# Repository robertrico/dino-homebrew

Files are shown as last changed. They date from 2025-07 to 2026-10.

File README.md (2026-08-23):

# DINO

**D**iscrete **I**ntegrated **N**ISC **O**perator — an 8-bit CPU built from
74-series logic on breadboards. That's the machine itself: no
microcontroller, no FPGA. Every register, every bus, every gate is a chip
you can put a probe on. (The repo does carry a generated FPGA twin for
design-ahead — see `fpga/`.)

Schematics in KiCad, microcode in EEPROM, and a bare-metal ATmega2560 test
rig that brings the machine up one board at a time.

**Status: IT RUNS.** All ten modules and all five integration blocks are
bench-proven, and the machine executes programs at full speed off its own
1.024MHz crystal. The milestone:

```asm
LDAI 0xFF   ; poison OB — destroy the previous answer first
OUT
LDAI 0x2F   ; A = 0x2F
LDBI 0x1E   ; B = 0x1E
ADD         ; A = A + B
OUT         ; LEDs show 0x4D
HALT
```

And it is no longer limited to what is burned into the ROM. `IN` reads the
DIP switches onto the bus, so an operand comes off the bench:

```asm
LDAI 0x2F   ; one addend from ROM
IN          ; the other from SW1
ADD
OUT         ; 0x2F + 0x01 = 0x30, 0x2F + 0x1E = 0x4D
HALT
```

Timing is retired: it free-runs, and "works single-stepped, fails
free-run" never appeared.

**The whole ISA executed on hardware on 2026-08-04** — every coverage image
produced its expected byte on the LEDs. `LDA`, `STA`, `JMP`, `JNZ` and seven
of the eight ALU codes had been burned and policed since the ROMs were first
written and had never once run.

**A stack pointer and a third microcode EEPROM exist in schematic and
simulation as of 2026-08-11** — twelve chips and seven instructions
(`LXISP`, `CALL`, `RET`, `PUSHA/POPA/PUSHB/POPB`), verified in the FPGA twin
and in the Python oracle, **not yet on silicon**. That is the next bench
session. After it: a 16550 UART, then a proto-Monitor.

---

## The part worth reading about

Building a CPU from discrete logic is a known exercise. The interesting
problem is different: **on a breadboard, with 60+ chips and a thousand
jumpers, how do you know the machine you built is the machine you drew?**

The answer here is four layers, each catching what the one before it
cannot:

```
schematic  ──▶  netlist audit  ──▶  generated contracts  ──▶  bench test
 (KiCad)        (gate equations       (pinmaps, ROM images,     (ATmega2560
                 extracted, not        expect models — all       drives real
                 eyeballed)            emitted from the          silicon and
                                       netlist)                  compares)
```

The rule underneath it: **nothing is retyped.** Every table in this repo —
pin assignments, the microcode ROM, the program ROM, the breadboard slot
maps, the wiring guides — is generated from the KiCad netlist by a script
with its own host tests. A schematic change propagates automatically. A
hand-maintained table would drift the moment someone moved a wire, and
drift is invisible until it costs you an evening.

Every test assertion is **netlist-verified before it is written**. Reading
a schematic and typing what you think a gate does is how you write a test
that agrees with your misunderstanding.

### Rules that were paid for on the bench

Each of these exists because something went wrong first:

- **Mirror-witness.** A write-then-read through the same bus bank is
  permutation-blind — a flipped jumper bank cancels itself out. Every
  module needs at least one asymmetric path. This is what finally caught a
  reversed PORTF→MDR bank that every round-trip test had passed.
- **Phantom power.** The rig's driven lines feed the DUT's VCC through
  input clamp diodes, so an unpowered CMOS board reads perfectly fine.
  A deliberate power-off run once scored 7/10. Every module now has a
  `power` test that runs first and holds the rig's outputs at the level
  that sources no current.
- **As-built freeze.** Once a breadboard strip is populated, its slot map
  is copper. Read it off the board and record it verbatim; never renumber
  a strip someone is wiring to.
- **No blind counters.** A failing assertion must print enough detail to
  name the lying signal, or the test is just a rumour.

### Faults this method actually caught

Not hypotheticals — these came off the bench, most diagnosed from serial
logs alone without a scope:

| Fault | How it was found |
|---|---|
| `U18.1` (OE) on `MDR_OUT` instead of `~MDR_OUT` | enable polarity inverted; cascaded into four failing tests until bus-fight analysis fingered it |
| PORTF→MDR jumper bank reversed | invisible to every A/B/C round trip, caught only by the asymmetric OUT-register path |
| `MDR5`↔`MDR6` crossed | decoded from byte 0 arithmetic alone: `0xA5 → 0xC5` is exactly a bit-5/6 exchange |
| Bridge DIR/EN keyed on destination instead of source | schematic bug — ADD could never have committed. Found by netlist audit before the board existed |
| Missing common ground | the all-float scan; first bench rule in action |
| `A8`-`A11` address rotation on the microcode ROM | the address-order test named every rotated line |

The last one matters most: **it was found on paper.** A netlist audit
caught a bridge defect that would have made the milestone program
impossible, before a single wire was cut.

---

## The machine

**8-bit data, 16-bit address.** Microcoded control: a **24-bit control word**
per T-state, stored in **three** EEPROMs addressed by `opcode << 4 | T`.

```
CW23:16  third ROM — bank selects, and room to grow
         CW17 SRC bank   CW18 DST bank   CW19 MISC bank

CW15  HALT           CW11:9   ALU op select (SA2:SA0)
CW14  PC_MAR_MUX     CW8:6    MISC   -> '138  bank 0: PC_CLEAR, PC_LOAD,
CW13  PC_UP                           COND, MDR_OUT, REG_OUT_LOAD,
CW12  END                             SP_UP, SP_DOWN
                     CW5:3    SRC    -> '138  bank 0: ROM, RAM, REG_A/B/C,
                                       ALU, SW
                                       bank 1: SP_LO/HI, PC_LO/HI
                     CW2:0    DST    -> '138  bank 0: REG_A/B/C, MAR_LO/HI,
                                       IR, RAM    bank 1: SP_LO/HI
```

The word was 16 bits and full — `SA(3) + MISC(3) + SRC(3) + DST(3) + END +
PC_UP + MUX + HALT` with two spare MISC codes and nothing else. The third
EEPROM buys bank-select bits rather than a wider field, so **every previously
burned row keeps its meaning**: bank 0 decodes exactly as before.

Instruction set: immediate loads, memory load/store, unconditional and
zero-conditional jumps, eight ALU operations on a '382 pair, an output port,
a switch input, a 16-bit stack pointer with `CALL`/`RET` and push/pop, and
`HALT` at `0xFF` so an erased EEPROM halts instead of raving.

**Adding an instruction costs a three-ROM burn** — a new opcode writes rows
in every byte of the word. Image CRCs are pinned as literals in
`test_microcode_gen.py`, so a reburn is always deliberate.

**Memory:** 32K program ROM and 32K RAM, split at `0x8000`.

**Commit discipline:** everything that changes state is clock-qualified and
commits while the clock is low — register loads through `NOR(~LOAD, CLK)`,
the RAM write pulse through `NAND(WRITE_DIR, ~CLK)`, PC load, clear and
count each gated independently. The consequence is useful: the microcode
ROM's access-time glitch cannot reach anything that holds state, so a
decode glitch here is a power-supply question, never a correctness one.

---

## Layout

```
dino_v0_0_2/          KiCad schematics, one sheet per module
docs/notes/           generators + design notes (see below)
roms/                 the burned EEPROM images — what is in the sockets
fpga/                 the generated VHDL twin, TTL models, cocotb, synthesis
tests/dino_bringup/   the ATmega2560 bring-up rig (bare-metal C)
datasheets/           74-series and memory parts
```

Everything in `docs/notes` that ends in `.py` emits something, and has a
`test_*.py` beside it:

| Script | Emits |
|---|---|
| `kicad_netlist.py` | `build_report()` — the netlist oracle everything else asks |
| `kicad_contracts.py` | per-sheet contracts, pin map, `--continuity` landing lists, `--since` change lists |
| `microcode_gen.py` | the three microcode ROM images, CRCs, expect header |
| `progrom_gen.py` | program ROMs, coverage images, and the Python oracle |
| `roms_readme_gen.py` | `roms/README.md` — the inventory read at the burner |
| `layout_gen.py` | breadboard placement, slot maps, colour-coded wiring guides |
| `fpga_gen.py` | schematic → VHDL, plus simulation hex images |
| `fuzz_gen.py` | differential fuzz seeds, VHDL twin vs the Python oracle |
| `coverage_lint.py` | asserts every contract signal is covered by a testbench |

---

## The FPGA twin

`fpga_gen.py` emits VHDL from the same netlist — `fpga/gen/*.vhd`, never
hand-edited — reproducing the schematic gate for gate, on top of behavioural
models of the actual parts (`fpga/ttl/ttl_74ls373.vhd`, `ttl_74f382.vhd`,
`ttl_at28c256.vhd`, …).

```bash
make -C fpga verify      # ~148s: host suite, differential fuzz, cocotb ladder
```

Every image tag synthesises, places, routes and closes timing on a Lattice
ECP5-5G Versa. `docs/notes/dino_fpga_vplan.md` is the coverage map: 92 rows,
each mapping a claimed invariant to the artifact that would **fail** if it
were wrong, with five gaps named as gaps.

**It cannot see** analog levels, real propagation on breadboard wire,
fan-out, or whether a wire was landed. Those are bench questions and always
will be. The breadboard machine is the machine; the twin is design-ahead.

---

## The bring-up rig

**The rig is currently detached and unwired** — it brought the machine up
board by board and shed its wires as each block was proven, which was always
the plan. Bench verification is now continuity against the generated crossing
list, TL866 read-back, and the coverage images' answers on the LEDs. What
follows is how it works when it is connected.

One firmware image, every test compiled in, selected at runtime over a
serial shell. The rig is stimulus, clock, and analyser.

```
list                  every test, grouped by module
run all               everything wired
run alu               one module
run alu.flags         one test
pins alu              the complete jumper table for that module
```

`pins <module>` **is** the hookup list — it prints from the same generated
tables the firmware resolves at runtime, so the paper and the code cannot
disagree.

### Build

```bash
cd tests/dino_bringup
source env.sh
build && flash && monitor      # avr-gcc, avrdude, screen @115200
```

### Test

```bash
make -C fpga verify                    # everything: host suite, fuzz, cocotb
make -C tests/dino_bringup/hosttest    # C model tests, no hardware needed
```

Individual generators self-test standalone, **run from the repo root** — they
resolve `roms/` relative to themselves, so `cd docs/notes` first and they
will not find it:

```bash
for t in docs/notes/test_*.py; do python3 "$t"; done
python3 docs/notes/coverage_lint.py
```

A few (`test_fpga_gen`, `test_vplan`, `test_netlist_integrity`) need `pytest`
and `cocotb`; `make -C fpga verify` runs them in the project venv.

The C expect models (`*_expect.h`) contain no AVR headers on purpose — the
same logic the rig asserts against is exhaustively tested on the host
first, red before green, long before a board is wired.

---

## How it was brought up

The integration ladder, control unit first, with the rig shedding wires at
every step until it was only watching. **All five blocks were bench-proven by
2026-08-02**; the counts below are current and include the stack sheet:

```
BLOCK             ADDS                          DRIVEN  SAMPLED
BLOCK 1   root + microcode + control_word          8       39
BLOCK 2   + pc + mar + memory                      8       31
BLOCK 3   + mdr        (real IR — it fetches)      0       15
BLOCK 4   + registers + alu + stack                0       15
BLOCK 5   + io                                     0       15
```

The ordering is not arbitrary. Every rig wire is a wire that can be one hole
off, so fewer rig wires means fewer rig-introduced faults — and the control
unit has the highest fan-out in the machine, which makes a rig standing in
for it the most dangerous harness the project could build. Make it real first
and that harness never exists. Driven hits zero at Block 3, when the real
instruction register takes over the fetch.

Blocks are **black-box** tests: a signal is sampled only if its value depends
on more than one board in the block. Anything one module already determines
is retired to that module's test, and anything produced inside the block and
consumed inside it is copper the rig never touches.

Nothing is ever pulled — no chip leaves its socket and the crystal stays
seated throughout — so the rig never owns the clock and every block runs free
at 1.024MHz, captured in bursts rather than single-stepped.

### The blind spot that cost a day

That last sentence contains the flaw. **Copper is driven by no test and
sampled by no test.** A module test drives those nets from the rig's own
pins, so the board-to-board run is never needed and cannot fail; the block
ladder classifies them as copper and never looks. **The wire between two
proven modules was checked by nothing.**

Two runs — nine wires — turned out never to have been landed at all, and
every element around them measured perfectly correct the entire time. The
fix is generated, not remembered:

```bash
python3 docs/notes/kicad_contracts.py --continuity U63 U64 U65 U66 ...
python3 docs/notes/kicad_contracts.py --since HEAD~1
```

The first prints every pin a named chip needs landed. The second prints what
changed, classified — and it is not optional, because the continuity walk
filters to nets touching the *new* chips, so a lifted strap on an existing
pin is invisible to it. Two blind spots in that tool itself were found and
regression-tested in `test_continuity_completeness.py`; one of them had been
dropping the ROM chip-enable from every checklist ever produced.

## What is left

```
land the stack   73 nets, 154 pins, plus 6 copper changes and 2 new wires
burn three ROMs  U9, U15, U23
PROG_sp          SP alone — LXISP and the counter, no CALL/RET
PROG_stack       push/pop, LIFO order observable
then             CALL/RET on hardware, a 16550 UART, a proto-Monitor
```

Bench procedure, per-stage wiring, failure meanings, and the full
integration plan live out of tree with the rest of the process documents
(maintainer's `.git/sdd/`).

---

*Schematic PDF: [`dino_v0_0_2/dino_v0_0_2.pdf`](dino_v0_0_2/dino_v0_0_2.pdf)*

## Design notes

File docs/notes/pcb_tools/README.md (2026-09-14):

# pcb_tools — the placer scripts from the 2026-09-12 layout session

Promoted verbatim from a session scratchpad on 2026-09-14 so the DMA/INT
re-shuffle has them. **Throwaway quality: no tests, absolute paths,
constants hard-coded for the 77-DIP / 14-column / 6-row board.** Read
`.git/sdd/PCB_LAYOUT.md` RESULTS R2 and `.git/sdd/TO_PCB.md` (volume
checkout) before running any of them. They only READ `.kicad_pcb`;
placements are applied through Konnect `set_component_placements`.

    anneal.py  <out.json> [seed]   simulated annealing over DIP cell
                                   assignment; cost = HPWL with CLK x6,
                                   ~CLK x4, CLK_B x6, Y1->U20 x6, RC x5.
                                   `ROWH`, `cells`, `chips==77` assert and
                                   the fixed-part table need editing for
                                   a board with U80-U99 added.
    hpwl.py    <pcb> [n]           per-net HPWL of the SAVED board, worst n
    report.py  <placements.json>   CLK/RST/PC6 spans + courtyard overlaps
                                   for a placements file before applying
    place_sheetrows.py             the FIRST placer (sheet rows). Superseded
                                   by anneal.py; kept for the cap-pairing
                                   and front-panel geometry it encodes.

Pipeline: anneal -> report -> Konnect set_component_placements ->
score_placement -> docs/notes/test_pcb_envelope.py -> pcbnew DSN export
-> Freerouting -> KiCad SES import -> hairpin sweep -> pours -> DRC.

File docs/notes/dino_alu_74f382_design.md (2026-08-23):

# DINO ALU hardware: 2x 74F382 design notes

Machine: DINO v0.0.3, `dino_v0_0_2/alu.kicad_sch`
Status: **BUILT AND BENCH-PROVEN.** Architecture converged 2026-07-13
(shadow-register operands, Rico's design); drawn, wired, and all eight SA
codes executed on hardware 2026-08-04 via `PROG_alu` (OB 0x39). This document
is the DESIGN RECORD for how it got that way, kept so the rejected
alternatives never get re-litigated from scratch.

Companion still in tree: `dino_design_notes.md` (the operand-architecture
decision record). `dino_121_elimination_plan.md` and
`dino_register_conversion.md` are process documents and live out of tree in
`.git/sdd/`.

---

## 0. Architecture summary

Two 74F382 4-bit ALU slices cascade to 8 bits. Operands come from two SHADOW
REGISTERS on this sheet — TMP_A and TMP_B, '373s whose D pins listen on the
W bus and whose latch enables fire on the same decodes as REG_A and REG_B.
Every dst=A state loads A and TMP_A identically; TMP_x ≡ REG_x by
construction. The F382s read the shadows point-to-point (Q → ports, one
driver, one listener, no buffers). The register boards are untouched and the
ALU adds no cross-board operand wiring: everything rides the W bus backbone.

An ALU instruction is one execute state: select the function, output latch
freezes the result at the mid-state falling edge, destination (and its
shadow) capture on the closing edge. No staging states, no control codes
spent on the shadows.

History (see design_notes for full rationale): dedicated always-driven taps
rejected (required tearing up verified register topology + 16 cross-board
wires); 8008-style microcode-addressable temps rejected (2 staging states +
both free [8:6] codes). Shadows take the best of both.

## 1. The function table ([11:9], constitution-final)

DATASHEET READING TRAP: the '382 select table prints columns S0, S1, S2
left-to-right - LSB FIRST. Read carefully. Also old notation: A(+)B circled
is XOR; "A + B" in the logic rows is OR; "A Plus B" spelled out is ADD; AB is AND.

Corrected mapping, written S2:S1:S0 as the control word holds it:

    [11:9]  S2 S1 S0   op              instruction
     000     L  L  L   Clear           CLR   A = 0x00   (free)
     001     L  L  H   B minus A       BSUB  A = B - A  (free)
     010     L  H  L   A minus B       SUB   A = A - B
     011     L  H  H   A plus B        ADD   A = A + B
     100     H  L  L   A XOR B         XOR
     101     H  L  H   A OR B          OR
     110     H  H  L   A AND B         AND
     111     H  H  H   Preset          SET   A = 0xFF   (free)

("A" and "B" here mean TMP_A and TMP_B — identical to REG_A/REG_B by the
shadow invariant.)

Casualties from the old paper table: DISABLED (the '382 has no disabled
state; S=000 computes zero - "ALU quiet" is the output latch's job), PASS
(no such '382 function; src=REG_A covers it), COND (relocated to [8:6]=011).

WIRING: control word bit 11 -> S2, bit 10 -> S1, bit 9 -> S0, both slices in
parallel. A swapped select line maps every op to a DIFFERENT VALID OP - the
nastiest miswire class. See section 7 test 1 for the disambiguator.

## 2. Shadow registers TMP_A, TMP_B (the operand source)

    TMP_A 74LS373
      D0-D7   = W bus, direct (inputs are listeners — no buffer needed;
                IR does exactly this on the verified MDR/IR sheet)
      Q0-Q7   = F382 A ports (low slice bits 0-3, high slice 4-7),
                point-to-point wires, OE = GND
      LE      = NOR(/REG_A_LOAD, CLK) — own stamp gate on this sheet,
                same input NETS as the register board's LE_A stamp
    TMP_B: identical, /REG_B_LOAD, F382 B ports.

SHADOW INVARIANT: TMP_x captures on EVERY dst=x state including ALU
writebacks (A and TMP_A latch the same frozen W on the same edge). Chained
arithmetic depends on this — a shadow that skipped writebacks would feed
the next SUB stale operands. Both registers are garbage before the first
load, same as v0.0.2 semantics; microcode loads before it computes.

Trade accepted: the ALU computes on A,B only. Any-pair ops (ADD B,C) are a
MOV-through idiom in microcode. Accumulator-machine standard.

## 3. Cascading two slices

- Low slice: bits 0-3 of TMP_A, TMP_B, F. High slice: bits 4-7.
- Low slice Cn+4 (ripple carry out) -> high slice Cn.
- High slice Cn+4 -> C input of the flags '173 (section 5).
- High slice OVR = signed overflow (V flag) - free; route it somewhere
  probeable now, unreachable after layout.
- Low slice Cn = carry-in for the whole 8-bit ALU (section 4).
- F-family speed: ~15ns full 8-bit result. The EEPROMs own the ceiling.
- F inputs are TTL-compatible with LS drivers; keep F-to-latch traces short.

## 4. Carry-in (Cn) - op-dependent, not optional

The '382 computes subtraction as A + /B + Cn. Therefore:
    SUB (010) and BSUB (001) REQUIRE Cn = 1; ADD (011) wants Cn = 0;
    logic ops ignore Cn.

    Cn = XOR(S1, S0) = XOR(bit10, bit9)

Check: 001 -> 1 ok. 010 -> 1 ok. 011 -> 0 ok. Logic rows: don't-care.
Hardware: one XOR — 4x NAND spares or a new '86 (spares useful for flags).
Wire to LOW slice Cn only; high slice Cn comes from the cascade.
FUTURE parking: ADC/SBC = mux stored C into Cn. Only if multi-byte speed
ever matters.

## 5. Flags register ('173, falling-edge capture)

    C <- high slice Cn+4;  Z <- NOR8 of F382 F pins;  V <- OVR (free bit)

    74LS173: CP = /CLK (rising of /CLK = mid-state falling edge of CLK),
    /IE = /ALU_OUT, output OEs grounded (flags feed dedicated COND logic).

WHY THE FALLING EDGE: in the second half of an ALU state TMP_A goes
transparent (it shadows dst=A) and the F382 recomputes ~40ns later — C/V go
stale. At the falling edge the F pins still reflect old operands (the value
being committed). Setup: F settled ~200ns into the first half. Hold: ~40ns
before F can move vs ~10ns required.

CAPTURE RULE: flags capture ONLY when src=ALU, ON the falling edge. With no
DISABLED code the S pins always compute something; ungated capture would
clobber Z between SUB and JNZ. Constitution header: "ALU ops (src=ALU
states) update Z and C (and V if wired) at the falling edge; nothing else
touches flags."

Z-detect gate choice still open: 'LS260+gate, 2x 'LS25+AND, or 'LS30 games.
Pick by spares; record here: ____________

## 6. Output latch (the ALU sheet's only bus driver)

'382 F outputs have no tri-state; a buffer was always required. It is a
74LS373 — buffer + the master latch that breaks the writeback loop:

    D = F[7:0];  LE = CLK, DIRECT (zero gates);  Q = W bus
    /OE = /ALU_OUT ([5:3]=110, U28 — verify designator/pin on control
          sheet and record: ____________)

Transparent the whole first half (tracks F while shadows are stable),
freezes at the falling edge, holds through the second half while the
destination AND its shadow track the frozen value.

MASTER/SLAVE INVARIANT: output latch transparent iff CLK HIGH; every
destination latch (registers and shadows) transparent iff CLK LOW; never
both. During ADD's second half, TMP_A tracks the frozen W, the F382
recomputes from new TMP_A, and hits this closed latch. The loop always
contains one closed door. In non-ALU states the latch captures whatever
[11:9] computes behind a disabled /OE - ripple nobody samples.

MICROCODE IMPACT: none. ADD = T0 (0x600E) + T1 (0x1631). Timing rule: ALU
result must settle by the FALLING edge — '163 (~14) + EEPROM (~150) + F382
(~15) + latch (~18) ≈ 200ns vs 500ns half-period at 1MHz.

## 7. Bring-up test plan (jumper-driven, no microcode EEPROM required)

Fixture: force TMP_A/TMP_B via the W-bus switch rig + manual stamp inputs
(or DIP switches on the shadow D nets), LEDs on W bus, S pins jumpered.
For tests 1-5, hold CLK HIGH so the output latch is transparent.

1. DIRECTION ANCHORS FIRST: S=000 -> W reads 0x00; S=111 -> 0xFF. Catches
   swapped or stuck select lines before any arithmetic is trusted.
2. ADD: 0x05+0x03 -> 0x08. Then 0xFF+0x01 -> 0x00 with C set (cascade and
   carry capture in one shot).
3. SUB: 0x05-0x03 -> 0x02; RECORD observed carry polarity on subtract
   (/borrow expected) and define JC semantics in the constitution: ________
4. BSUB: same operands -> 0xFE.
5. XOR/OR/AND: one vector each, e.g. A=0xAA B=0x0F -> 0xA5 / 0xAF / 0x0A.
6. Z FLAG: a zero result sets Z; nonzero clears; Z must NOT change when
   src != ALU (capture gate working).
7. LATCH HALVES: /ALU_OUT=0. CLK high: wiggle operands -> W follows.
   CLK low: wiggle -> W FROZEN. Master/slave on two probes.
8. SHADOW INVARIANT: wire to the real register boards; run LDAI, ADD, LDA
   sequences single-stepped; probe TMP_A vs REG_A after every edge — always
   equal after any dst=A state, INCLUDING the ADD writeback.
9. FEEDBACK SAFETY: single-step ADD with B=1 — A increments by EXACTLY 1
   per state. A jump >1 means a transparent path survived.
10. FLAGS EDGE: flags move only on falling edges of src=ALU states.

## 8. Open questions (decide before drawing the sheet)

1. RESOLVED (drawn, netlist-audited 2026-07-13): Z-detect is NOT '260/'25/'30
   — no '260 in stock. Built from De Morgan identity using ONLY 2-input
   gates already on the sheet: NOT(x1|x2|x3|x4) = NOR(x1,x2) AND NOR(x3,x4).
   U52 (quad '02): F01=NOR(F0,F1), F23=NOR(F2,F3), F45=NOR(F4,F5),
   F67=NOR(F6,F7) — all 4 gates used. U53 (quad '08): F0123=AND(F01,F23),
   F4567=AND(F45,F67), Z=AND(F0123,F4567) — 3 of 4 gates used, 1 spare.
2. RESOLVED: flags storage is '273, NOT '173 — no '173 in stock. '273 has
   no load-enable pins (unlike '173's M/N), so a 74LS157 (quad 2:1 mux, U48)
   sits ahead of the D inputs: I0=new flag value, I1=Q fed back to itself,
   S=/ALU_OUT direct (active-low S selects I0 during a real commit — no
   inverter needed, get the I0/I1 assignment backwards and flags freeze on
   every IDLE cycle instead of every ALU cycle). CP=/CLK (unchanged reasoning
   from below), Mr=/RESET (74LS273 has async active-low clear — a genuine
   upgrade over '173, costs nothing). V flag wired (FLAG_V, ALU_V from high
   slice OVR) — yes, wired now, per the original "free if wired now" note.
3. SUB borrow polarity -> JC/JNC semantics (section 7 test 3) — still open,
   needs bench observation, unchanged.
4. Output latch part SETTLED ('373); /ALU_OUT designator = U47's /OE,
   confirmed on the drawn sheet.
5. RESOLVED: Cn is NOT built from XOR/'86 — turns out you don't need XOR at
   all. Required truth table only constrains 3 of 4 (SA1,SA0) pairs (CLR is
   don't-care, Cn doesn't touch a clear op), and NAND(SA1,SA0) satisfies all
   three (BSUB=1, SUB=1, ADD=0) — XOR and NAND only differ at (0,0), which is
   exactly the don't-care slot. Built from a spare AND gate (U53, 4th gate,
   pins 12/13->11, was dead/grounded) feeding a spare NOR-as-inverter (U50,
   4th gate, pins 11/12 tied together ->13) — zero new chips. Net:
   ALU_CIN = NOR(AND(SA1,SA0), AND(SA1,SA0)) = NAND(SA1,SA0).
6. Do BSUB/CLR/SET earn opcodes in v0.0.3, or stay documented-but-unassigned?
   Still open — not touched this session; the control word's [11:9] field
   wires straight to SA[2:0] either way, so this is a microcode-assignment
   decision, not a hardware one.

Full pin-level wiring for all of the above: see dino_session_state.md,
"ALU sheet (COMPLETE)".

---

Sequencing: register boards get stamps + '08 (small diff, conversion doc §2),
then this sheet gets drawn — 2x F382, TMP_A, TMP_B, output latch, flags '173,
Cn XOR, Z-NOR — and the machine can ADD TWO NUMBERS AND SHOW THEM, one bench
session from the countdown demo.

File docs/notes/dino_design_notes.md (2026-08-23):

# DINO design notes: deferred decisions and settled philosophy

Running notes for decisions that are settled in principle but not yet (or not
ever) implemented in hardware — kept so the rejected alternatives never get
re-litigated from scratch. Some entries here HAVE since been built; each says
so. Companion to `dino_alu_74f382_design.md` and, out of tree, `.git/sdd/`.

---

## ALU operand architecture (FINAL 2026-07-13): shadow registers

Three candidates were worked through in conversation; recording all three so
this never gets re-litigated from scratch.

REJECTED — dedicated taps ("spatial"): ground register OEs so A Bus/B Bus are
always driven, ALU taps them point-to-point. Sound, but tears up the verified
v0.0.2 register topology (D pins move to the W bus, '245s become one-way) and
strings ~16 operand wires across boards. Died on: rewiring cost + mental-model
mismatch.

REJECTED — microcode-addressable temps ("temporal", pure 8008): TMP_A/TMP_B
loaded by explicit microcode via the two free [8:6] codes. Registers keep
v0.0.2 wiring; feedback hazard vanishes; any-pair ALU ops. Died on: 2 staging
states per ALU op AND spending both free misc codes — the last expansion room
in that field.

ADOPTED — SHADOW REGISTERS (Rico's synthesis): TMP_A/TMP_B '373s on the ALU
sheet, D pins listening on the W bus, latch enables fired by the SAME
/REG_A_LOAD//REG_B_LOAD decodes as the real registers. Every dst=A state
loads A and TMP_A with the same value on the same edge: TMP_x ≡ REG_x by
construction. Zero control codes, zero staging states, zero register-board
rewiring, no cross-board operand wires (everything rides the W bus backbone).

INVARIANT (do not "optimize"): shadows capture on EVERY dst=x state INCLUDING
ALU writebacks. A shadow that skipped writebacks goes stale and breaks chained
arithmetic (countdown loop: SUB;JNZ;SUB must see current A). Both real and
shadow are garbage before first load — same as v0.0.2 semantics.

Feedback safety: during an ALU writeback's second half TMP_A is transparent
and feeds the F382 — the loop is broken by the ALU OUTPUT LATCH (LE=CLK,
master/slave), not by the shadows. The output latch was required anyway as
the '382s' bus buffer.

Trade accepted: ALU computes on A,B only; ADD B,C = MOV-through idiom.
Revisit trigger: if register pressure makes MOV-through painful (monitor/
toolchain era), the temporal design's staging codes are the upgrade path —
and by then a third parallel EEPROM (control word +8 bits, same addresses)
is a reasonable ask.

## Illegal microword defense (settled 2026-07-12, revisit at monitor/toolchain era)

The two-field encoding leaves one expressible-but-illegal class: src and dst naming
the same device. Register self-copy (src=REG_x, dst=REG_x) is benign - a wasteful
NOP, A=A (the '245 turns around, the latch recaptures its own value; shadows
recapture identically). RAM self-copy (src=RAM_OUT, dst=RAM_LOAD) is a REAL
corruption: /WE dominates /OE on SRAM, the chip stops driving mid-state, and the
write commits whatever the abandoned bus floats to. Garbage written to [MAR].

SECOND expressible-but-illegal class (caught 2026-07-12, Rico's contention
review of the '245 fleet): the six W-bus source enables (/ROM_OUT, /RAM_OUT,
/REG_A/B/C_OUT, /ALU_OUT) all come from U28 - one-hot by silicon, two W-bus
drivers UNREPRESENTABLE within the src field. But /MDR_OUT (replay) lives on
U29, the misc-field '138. A word asserting [8:6]=100 (/MDR_OUT) together with
any [5:3] != NONE puts TWO drivers on the W bus. The silicon cannot exclude
it; the builder must (assert below). Same defense philosophy: the only
source of such a word is EEPROM contents.

Considered and REJECTED: hardware interlock (e.g. OR-ing a detected illegal state
into HALT). Reasons:
- The detector would watch decode lines whose ripple the whole design is built to
  ignore; a level-family signal feeding the clock stop mixes the edge/level
  categories and creates a new false-halt failure mode.
- The only source of an illegal word is EEPROM contents; the builder already
  refuses to emit one. Hardware would defend against corrupted burns only, and
  burn verification (programmer readback) covers that directly.
- A flipped bit in a LEGAL row (ADD becomes OR) is undetectable by any interlock
  anyway - the defense has to live upstream of the silicon regardless.

ADOPTED: four layers, zero gates, each defense where it is cheapest:
1. STRUCTURE  - field encoding: bus fights unrepresentable.
2. POLICY     - C microcode builder asserts (list below).
3. RECOVERY   - safe-fill: every unwritten microcode row = NOP+END (0x1000),
                so any runaway lands on a fetch within one state.
4. VERIFICATION - Arduino contract tests per sheet; EEPROM burn readback/verify
                every burn.

Revisit trigger: when the toolchain era arrives (assembler, monitor, self-hosted
EEPROM writes), the POLICY layer moves partly into those tools - the monitor's
EEPROM-write path should enforce the same asserts as the offline builder, or
self-hosted microcode updates lose layer 2.

## Builder assert list (grows as the constitution grows)

- src device == dst device -> ERROR (RAM case corrupts; register case pointless)
- src == REG_x AND dst == same REG_x -> WARNING (probable MOV typo)
- [8:6] == /MDR_OUT AND [5:3] != NONE -> ERROR (two W-bus drivers: replay
  path enables MDR's OE from U29, outside the U28 one-hot guarantee)
- PC_UP AND PC_LOAD same word -> ERROR (defined-but-fragile on '193 internals)
- opcode block with no END before T15 -> ERROR (instruction runs into safe-fill)
- total PC_UP count per instruction != instruction byte length -> WARNING
  (catches operand-skip / double-fetch bugs at build time)
- any word asserting IR_LOAD outside T0 -> ERROR (IR changes only at fetch)
- T0 row of every opcode != universal fetch word 0x600E -> ERROR

## Deferred hardware, parking spaces reserved

- ADC/SBC: mux stored C flag into ALU Cn (replaces XOR-derived constant).
  Requires nothing else. Only if multi-byte arithmetic speed ever matters.
- MAR upgrade '373s -> '163s: buys MAR++ for indirect addressing era. Sheet
  layout should leave room. Would want a misc-field code or a third-EEPROM
  control bit for the count strobe.
- Indirect addressing: pointer-walk microcode with byte buffer (REG_C clobber,
  documented) or hidden temp '373. Hazard walk already done - see conversation
  notes 2026-07-11: last byte read must be first byte committed.
- IN port: '244/'541 from outside world onto W bus, source code [5:3]=111 (the
  reserved slot). Prerequisite for the monitor. When wired, its enable joins
  the U28 one-hot family - structurally safe, no new assert needed.
- COND qualifier gate: [8:6]=011 decode gates PC_LOAD (and optionally END) on
  selected flag. Flag-select encoding not yet designed - decide when JNZ is
  wired whether Z-only suffices for v0.0.3 (it does for the countdown demo).
- Third parallel EEPROM: +8 control word bits on the same address lines —
  the standing relief valve if [8:6] ever fills (monitor strobes, MAR++,
  flag-select).

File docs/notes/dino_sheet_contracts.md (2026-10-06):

# DINO sheet-to-sheet contracts

Generated by docs/notes/kicad_contracts.py — regenerate after any
schematic change; do not hand-edit. Direction is derived from pin
types: OUT(tri) means drives-when-enabled (a tri-state bus driver).

## root
- IN    END_OR_ACCEPT  <- Interrupt
- IN    CW15=HALT  <- Microcode_Decoder
- OUT   CLK  -> ALU Module, Control Word Module, Interrupt, Memory, Memory Address Regiser, Memory Data Register, Program Counter, Register Modules, Stack Pointer
- OUT   ~{RESET}  -> ALU Module, Interrupt
- OUT   ~{CLK}  -> ALU Module, Interrupt, Memory Data Register, Peripheral Bus, Program Counter
- OUT   ~{TO0}  -> Control Word Module
- OUT   RESET  -> Memory, Program Counter
- OUT   T0-3  -> Microcode_Decoder

## ALU Module
- IN    ~{ALU_OUT}, ~{REG_A_LOAD}, ~{REG_B_LOAD}  <- Control Word Module
- IN    FLAG_D0-3  <- Interrupt
- IN    CLK_ALU  <- Memory Data Register
- IN    CW10=SA1, CW11=SA0, CW16=~{CIN_SEL}, CW21=FLAG_SEL0, CW9=SA2  <- Microcode_Decoder
- IN    CLK, ~{CLK}, ~{RESET}  <- root
- OUT   COND_FLAG  -> Control Word Module
- OUT   FLAG_C, FLAG_N, FLAG_NEXT0-3, FLAG_V, FLAG_Z  -> Interrupt
- BIDIR W0-3  <-> Front Panel, Interrupt, Memory Address Regiser, Memory Data Register, Peripheral Bus
- BIDIR W4-7  <-> Front Panel, Memory Address Regiser, Memory Data Register, Peripheral Bus

## Control Word Module
- IN    COND_FLAG  <- ALU Module
- IN    INJECT  <- Interrupt
- IN    CW0-8, CW17=~{SRC_BANK}, CW18=~{DST_BANK}  <- Microcode_Decoder
- IN    CLK, ~{TO0}  <- root
- OUT   ~{ALU_OUT}  -> ALU Module, Memory Data Register
- OUT   ~{REG_A_LOAD}, ~{REG_B_LOAD}  -> ALU Module, Register Modules
- OUT   ~{FLAGS_LOAD}, ~{FLAGS_OUT}, ~{IE_CLR}, ~{IE_SET}, ~{KONST}  -> Interrupt
- OUT   WR_GATE  -> Memory
- OUT   ~{MAR_HI_LOAD}, ~{MAR_LO_LOAD}  -> Memory Address Regiser
- OUT   SRC_ACTIVE, ~{IR_LOAD}, ~{MDR_OUT}, ~{PC_HI_OUT}, ~{PC_LO_OUT}, ~{RAM_LOAD}, ~{RAM_OUT}, ~{ROM_OUT}  -> Memory Data Register
- OUT   ~{PC_CLEAR}, ~{PC_LOAD}  -> Program Counter
- OUT   ~{REG_A_OUT}, ~{REG_B_OUT}, ~{REG_C_LOAD}, ~{REG_C_OUT}, ~{REG_OUT_LOAD}  -> Register Modules
- OUT   ~{SP_DOWN}, ~{SP_HI_LOAD}, ~{SP_HI_OUT}, ~{SP_LO_LOAD}, ~{SP_LO_OUT}, ~{SP_UP}  -> Stack Pointer

## Front Panel
- IN    W0-7  <- ALU Module, Memory Data Register
- IN    OB0-7  <- Register Modules

## Interrupt
- IN    ~{IRQ}  <- 
- IN    FLAG_NEXT0-3  <- ALU Module
- IN    W0-3  <- ALU Module, Memory Data Register
- IN    ~{FLAGS_LOAD}, ~{FLAGS_OUT}, ~{IE_CLR}, ~{IE_SET}, ~{KONST}  <- Control Word Module
- IN    CW12=END, CW13=PC_UP, CW15=HALT  <- Microcode_Decoder
- IN    CLK, ~{CLK}, ~{RESET}  <- root
- OUT   FLAG_C, FLAG_D0-3, FLAG_N, FLAG_V, FLAG_Z  -> ALU Module
- OUT   INJECT  -> Control Word Module
- OUT   MDR0-7  -> Memory, Memory Data Register, Register Modules, Stack Pointer
- OUT   PC_UP_GATED  -> Program Counter
- OUT   END_OR_ACCEPT  -> root

## Memory Address Regiser
- IN    W0-7  <- ALU Module, Memory Data Register
- IN    ~{MAR_HI_LOAD}, ~{MAR_LO_LOAD}  <- Control Word Module
- IN    CW14=PC_MAR_MUX  <- Microcode_Decoder
- IN    CLK  <- root
- OUT   ~{RAM_EN}  -> Memory, Memory Data Register
- OUT   M0-14  -> Memory, Peripheral Bus, Program Counter
- OUT   ~{PC_MAR_MUX}  -> Program Counter
- BIDIR M15  <-> Memory, Peripheral Bus, Program Counter

## Memory Data Register
- IN    SRC_ACTIVE, ~{ALU_OUT}, ~{IR_LOAD}, ~{MDR_OUT}, ~{PC_HI_OUT}, ~{PC_LO_OUT}, ~{RAM_LOAD}, ~{RAM_OUT}, ~{ROM_OUT}  <- Control Word Module
- IN    ~{IO_RD}, ~{ROM_SEL}  <- Memory
- IN    ~{RAM_EN}  <- Memory Address Regiser
- IN    CLK, ~{CLK}  <- root
- OUT   CLK_ALU  -> ALU Module
- OUT   RAM_OE_ON, READS_IDLE, WRITE_DIR, ~{ROM_BUF_EN}  -> Memory
- OUT   IRB0-7  -> Microcode_Decoder
- OUT   PC0-15  -> Program Counter
- BIDIR W0-3  <-> ALU Module, Front Panel, Interrupt, Memory Address Regiser, Peripheral Bus
- BIDIR W4-7  <-> ALU Module, Front Panel, Memory Address Regiser, Peripheral Bus
- BIDIR MDR0-7  <-> Interrupt, Memory, Register Modules, Stack Pointer

## Memory
- IN    WR_GATE  <- Control Word Module
- IN    ~{RAM_EN}  <- Memory Address Regiser
- IN    M0-15  <- Memory Address Regiser, Program Counter
- IN    RAM_OE_ON, READS_IDLE, WRITE_DIR, ~{ROM_BUF_EN}  <- Memory Data Register
- IN    CLK, RESET  <- root
- OUT   MDR0-7  -> Interrupt, Memory Data Register, Register Modules, Stack Pointer
- OUT   ~{IO_RD}, ~{ROM_SEL}  -> Memory Data Register
- OUT   RESET_B, ~{IO_RD_Q}, ~{IO_SEL}, ~{IO_WR}  -> Peripheral Bus

## Microcode_Decoder
- IN    IRB0-7  <- Memory Data Register
- IN    T0-3  <- root
- OUT   CW10=SA1, CW11=SA0, CW16=~{CIN_SEL}, CW21=FLAG_SEL0, CW9=SA2  -> ALU Module
- OUT   CW0-8, CW17=~{SRC_BANK}, CW18=~{DST_BANK}  -> Control Word Module
- OUT   CW12=END, CW13=PC_UP  -> Interrupt
- OUT   CW15=HALT  -> Interrupt, root
- OUT   CW14=PC_MAR_MUX  -> Memory Address Regiser

## Peripheral Bus
- IN    ~{IRQ}  <- 
- IN    W0-7  <- ALU Module, Memory Data Register
- IN    RESET_B, ~{IO_RD_Q}, ~{IO_SEL}, ~{IO_WR}  <- Memory
- IN    M0-15  <- Memory Address Regiser, Program Counter
- IN    +12V, +3.3V, -12V  <- Power
- IN    ~{CLK}  <- root

## Power
- OUT   +12V, +3.3V, -12V  -> Peripheral Bus

## Program Counter
- IN    ~{PC_CLEAR}, ~{PC_LOAD}  <- Control Word Module
- IN    PC_UP_GATED  <- Interrupt
- IN    ~{PC_MAR_MUX}  <- Memory Address Regiser
- IN    CLK, RESET, ~{CLK}  <- root
- OUT   PC0-15  -> Memory Data Register
- OUT   M0-15  -> Memory, Memory Address Regiser, Peripheral Bus

## Register Modules
- IN    ~{REG_A_LOAD}, ~{REG_A_OUT}, ~{REG_B_LOAD}, ~{REG_B_OUT}, ~{REG_C_LOAD}, ~{REG_C_OUT}, ~{REG_OUT_LOAD}  <- Control Word Module
- IN    CLK  <- root
- OUT   OB0-7  -> Front Panel
- OUT   MDR0-7  -> Interrupt, Memory, Memory Data Register, Stack Pointer

## Stack Pointer
- IN    ~{SP_DOWN}, ~{SP_HI_LOAD}, ~{SP_HI_OUT}, ~{SP_LO_LOAD}, ~{SP_LO_OUT}, ~{SP_UP}  <- Control Word Module
- IN    CLK  <- root
- BIDIR MDR0-7  <-> Interrupt, Memory, Memory Data Register, Register Modules

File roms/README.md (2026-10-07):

# roms/ — what is physically in the sockets

**GENERATED by `docs/notes/roms_readme_gen.py`. Do not hand-edit.**
Regenerate after any image change; `test_roms_readme.py` fails on drift.

These binaries are TRACKED ON PURPOSE. They were silently untracked in the
old `hardware` repo, swallowed by a bare `*.bin` rule inherited from the MCU
firmware projects. Do not reintroduce that rule — see `.gitignore`.

They are regenerable, but regenerable is not recorded. "What was burned on
2026-07-26" should be a `git show`, not "check out an old commit, re-run the
generator, and hope OPCODES has not moved." Per-image history is deliberately
NOT repeated here — that is what `git log roms/` is for.

## Microcode — THREE chips

The control word is 24 bits wide and every image is the 4096-row table split
by byte. A12 is grounded, so each 8KB file is the 4096-byte image mirrored
twice; the CRCs below are over the 4096 ADDRESSABLE bytes.

**Adding or changing an INSTRUCTION means burning all three.** A new opcode
writes rows in every byte of the word. `U9`/`U15` stay untouched only for
changes confined to `CW16-23`.

    IMAGE            BITS      SET    CRC16
    U9.bin           CW0-7     REAL   0x4102
    U15.bin          CW8-15    REAL   0x9BC4
    U23.bin          CW16-23   REAL   0x8A40
    U9_diag.bin      CW0-7     DIAG   0x0F69
    U15_diag.bin     CW8-15    DIAG   0xF1B9
    U23_diag.bin     CW16-23   DIAG   0x56CC

## Program ROM (AT28C256, 32KB, ROM 0x0000-0x7FFF)

    IMAGE            CRC16   WHAT IT IS
    PROG.bin         0x8577  the milestone program
    PROG_diag.bin    0xDFE7  address self-proof, content-addressed

    milestone: LDAI 0xFF; OUT; LDAI 0x2F; LDBI 0x1E; ADD; OUT; HALT  -> OB = 0x4D
    The leading LDAI/OUT POISONS OB: U35 has no reset and the
    machine free-runs at power-up, so OB always already holds
    the previous answer. Safe-filled with HALT (0xFF).

## Progressive ISA-coverage images

The block ladder proves the machine EXECUTES. These prove it executes the
WHOLE of the current ISA. Each ends `OUT; HALT` because OB is the only
datapath observable on the ladder, and every answer is a MIRROR-WITNESS — its
bit-reversed read is a different byte, so a flipped OB ribbon names itself.

Expected OB values are NOT hand-computed. `progrom_gen.simulate()` interprets
the burned microcode rows, so image and hardware cannot disagree by
construction — no eleventh table.

    IMAGE            CRC16   OB    ENDS
    PROG_probe.bin   0x254E  0x39  2
        immediate -> A -> OB, ALU out of the path entirely. The smallest
        question worth asking.
    PROG_adda.bin    0xAC3D  0x39  4
        TMP_A alone: value + 0, so the answer IS the operand.
    PROG_addb.bin    0x8DAE  0x39  4
        TMP_B alone: 0 + value, isolating the other shadow latch.
    PROG_dip.bin     0xFEE3  0x4D  6   SW1 = 0x1E
        THE INTERACTIVE ONE, through the BUS. A comes off card zero at
        0x4000 with a plain LDA -- SW1 is an ADDRESS now, not a SRC code,
        and IN retired with U28.7. Only the SOURCE of the operand changed;
        the answer is still the milestone's 0x4D.
    PROG_alu.bin     0x642A  0x39  13
        all eight SA codes CHAINED, so a wrong code corrupts the signature
        rather than being masked by a later op.
    PROG_mem.bin     0x3E4B  0xC5  5
        STA then LDA back through RAM. Uses ONE address twice, so it is
        blind to what that address actually was -- see mardisc.
    PROG_flow.bin    0xCED0  0x39  7
        JMP over a poison HALT, then a JNZ that must NOT be taken.
    PROG_loop.bin    0x8727  0x15  33
        the JNZ TAKEN arm, iterated an exact number of times. A wrong
        count changes the answer, so the answer proves the count.
    PROG_mardisc.bin 0x2066  0x6B  8
        TWO DIFFERENT MAR values. Reads back the FIRST of two cells
        differing only in MAR_LO, so a collapsed low byte returns the
        SECOND value. The question mem cannot ask.
    PROG_pads.bin    0x749A  0x40  5
        the PC's LANDING ADDRESS as the observable. Every 4-byte slot is
        LDAI <own address>; OUT; HALT.
    PROG_sp1.bin     0x5F58  0x2C  5
        ONE push, ONE pop -- the fewest moving parts that reach the stack
        at all. BLIND TO A FROZEN SP by construction: push and pop use the
        same cell, so 0x2C comes back whether or not SP ever moved. It
        reported a green machine for most of 2026-08-24. Read it only
        alongside sp2.
    PROG_sp2.bin     0xFBA3  0x53  9
        the ADDRESS as the observable, not the data. Plants a sentinel in
        the cell push #2 must reach, then reads that cell by ABSOLUTE
        address so the readback cannot inherit the fault under test. 0x53
        = SP moved. 0xA5 = SP never moved and the sentinel survived. The
        first image that is not blind to a frozen SP.
    PROG_sp3.bin     0x76FF  0x2C  9
        WHICH cell did the pop read. A different sentinel in each
        neighbour: 0x2C correct, 0x11 read one BELOW (increment never took
        before the MAR copy), 0x22 read one ABOVE (increment landed
        twice). 0x22 is what a ringing CLK edge at U63.2 produced before
        the 100R series termination went in.
    PROG_sp.bin      0xC047  0x27  9
        SP alone -- LXISP and the counter, without CALL/RET. The phase-B
        bench gate.
    PROG_calladdr.bin 0x7D79  0x5C  15
        CALL WITHOUT RET. Reads the pushed return address back out of RAM
        by absolute address. 0x5C = both bytes right, 0xC1 = the LO byte
        is wrong (U72 / ~PC_LO_OUT), 0xC2 = the HI byte (U73 /
        ~PC_HI_OUT). Exercises the CALL-side pins ONLY, so calladdr
        passing and call failing puts the fault on the RET side. NOTE:
        CALL pushes PC+1, not PC+3 -- RET steps over the two operand bytes
        with PC_UP on T12/T13. PHASE C.
    PROG_callraw.bin 0xD709  0x2A  7
        REPORTS the pushed PC_LO byte raw -- no comparison, no fault
        codes. Found phase C's fault when calladdr had misattributed it:
        0x26 was the previous JMP's target, naming U72/U73 as landed on
        the PC LOAD path (U11/U12) instead of the Q outputs. Expect 0x2A.
        PHASE C.
    PROG_call.bin    0x14C9  0x4B  8
        the RETURN ADDRESS as the observable -- pads, for RET. The landing
        site is the ONLY thing that can produce the answer: 0x4B = RET
        landed on the right byte, 0xFF = it did not (OB is poisoned first
        and everything else in the image is HALT). The 0x120 HALTs of
        padding are LOAD-BEARING: they push the CALL above 0x00FF so the
        pushed PC_HI is 0x01, and a U73 that is dead or stuck low cannot
        pass by delivering 0x00. PHASE C -- needs U72/U73.
    PROG_stack.bin   0x1A77  0x27  13
        LXISP, PUSH, POP, CALL, RET. Pushes two DIFFERENT bytes and pops
        them into SWAPPED registers, so LIFO order is observable rather
        than decorative -- and the SUB runs INSIDE the callee with the
        only OUT after the return, so the answer exists only if registers,
        flags and stack all survived the call. PHASE C.
    PROG_ramexec.bin 0x9BC7  0x6E  21
        THE MACHINE EXECUTES FROM RAM. No new instruction -- the new thing
        is where the instructions come from. ROM plants LDBI/SUB/OUT/HALT
        at 0x9000, verifies byte 0 by ABSOLUTE address (unwritten RAM
        reads 0x00 = NOP, so a failed store would NOP-slide 28KB and look
        like a fetch fault), then JMPs across 0x8000 and the answer is
        computed in RAM. PHASE D.
    PROG_jnc.bin     0x64C0  0x6C  8
        THE ONLY IMAGE WHOSE ANSWER DEPENDS ON U77, the '157 flag mux. CMP
        sets FLAG_C, JNC selects it through CW21, and the taken arm is the
        only path to 0x6C. Run it WITH jncswap: a one-sided branch test is
        passed by a branch wired permanently taken. PHASE F.
    PROG_jncswap.bin 0x3841  0xEE  8
        jnc's other direction, same code, swapped operands. 0xEE is the
        pass here. PHASE F.
    PROG_mov.bin     0x234B  0x9C  6
        LDCI EXECUTES FOR THE FIRST TIME. C was write-only by design --
        RET's return-address scratch, with no way to read it back -- and
        MOV A,C is the one microcode row that closes it. A is cleared
        first so a dead MOV cannot report LDAI's byte. PHASE F.
    PROG_ptr.bin     0x8F67  0x22  21
        B:C AS AN INDEX PAIR, with PROG_sp3's discipline. Three cells, a
        different sentinel in each, planted through the pointer with STAX
        -- then read back down TWO paths, one through the pointer (LDAX)
        and one by ABSOLUTE address (LDB), and the answer is their
        difference. The absolute path cannot inherit a pointer fault.
        PHASE F.
    PROG_shl.bin     0x0E11  0xA4  9
        the TMP_B shadow doing arithmetic: SHL, INR, INR, NOT, DCR. Two
        INRs and one DCR on purpose -- INR then DCR returns the same byte
        whether both worked or neither did. PHASE F.
    PROG_ind.bin     0x9B7E  0x63  10
        MEMORY-INDIRECT, the third addressing mode. The pointer is in RAM
        and the operand names WHERE THE POINTER IS. 0x63 passes; 0xE0
        means it read the pointer byte instead of following it; 0x9C means
        it read an unwritten cell. B must survive. PHASE F+.
    PROG_indst.bin   0xAB5B  0x5B  9
        memory-indirect STORE, read back by absolute address so the
        readback cannot inherit the fault. 0x5B passes, 0x00 means the
        store never reached the target. PHASE F+.
    PROG_indj.bin    0x81A8  0x6C  7
        memory-indirect JUMP, landing site as the observable. 0x6C passes,
        0xE7 is the fall-through. The target address is computed from the
        assembled prologue, never counted. PHASE F+.
    PROG_serid.bin   0xEE88  0x55  6
        PHASE G, step 4b. STA/LDA round trip through the 16550's scratch
        register at 0x4807: the first write in this machine's life that
        anything consumed (~{IO_WR}, U75.6). RAW REPORT -- 0x54 names D0,
        0x51 D2, 0x15 D6; 0xFF means the card never drove W. Permutation-
        blind: a crossed U102 passes it.
    PROG_serid_aa.bin 0x74B4  0xAA  6
        the complement arm. 0x55 and 0xAA between them put a 1 and a 0 on
        every data line.

### Soak images — not coverage images

    PROG_cylon.bin   0x0980  521 bytes, NEVER HALTS
    14 frames, ~100ms each. Deliberately NOT in
    PR_COVERAGE: no (OB, END) fingerprint to match, because it
    never halts. Exercises LDAI/LDA/STA/SUB/JNZ both arms/OUT/JMP
    and two RAM cells continuously — the best transport check the
    machine has, and it needs no rig, no reset and no ROM swap.

    PROG_spcylon.bin 0x3DE3  702 bytes, NEVER HALTS
    The same sweep, but the frame table IS the stack: the
    outbound half PUSHes each frame as it shows it and the
    return half POPs them back, so LIFO order is the visible
    sweep direction. Ahead of it, every sweep, three boundary
    probes cross one ripple-carry link each:

        LXISP 0xFF16  ->  frozen OB 0xE1  = U63.15 -> U64.10 is dead
        LXISP 0xFF06  ->  frozen OB 0xE2  = U64.15 -> U65.10 is dead
        LXISP 0xF006  ->  frozen OB 0xE3  = U65.15 -> U66.10 is dead

    Dot sweeping = healthy. Dot frozen on 0xE1/0xE2/0xE3 = that
    carry link. Dot scrambled or walking backwards = pop order
    or a stuck direction pin. PHASE B hardware only (U63-U69);
    no CALL/RET, so it does not wait on U72/U73.

    PROG_swdemo.bin  0xB8A3  618 bytes, NEVER HALTS
    THE FIRST IMAGE THAT ANSWERS TO YOU WHILE IT RUNS. SW1 bit 0
    is read every pass, INSIDE the loop, so flipping the switch
    changes the display at the end of the current pass -- no
    reset, no reburn. Both arms are stack-driven and both balance
    their pushes and pops, so SP returns to where LXISP put it
    every time round.

        switch 0 OPEN    bit reads 1  ->  cylon sweep
        switch 0 CLOSED  bit reads 0  ->  0x55 / 0xAA interleaved blink

    SW1 IS ACTIVE LOW -- R17-R24 pull IS0-7 up and the switch
    pulls DOWN, so a CLOSED switch reads 0. Bits 1-7 are masked
    off (LDA <card zero>; LDBI 0x01; AND), so
    the other seven
    switches stay free.

    Blink shows 0x55 FIRST even though 0xAA is pushed first --
    that is LIFO, visible with two frames. Reversed order names a
    stack returning pushes in the order they went in.

### PROG_suite — the whole regression in ONE burn

    PROG_suite.bin   0x8A1C  12 tests, DIP-selected
    Twelve ROM pulls become one. Set SW1 to the test number,
    press RESET, read OB. The dispatch reads card zero at
    0x4000 and jumps to that test's 1K slot; each test is
    assembled at its own base, which is why their duplicate
    labels do not collide.

        SW1 =  1   mardisc  OB = 0x6B
        SW1 =  2   pads     OB = 0x40
        SW1 =  3   mem      OB = 0xC5
        SW1 =  4   flow     OB = 0x39
        SW1 =  5   alu      OB = 0x39
        SW1 =  6   loop     OB = 0x15
        SW1 =  7   sp       OB = 0x27
        SW1 =  8   sp2      OB = 0x53
        SW1 =  9   sp3      OB = 0x2C
        SW1 = 10   call     OB = 0x4B
        SW1 = 11   stack    OB = 0x27
        SW1 = 12   ramexec  OB = 0x6E

    A setting outside 1-12 OUTs SW1 RAW rather than a verdict,
    so a stuck switch or an inverted bank names its own value.
    NOT in PR_COVERAGE: twelve correct answers, no single
    (OB, END) fingerprint. The twelve standalone images stay --
    the suite depends on card zero and they are the fallback.

### The phase E witness — not a soak image, and not coverage

    PROG_window.bin  0xECF2  BEFORE 0xA5 / AFTER 0x5A
        THE PHASE E WITNESS. One burn, read TWICE, with
        ~{ROM_SEL} landed on U24.20 between the readings.
        Not in PR_COVERAGE: two correct answers, so there is no
        single (OB, END) fingerprint for the ladder to match.
        The BEFORE reading cannot be retaken once the window
        exists -- take it first. Since phase G the AFTER reading
        needs slot 1 EMPTY too: a PC crossing 0x4000 NOP-slides
        through card zero and, with the serial card fitted, fetches
        UART registers as opcodes at 0x4800 (PHASE_G.md GOTCHA 2).

### Phase G — the serial card's witnesses, UNORACLED

    simulate() REFUSES every one of these: they touch 16550
    registers that are TEMPORAL (THRE and DR move on bit
    boundaries) and the oracle has no clock. The expected byte
    is DATASHEET-SOURCED, its table or section named beside it,
    and a human compares OB against it. That is not the same
    thing as --expected checking it. PHASE_G.md SECTION 5.

    IMAGE              CRC16   BYTES  OB    SOURCE
    PROG_serprobe.bin  0x1FDF     8   0xFF  step 2 only, U103 NOT seated: the park. Meaningless after
    PROG_serlsr.bin    0xD728     8   0x60  datasheet TABLE I, LSR after Master Reset = THRE|TEMT
    PROG_seriir.bin    0x4312    13   0xC1  datasheet 8.6: bits 7:6 = FCR0, bit 0 = nothing pending
    PROG_serbaud.bin   0x2C77    24   -     scope U103.15 ~BAUDOUT: 153.6 kHz = 3686400/24
    PROG_serloop.bin   0xF995    60   0x53  the byte itself, back through MCR bit 4 loopback
    PROG_sertx.bin     0x1DC8   144   0x53  HOST TERMINAL shows DINO at 9600 8N1; OB only says done
    PROG_serrx.bin     0x64CE    72   -     never halts: typed char on OB AND echoed to the host

    Order: serid/serid_aa, serlsr, seriir (step 4), serbaud
    on the scope (step 5), serloop (step 6), sertx on a host
    terminal at 9600 8N1 (step 7), serrx (step 8, never halts).
    The data bus is NARROWED after step 4 and PROVEN only after
    step 7, when a receiver DINO does not control decodes it.

### SW1 is active low, and the DIP label reads backwards from the bus

Netlist: `R17-R24` pull `IS0-7` to +5V and `SW1.9-16` are all GND, so a CLOSED
switch shorts its bit to ground. On a DIP that means **"ON" = 0 and "OFF" =
1** — the silkscreen says ON where the bus reads zero.

To present `0x1E = 0b00011110`: positions 1, 6, 7, 8 ON and 2, 3, 4, 5 OFF.

The position numbering is SILKSCREEN, not copper, so it cannot be
netlist-checked. **Calibrate it:** position 1 ON alone gives `OB 0x2D` if
position 1 is bit 0, or `OB 0xAE` if it is bit 7. Neither reading is
confusable under bit-reversal or nibble-swap.

## Regenerating

    python3 docs/notes/microcode_gen.py     # U9, U15, U23 + diag set
    python3 docs/notes/progrom_gen.py       # PROG, PROG_diag, coverage, cylon
    python3 docs/notes/roms_readme_gen.py   # this file

The tracked generators reproduce these exact files byte-for-byte. If a
regeneration ever changes a byte, the CRCs in
`tests/dino_bringup/src/microcode_expect.h` and `progrom_expect.h` change with
it, and `test_microcode_gen.py`'s pinned CRC literals fail. **A reburn is
always deliberate.** That is the intended failure path.

## Burning

    make -C tests/dino_bringup burn-prog-diag
    make -C tests/dino_bringup burn-prog
    make -C tests/dino_bringup burn-prog-<tag>     # any coverage image

TL866, and Rico does the burning. Tools verify; they never program.

## Deferred hardening

`progrom_gen.py`'s `DIAG_ZERO = 0xA5` is bit-reverse-invariant, which makes
the diag image's byte 0 mirror-blind. Change it to a non-palindrome the next
time the DIAG image is reburned — no reason to reburn just for this.

### PROG_isa — the self-checking ISA test

    PROG_isa.bin     0xB96F  147 subtests, 3250 bytes

    Burn it, press RESET, read OB. 0xB4 means every
    subtest passed. ANY OTHER VALUE IS THE NUMBER OF THE FIRST
    INSTRUCTION THAT MISBEHAVED, and the table below names it.
    0xFF means the program halted without reaching an
    OUT at all -- a jump went somewhere it should not have.

    Every expected value in it was computed by the oracle, and
    every subtest is mutation-tested: breaking an instruction's
    microcode makes the program report that instruction. A
    subtest that survives its own instruction being broken is
    not counted as coverage.

    PROG_isacount.bin  0xA2D0  the SAME 147 subtests, COUNTED

    Identical tests, but a failure bumps a counter and
    execution CONTINUES. OB is then the NUMBER of subtests
    that failed, 0x00 for a clean run. Use it when the
    machine is marginal rather than broken: PROG_isa stops
    at the first failure and cannot tell one bad
    instruction from forty, and a wild jump into its stub
    table reports a subtest number that nothing failed.

    PROG_isaid.bin     0x019B  the SAME 147, reporting WHICH one failed

    Execution continues past a failure, as in isacount, so
    a wild jump cannot fabricate an answer -- but the cell
    holds the ID of the last failing subtest instead of a
    tally. When the count is reliably 0 or 1, last-failing
    IS the-one-failing. 0x00 is still clean, because ids
    start at 1.

    PROG_isasoak.bin   0x9554  the 147, run 255 TIMES, failures totalled

    ~9,400 subtest executions in under a tenth of a second.
    OB is the total failure count, 0x00 for a clean soak.
    Use it when the failure rate is low enough that
    resetting is not a measurement: at 1-in-60 you cannot
    tell whether a repair helped, and this turns that into a
    number that moves. 0x00 clean, 0xFE saturated,
    0xFF means it never finished.

    PROG_isalive.bin   0x504A  HOW FAR does it get before it dies

    Every pass OUTs its own number, so OB holds the last
    pass the machine actually reached. 0xB4 means it
    survived all 64. Anything else is where it died.

    A HANG cannot report anything at the end, because there
    is no end. This reports as it goes, which turns 'it
    usually does not finish' into a mean time to failure in
    passes -- a number that moves when a repair helps.
    Miscompares are deliberately ignored: this measures how
    FAR, not whether it AGREES.

    PROG_isawhere.bin  0xF87F  WHICH subtest was running when it died

    OB is updated with the subtest id before each subtest
    runs, so a machine that hangs leaves the id of the one
    it was in. 0xB4 means it survived all 64 passes. Use
    the id table below to name it.

    isalive says HOW FAR (a rate); this says WHERE (a place).

      1 LDAI       2 LDBI       3 LDCI       4 LXISP      5 LXIL       6 LXIH     
      7 LDA        8 STA        9 LDB       10 LDC       11 STB       12 STC      
     13 LDAS      14 STAS      15 LDBS      16 STBS      17 LDCS      18 STCS     
     19 JMP       20 JNZ       21 CALL      22 JMPX      23 JMPSP     24 JNC      
     25 JZX       26 JCX       27 JMPM      28 JZM       29 JCM       30 LDAM     
     31 LDBM      32 STAM      33 BIT       34 ADD       35 SUB       36 AND      
     37 OR        38 XOR       39 CLR       40 SET       41 BSUB      42 CMP      
     43 CMPB      44 TST       45 SHL       46 INR       47 DCR       48 NOT      
     49 PUSHA     50 POPA      51 PUSHB     52 POPB      53 PUSHC     54 POPC     
     55 INXSP     56 DCXSP     57 SPHL      58 HLSP      59 PUSHSPL   60 POPSPL   
     61 PUSHSPH   62 POPSPH    63 PUSHPCL   64 LDAX      65 STAX      66 LDBX     
     67 STBX      68 LDCX      69 STCX      70 MVIX      71 STADDX    72 STSUBX   
     73 STBSUBX   74 STANDX    75 STORX     76 STXORX    77 MOVAB     78 MOVAC    
     79 MOVBA     80 MOVBC     81 MOVCA     82 MOVCB     83 MOVASPL   84 MOVASPH  
     85 MOVSPLA   86 MOVSPHA   87 MOVAPCL   88 LDSPL     89 LDSPH     90 STSPL    
     91 STSPH     92 MVI       93 MVIS      94 MOVBSPL   95 MOVBSPH   96 MOVCSPL  
     97 MOVCSPH   98 MOVSPLB   99 MOVSPHB  100 MOVSPLC  101 MOVSPHC  102 MOVBPCL  
    103 MOVCPCL  104 ADI      105 ADI_B    106 ADI_C    107 SUI      108 SUI_B    
    109 SUI_C    110 BSUI     111 BSUI_B   112 BSUI_C   113 ANI      114 ANI_B    
    115 ANI_C    116 ORI      117 ORI_B    118 ORI_C    119 XRI      120 XRI_B    
    121 XRI_C    122 CPI      123 ADD_B    124 ADD_C    125 SUB_B    126 SUB_C    
    127 BSUB_B   128 BSUB_C   129 AND_B    130 AND_C    131 OR_B     132 OR_C     
    133 XOR_B    134 XOR_C    135 CPX      136 STADD    137 STSUB    138 STBSUB   
    139 STAND    140 STOR     141 STXOR    142 STADDS   143 STSUBS   144 STBSUBS  
    145 STANDS   146 STORS    147 STXORS   

    NOT covered by PROG_isa (37): NOP, RST, RET, OUT, OUTB, OUTC, OUTSPL, OUTSPH, OUTPCL, OUTPCH, OUTI, OUTM, OUTMX, OUTMS, PUSHPCH, MOVAPCH, INT, IRET, EI, DI, PUSHF, POPF, ADC, SBB, ACI, SBI, STPCL, STPCH, OUTADD, OUTSUB, OUTBSUB, OUTAND, OUTOR, OUTXOR, MOVBPCH, MOVCPCH, HALT
    The OUT family cannot be tested this way at all -- OB is
    write-only, so an OUT's result cannot be read back and
    compared inside the program. It needs its own image.

### Hand-written programs — assembled from .asm

    Written by hand in `asm/`, assembled with
    `python3 docs/notes/asm.py <src> -o roms/<image>`.
    These are NOT part of the regression: the coverage images
    above are generated and CRC-pinned, these are yours. The
    expected OB below is what the oracle computes by
    interpreting the same microcode the machine will run.

    IMAGE            CRC16   OB    SOURCE
    PROG_basic.bin   0xC34C  UNORACLED asm/basic.asm
    PROG_carry.bin   0xCA1F  0xAD  asm/carry.asm
    PROG_hello.bin   0x9C68  0x96  asm/hello.asm
    PROG_imon.bin    0xC12B  UNORACLED asm/imon.asm
    PROG_intaddr.bin 0x7F01  UNORACLED asm/intaddr.asm
    PROG_intaddrsw.bin 0x4C07  UNORACLED asm/intaddrsw.asm
    PROG_intcount.bin 0xDACD  UNORACLED asm/intcount.asm
    PROG_intflags.bin 0xB071  UNORACLED asm/intflags.asm
    PROG_inthalt.bin 0xE500  UNORACLED asm/inthalt.asm
    PROG_intmask.bin 0x5C73  UNORACLED asm/intmask.asm
    PROG_intresume.bin 0xAEF4  UNORACLED asm/intresume.asm
    PROG_intser.bin  0xA3CF  UNORACLED asm/intser.asm
    PROG_monitor.bin 0xD0E1  UNORACLED asm/monitor.asm
    PROG_romsoak.bin 0xF919  0x00  asm/romsoak.asm
    PROG_rxsoak.bin  0xA149  UNORACLED asm/rxsoak.asm
    PROG_serbaud.bin 0x2C77  UNORACLED asm/serbaud.asm
    PROG_serid.bin   0x8888  0x55  asm/serid.asm
    PROG_serid_aa.bin 0x74B4  0xAA  asm/serid_aa.asm
    PROG_seriir.bin  0x4312  UNORACLED asm/seriir.asm
    PROG_serlcr.bin  0x5F30  UNORACLED asm/serlcr.asm
    PROG_serlive.bin 0x3057  UNORACLED asm/serlive.asm
    PROG_serloop.bin 0xF995  UNORACLED asm/serloop.asm
    PROG_serlsr.bin  0xD728  UNORACLED asm/serlsr.asm
    PROG_serprobe.bin 0x1FDF  UNORACLED asm/serprobe.asm
    PROG_serrx.bin   0x64CE  UNORACLED asm/serrx.asm
    PROG_serrx0.bin  0xA1C4  UNORACLED asm/serrx0.asm
    PROG_serrxlcr.bin 0xF746  UNORACLED asm/serrxlcr.asm
    PROG_serrxlive.bin 0xA673  UNORACLED asm/serrxlive.asm
    PROG_sertx.bin   0x1DC8  UNORACLED asm/sertx.asm
    PROG_sertx00.bin 0x8E73  UNORACLED asm/sertx00.asm
    PROG_test.bin    0xC6CF  0x00* asm/test.asm
    PROG_test2.bin   0x3FAA  0x4D  asm/test2.asm
    PROG_test3.bin   0xB56A  0x4D  asm/test3.asm
    PROG_test4.bin   0x5841  0x5A  asm/test4.asm
    PROG_test5.bin   0xA464  0x00  asm/test5.asm
    PROG_txlive.bin  0xB2A4  UNORACLED asm/txlive.asm
    PROG_txsoak.bin  0x5903  0x00  asm/txsoak.asm
    PROG_wander.bin  0x95FD  0x00  asm/wander.asm

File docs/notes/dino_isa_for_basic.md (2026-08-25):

# DINO ISA — what a SCELBAL-shaped BASIC needs

**2026-07-28, updated 2026-08-02. THEORETICAL EXCEPT WHERE MARKED.**

> ## !!! STALE OPCODE NUMBERS — 2026-08-25 !!!
>
> **This is a DESIGN roadmap, not a record of silicon, and its opcode
> numbers were assigned before phases B and C were built. Two of them now
> collide with instructions that are on hardware.** Verified against
> `microcode_gen.OPCODES` on 2026-08-25:
>
>     §5 assigns  JZ 0x33 / JC 0x34   SILICON HAS  CALL 0x33 / RET 0x34
>     §5 assigns  MOV x6  0x61-0x66   SILICON HAS  PUSHA 0x61  POPA 0x62
>                                                  PUSHB 0x63  POPB 0x64
>
> The `MOV` range collides a second time inside this document: §5 claims
> `0x65`/`0x66` for `MOV` while §2.6 claims the same two for `PUSHC`/`POPC`.
>
> **`.git/sdd/PHASE_F.md` SECTION 6 is the collision-free opcode map.** Take
> numbers from there, not from §5. Everything else in this document — the
> hardware findings, the tier reasoning, the instruction *shapes* — is
> unaffected; only the numbering is wrong. Do not re-derive these
> collisions; they are named here so nobody has to.

Rule 2 (CLAUDE.md) gated ISA extension on the machine adding two numbers.
**That gate is now open** — the ladder passed, blocks 1-5 are bench-proven,
and the machine free-runs. Block 6 was dropped as pure repetition in favour
of driving the machine interactively.

**`IN` (0x52) is BUILT AND RUNNING as of 2026-08-02** — see the tier 0 table
below. It cost one microword and no hardware, exactly as this document
predicted, and it kept the opcode number this document proposed. Everything
else here is still design, not reburn.

**Companion: `dino_hardware_growth_plan.md`** — the board-level paths (I/O
decode, UART, shifter, third microcode ROM, stack, index pair, timer) that
these instructions sit on top of. Read that one for what gets WIRED and in
what order; read this one for what gets ENCODED.

The single most important interaction between the two: **memory-mapped I/O
(growth plan step 1) hands two microcode codes BACK** by retiring `SRC=SW`
and `MISC=REG_OUT_LOAD`, in a word that has exactly two left. Several
instructions below are only affordable because of it.

Everything below was derived from the netlist and `microcode_gen.py`, not from
memory. The three structural findings came out of that sweep and they are what
shape the answer.

---

## 1. Three hardware facts that bound the ISA

### 1.1 The microcode word is FULL — SUPERSEDED 2026-08-10

**The third EEPROM exists.** `U23` is in the schematic (commit `9dc7217`) and
the word is 24 bits. This section described the 16-bit constraint; it is kept
because the reasoning downstream of it still holds, but the constraint itself
is gone.

    SA    bits 9-11   (3)      END     bit 12
    MISC  bits 6-8    (3)      PC_UP   bit 13
    SRC   bits 3-5    (3)      MUX_PC  bit 14
    DST   bits 0-2    (3)      HALT    bit 15
                              ------------------
                              16 of 16 -- U9 + U15

    CW16 ~{CIN_SEL}    CW20 ~{ADDR_SEL1}     <- U23, the third ROM
    CW17 ~{SRC_BANK}   CW21 FLAG_SEL0
    CW18 ~{DST_BANK}   CW22 FLAG_SEL1
    CW19 ~{MISC_BANK}  CW23 FLAG_POL

`~{SRC_BANK}` and `~{DST_BANK}` are **wired**: they lift `U28.E3` and `U30.E3`
off `+5V` and enable a second '138 each, giving 16 sources and 16 destinations.
The old codes 0-7 keep identical behaviour, so no burned row re-encodes. The
other six bits are burned into all 4096 rows and unwired.

Bank-1 codes as built: `SRC` 8-11 = `SP_LO_OUT`, `SP_HI_OUT`, `PC_LO_OUT`,
`PC_HI_OUT`; `DST` 8-9 = `SP_LO_LOAD`, `SP_HI_LOAD`.

**`MISC` is now FULL.** It had two unused codes (5 and 7) brought out on `U29`
`O5`/`O7`; both are spent on `~{SP_UP}` and `~{SP_DOWN}`. `O0` is the `NONE`
slot and can never be reclaimed. The next MISC code needs `~{MISC_BANK}` wired
plus a second MISC '138, or step 1's I/O decode retiring `REG_OUT_LOAD`.

### 1.2 Carry-in is wired to the opcode, not to the microcode

    U53 (74LS08) gate 4:  U53.11 = AND(SA1, SA0)
    U50 (74LS02) gate 4:  ALU_CIN = NOR(U53.11, U53.11) = NOT(SA1 AND SA0)

    SA=011 ADD   -> CIN=0    correct for add
    SA=010 SUB   -> CIN=1    correct for A-B two's complement
    SA=001 BSUB  -> CIN=1    correct for B-A
    logic codes  -> CIN=1    don't care

`ALU_CIN` is a pure function of the SA field. **Microcode cannot set it.**
So there is no `ADC`/`SBB` — no single-instruction multi-byte arithmetic.
`FLAG_C` IS captured in `U49`, so multi-byte add is still possible in
SOFTWARE: add low bytes, branch on carry, increment the high byte. That needs
`JC`, which is §3.

### 1.3 The PC cannot be read

`pc` contract OUT is `M0-15` only — the address bus. There is no `SRC=PC` and
no path from PC to `W`. A return address can never be captured by the machine.

**Consequence: a conventional `CALL` is impossible without new hardware.** But
see §2.3 — the way around it is free, and it is the finding that makes BASIC
reachable.

---

## 2. TIER 0 — free. Microcode rows only, no schematic change.

Every row below is built from `DST`/`SRC`/`MISC`/`SA` codes that already
decode on the real boards.

### 2.1 Indirect addressing via B:C — the one BASIC cannot exist without

    LDAX     T1  src=REG_C dst=MAR_LO
             T2  src=REG_B dst=MAR_HI
             T3  src=RAM   dst=REG_A  END
    STAX     T1/T2 as above
             T3  src=REG_A dst=RAM    END

`B:C` becomes the pointer pair, exactly the role `H:L` plays in SCELBAL on the
8008. Today every memory access is an absolute address baked into the
instruction stream, which makes arrays, string scanning, the variable table and
the line-number list all impossible. This one addressing mode unlocks all of
them, and it costs three microcode rows.

Same shape gives `LDBX LDCX STBX STCX`.

### 2.2 Register moves

`src=REG_x, dst=REG_y`, one row each. Six useful combinations. Note `C` is
currently WRITE-ONLY — `LDCI` can fill it and no instruction can read it back —
so `MOV A,C` alone makes an existing register useful.

### 2.3 Computed jump — this is what replaces CALL

    JMPX     T1  src=REG_C dst=MAR_LO
             T2  src=REG_B dst=MAR_HI
             T3  misc=PC_LOAD  END

`PC_LOAD` already loads the PC from MAR, and MAR can now be loaded from
registers. So the machine can jump to a computed address.

That gives a calling convention with no hardware at all:

    caller:   LDBI ret_hi ; LDCI ret_lo ; JMP subroutine
    callee:   ... ; JMPX                  <- returns

`JMPX` **is** `RET`. Nesting works if the callee spills `B:C` to RAM with
`STA`, which it can. It also gives dispatch tables, which is how a BASIC
tokeniser branches on a keyword. Return addresses are compile-time constants
rather than pushed values — a well-worn technique on minimal machines, and it
is sufficient.

### 2.4 Compare and test — flags without clobbering the accumulator

    CMP      src=ALU dst=NONE sa=SUB   END     A-B, flags only
    CMPB     src=ALU dst=NONE sa=BSUB  END     B-A, flags only
    TST      src=ALU dst=NONE sa=OR    END     A|A, sets Z/N only

`dst=NONE` is already decoded (`U30` code 0 is a legal no-load). BASIC's
relational operators are all `CMP` + a conditional branch.

### 2.5 Shift left, reset, increment

    SHL      T1  src=REG_A dst=REG_B          (clobbers B)
             T2  src=ALU sa=ADD dst=REG_A END  A+A
    RST      misc=PC_CLEAR END                 jump to 0
    INX      T1  src=REG_C dst=REG_A
             T2  ... +1 via ADD ...            (clobbers A)

Right shift has no hardware path — the '382 does not shift and there is no
shifter. Divide-by-two must be a software loop or a table.

### 2.6 PUSHC / POPC — giving C back to the programmer

> **STALE NUMBERS (2026-08-25).** `0x65`/`0x66` are unoccupied on silicon,
> but §5 below also claims them for `MOV`. The two sections contradict each
> other. `.git/sdd/PHASE_F.md` SECTION 6 resolves it; take the numbers from
> there. The *reasoning* in this section still holds.

    PUSHC    _PUSH("REG_C")     0x65
    POPC     _POP("REG_C")      0x66

`RET` parks the return address's LO byte in `REG_C`, so **every return
clobbers C**. Combined with C being write-only (2.2), that makes C unusable
rather than merely reserved: a program cannot save it because no instruction
can read it.

Two rows fix it. `SRC["REG_C"] = 0b101` on `U28` and `DST["REG_C"] = 0b011`
on `U30` have both decoded since the machine was first burned; the stack's
`SP_UP`/`SP_DOWN` MISC codes already exist, which matters because MISC is now
FULL. So this needs no bank-1 code, no MISC code, and no schematic change —
it is phase-B hardware only and works the day the SP counters land, before
`U72`/`U73`.

Then the ordinary caller-save convention works:

    PUSHC ; CALL sub ; POPC

**Cost is a three-ROM burn**, since a new opcode writes rows in every byte of
the 24-bit word. Sequence it AFTER phase C so `CALL`/`RET` are proven and the
reburn happens once rather than twice.

---

## 3. TIER 1 — CANCELLED if the third EEPROM is on the roadmap

**Rico confirmed 2026-07-28 that a hardware stack and a third microcode EEPROM
are both planned. That cancels this tier — do NOT build it.**

Tier 1 spends the last two MISC codes (5, 7) and adds a 74LS27 to widen
`~{PC_LOAD}`. If the microcode word is about to grow, both are waste:
conditionals would end up split across an old 3-bit MISC field and a new one
FOREVER, and the '27 becomes vestigial the day the wide word lands. Design the
condition-code field ONCE, in the wide word, and get `JZ JNZ JC JNC JN JP JV`
coherently instead of two codes crammed into the last free slots.

The only argument for building it anyway: it is the cheapest possible path to
16-bit software math, and it is available now. Take it only if the third
EEPROM is far enough out that the machine needs to be useful in between.

The original design is kept below for that contingency.

### The contingency design

    JZ    misc=5  ->  U29.O5 (pin 10, NC today)
    JC    misc=7  ->  U29.O7 (pin 7, NC today)

Today only `FLAG_Z` reaches `COND`, so `JNZ` is the machine's only conditional.
`FLAG_C`, `FLAG_N` and `FLAG_V` are all registered in `U49` and all go nowhere.

`U62` has one free NOR gate (pins 11/12/13, NC). `~{PC_LOAD}` is currently
`NOR(COND_TAKEN, PC_LOAD_JMP)` — a 2-input NOR — so folding in a third and
fourth arm needs one more package, a 74LS27 (triple 3-input NOR) being the
natural fit.

**Cost: one chip, a handful of wires, and the last two MISC codes.** After this
the microcode word is completely exhausted.

**`JC` is what makes Rico's 16-bit software math work.** Add low bytes, `JC`
over an increment of the high byte. Without it, `FLAG_C` is captured and
unreachable, and multi-byte arithmetic is impossible at any cost.

---

## 4. TIER 2 — structural. Needs a third ROM or a new board.

| Want | Blocked by | Cost |
|---|---|---|
| `ADC` / `SBB` | `ALU_CIN = NOT(SA1 AND SA0)`, §1.2 | re-gate carry-in from a microcode bit — and there is no free bit, so a third EEPROM |
| Hardware `CALL`/`RET` with a stack | no `SRC=PC`, §1.3; `SRC` field full | PC→W buffer + SP register + wider microcode word |
| `JN` / `JV` | `MISC` exhausted after `JZ`/`JC` | wider microcode word |
| Right shift / `RRC` | no shifter in the datapath | new hardware |

None of these blocks a BASIC port. All of them make one faster or smaller.

---

## 4a. What the stack + third EEPROM actually change

Confirmed on the roadmap 2026-07-28. Impact, in order of how much it moves:

**1. `ADC`/`SBB` become one instruction each — the biggest single win.**
Replace `ALU_CIN = NOT(SA1 AND SA0)` (U50 gate 4, fed by U53's AND of SA1/SA0)
with a dedicated microcode CIN bit. 16-bit add stops being an add + `JC` +
increment loop and becomes two instructions. This is the change Rico's "we can
figure out how to add 16-bit numbers later" is actually asking for.

**2. Conditionals get designed once.** A proper condition-code field in the
wide word gives every flag, including the `FLAG_N`/`FLAG_V` that are captured
in U49 today and routed nowhere. Tier 1 becomes unnecessary — see §3.

**3. `CALL`/`RET` need `SRC=PC_LO` / `SRC=PC_HI`, so SRC gains a bank bit.**
That is exactly what the third ROM buys. **BUILT 2026-08-10**, with two
corrections to this paragraph:

- It is a bank **enable** (`~{SRC_BANK}` selecting between two '138s), not a
  fourth address input. A '138 has three.
- The new path lands on **`MDR0-7`, not `W`**, and taps **`PC0-15`, not `M`**.
  `U72`/`U73` are '245s from the '193 `Q` outputs into MDR, on the mdr sheet.
  Tapping `M` would make `CALL` impossible: the push row writes to RAM, so the
  address bus must carry MAR (the stack slot) and `M` is not carrying the PC.

**4. The SP needs a 1-of-3 address decode, and that is a BOARD CHANGE.**
Netlist-verified: `M` is sourced by a complementary-enable pair —
`U54`/`U59` (MAR) on `PC_MAR_MUX`, `U13`/`U14` (PC) on `~{PC_MAR_MUX}`, with
`U60` doing the inversion. Two states, one bit and its inverse, no room for a
third. Adding SP means replacing U60's inverter with a real decoder driving
three mutually exclusive enables. Design this WITH the PC→W path above — both
change how `M` and `W` are sourced, and doing them in one pass is one bring-up
session instead of two.

**5. What does NOT change.** Every Tier 0 instruction survives intact:

- `LDAX`/`STAX` on B:C stays the workhorse addressing mode. A dedicated index
  register can come later; code written against B:C stays valid.
- `JMPX` stays worth building even once a real `CALL` exists — computed jump is
  how a BASIC tokeniser dispatches on a keyword, and a hardware stack does not
  replace that.
- `MOV`, `IN`, `CMP`, `TST`, `SHL`, `RST` are all unaffected.

**So the first move is unchanged: build Tier 0.** It is pure microcode, none of
it is invalidated by the wider word, and it is what makes the machine
programmable at all. The roadmap changes what comes SECOND — not Tier 1's
74LS27, but the wide word and the two board changes together.

---

## 5. The proposed instruction set

> ## !!! THE OPCODE TABLE BELOW COLLIDES WITH SILICON TWICE !!!
>
> **STALE 2026-08-25**, verified against `microcode_gen.OPCODES`:
>
> - **`0x33`/`0x34` are `CALL`/`RET`**, bench-proven 2026-08-24. The table's
>   `JZ`/`JC` cannot have them.
> - **`0x61`-`0x64` are `PUSHA`/`POPA`/`PUSHB`/`POPB`**, bench-proven
>   2026-08-24. The table's `MOV` ×6 at `0x61`-`0x66` cannot have them, and
>   its remaining two (`0x65`/`0x66`) are claimed by §2.6 for
>   `PUSHC`/`POPC` as well.
>
> **`.git/sdd/PHASE_F.md` SECTION 6 is the collision-free map.** The table
> below is kept for its Rows/Tier/Notes columns and its reasoning; its
> opcode column is superseded. "Existing 18" is also stale — the machine
> shipped 26 opcodes as of phase C.

Existing 18 unchanged. `HALT=0xFF` stays the erased-EEPROM safe value. High
nibble remains the family: 0=ctl, 1=imm, 2=mem, 3=flow, 4=ALU, 5=io, and two
new families 6=move, 7=indirect.

| Op | Instr | Rows | Tier | Notes |
|---|---|---|---|---|
| 0x00 | `NOP` | 1 | — | existing |
| 0x01 | `RST` | 1 | 0 | `misc=PC_CLEAR` |
| 0x11-13 | `LDAI LDBI LDCI` | 1 | — | existing |
| 0x21 | `LDA addr` | 3 | — | existing |
| 0x22 | `STA addr` | 3 | — | existing |
| 0x31 | `JMP addr` | 3 | — | existing |
| 0x32 | `JNZ addr` | 3 | — | existing |
| 0x33 | `JZ addr` | 3 | **1** | `misc=5`, `U29.O5` |
| 0x34 | `JC addr` | 3 | **1** | `misc=7`, `U29.O7` |
| 0x35 | `JMPX` | 3 | 0 | computed jump = `RET` + dispatch |
| 0x41-48 | 8 ALU ops | 1 | — | existing, all 8 SA codes |
| 0x49 | `CMP` | 1 | 0 | `dst=NONE sa=SUB` |
| 0x4A | `CMPB` | 1 | 0 | `dst=NONE sa=BSUB` |
| 0x4B | `TST` | 1 | 0 | `dst=NONE sa=OR` |
| 0x4C | `SHL` | 2 | 0 | clobbers B |
| 0x51 | `OUT` | 1 | — | existing |
| 0x52 | `IN` | 1 | 0 | **BUILT 2026-08-02.** `END \| src=SW \| dst=REG_B` = `0x103A`. Netlist-verified first: `SWITCH-GATE1` is a plain buffer `IS0-7 -> W0-7` with no permutation, both halves on the one `~{SW_OUT}` net; and `U50` makes `LE_TMP_B = NOR(~{REG_B_LOAD}, CLK)`, so the shadow follows the LOAD STROBE rather than the `LDBI` opcode and `ADD` sees the switch byte with no extra row. Only U9 reburned (`0xAD70 -> 0x0FBB`) — the high byte already matched the safe-fill. Bench: `0x2F + 0x01 = 0x30`, `0x2F + 0x1E = 0x4D` |
| 0x61-66 | `MOV` ×6 | 1 | 0 | makes `C` readable at last |
| 0x71 | `LDAX` | 3 | 0 | **the one that unlocks BASIC** |
| 0x72 | `STAX` | 3 | 0 | |
| 0x73-76 | `LDBX LDCX STBX STCX` | 3 | 0 | |
| 0x77 | `INX` | 3 | 0 | clobbers A |
| 0xFF | `HALT` | 1 | — | existing |

**38 instructions. 20 new, 18 of them free.**

Longest instruction is 4 T-states against a 4-bit T counter (16 available), so
the sequencer has ample headroom.

---

## 6. Is that enough for BASIC?

Against SCELBAL's 8008 requirements:

| SCELBAL needs | DINO has | |
|---|---|---|
| immediate loads | `LDAI/LDBI/LDCI` | yes |
| register moves | `MOV` ×6 | yes, tier 0 |
| memory via pointer pair | `LDAX/STAX` via B:C | yes, tier 0 |
| arithmetic + logic | 8 SA codes | yes |
| compare | `CMP/CMPB/TST` | yes, tier 0 |
| conditional branch | `JNZ` + `JZ` + `JC` | yes, tier 1 |
| subroutine call/return | `JMPX` + B:C convention | yes, tier 0 — §2.3 |
| terminal I/O | `IN`/`OUT` | yes, tier 0 |
| multi-byte arithmetic | software, `FLAG_C` + `JC` | yes, tier 1 |
| right shift | — | **no.** Software loop or table |
| hardware stack | — | **no.** Constant return addresses |

**Verdict: a SCELBAL-shaped BASIC is reachable with Tier 0 + Tier 1** — 18 free
microcode instructions plus one 74LS27 and two wires for `JZ`/`JC`.

The two genuine absences, right shift and a hardware stack, cost performance
and program size, not feasibility. 16-bit math works the way Rico called it:
in software, on the back of `FLAG_C`, which is why `JC` is the one piece of
hardware on the critical path.

---

## 7. Build order, when the gate lifts

1. ~~Block ladder, milestone green.~~ **DONE 2026-08-02 — Rule 2 lifted.**
   Blocks 1-5 bench-proven; block 6 dropped as repetition.
2. Tier 0 microcode: `LDAX/STAX`, `JMPX`, `MOV`, `IN`, `CMP`. One reburn, no
   schematic change, and `microcode_gen`'s `check_word`/`check_table` police it.
3. Coverage ROMs per new group, same pattern as `PROG_alu`/`PROG_mem`/
   `PROG_flow` — each reduces to a byte in A, then `OUT; HALT`, because `OB` is
   the only datapath observable.
4. **NOT Tier 1.** Skip the 74LS27 — see §3 and §4a. Go straight to the wide
   microcode word.
5. Third EEPROM + the two board changes designed together: the SP's 1-of-3
   address decode (replacing U60's inverter) and the PC→W path. Both change how
   `M` and `W` are sourced, so they are one bring-up session, not two.
6. In the wide word, in priority order: a microcode CIN bit (`ADC`/`SBB`), a
   real condition-code field (every flag, not two crammed codes), then
   `SRC=PC_LO/PC_HI` for `CALL`/`RET`.
7. `PUSHC`/`POPC` (§2.6) once phase C is proven — two rows, no schematic
   change, and it returns C to general use instead of leaving it as `RET`'s
   scratch.

Note for step 5: each new board gets a MODULE test first, then rejoins the
block ladder — the same law applies. A stack pointer is a new member of
blocks 2-6 and its address enable is exactly the kind of mutually-exclusive
strobe the ladder exists to police.

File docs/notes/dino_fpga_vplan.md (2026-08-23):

# DINO FPGA Verification Plan (VPLAN)

**Date:** 2026-08-10.
**Method:** identical discipline to the intel-8008-vhdl precedent
(`~/Development/intel-8008-vhdl/docs/VPLAN.md`). Every row below maps a
specification-derived claim (`CLAUDE.md`'s "machine invariant" table, the
FPGA-port paragraph, and the 2026-08-04 full-ISA state section;
`.git/sdd/BRINGUP.md`'s "Machine invariant: EVERYTHING COMMITS
ON CLK LOW"; `docs/notes/microcode_gen.py`'s `check_word`/`check_table`
rules) onto the real artifact inventory (`fpga/ttl/`, `fpga/sim/`,
`fpga/postsynth/`, `fpga/synth/`, `fpga/Makefile`, `docs/notes/test_*.py`,
`.git/sdd/BRINGUP_FPGA.md`) — a row is COVERED only if some existing artifact
would **FAIL** were the behavior wrong. Where a citation names a specific
function (`path::name`), `test_vplan.py` mechanically verifies that
function exists in that file — a citation is no longer just a
plausible-looking path.

**GAP count: 5** (of 92 rows). Named in full in "Gap list" below; every
one is a genuinely un-policed rule (printed WARNING, never enforced) or a
ledgered deferral. None are silent.

## The 2026-08-10 stack phase — covered, but not yet ROWED

Twelve chips and seven instructions landed after this table was written.
They are **exercised** — the artifacts below all exist and all pass — but
they do not yet have their own rows, because the table is mechanically
coupled to `test_vplan.py`'s `KNOWN_GAPS` literal and rowing them properly
is its own pass. Named here so none of it reads as silently covered:

    U23           third microcode EEPROM, CW16-23
    U70 / U71     SRC / DST bank-1 '138s
    U63-U66       '169 stack pointer
    U67 / U68     SP readback '245s -> MDR
    U69           '08, ~{SP_CE}
    U72 / U73     PC0-15 -> MDR '245s

    LXISP  PUSHA  PUSHB  POPA  POPB  CALL  RET

Artifacts that would fail if the behaviour were wrong:

- `fpga/ttl/test_stateful.py::counter169_updown_hold_and_load_priority` and
  `::counter169_tc_is_active_low_and_direction_dependent` — the four ways a
  '169 differs from the '163 it was copied from.
- `fpga/sim/test_module_stack_pointer.py` — five cases, including a
  mirror-witness load/readback and a byte-boundary carry that would have
  caught the crossed `~TC` cascade the schematic was first drawn with.
- `fpga/sim/test_module_control_word.py::test_src_bank1_darkens_bank0_and_decodes_one_hot`
  and its DST twin and independence case.
- `fpga/sim/test_core_coverage.py::stack_round_trips_through_lifo_and_returns`
  — the whole machine, and the ONLY execution of the stack anywhere: the rig
  is detached and this hardware has never existed outside a netlist.
- `docs/notes/test_microcode_gen.py` — the 24-bit word, the `0xFF`-is-inert
  property row by row, the three new `check_word` rules, and a CRC tripwire
  on all three ROM images.

**Two rules in `check_word` exist because the gate model refused what
reasoning had accepted**, and both are worth rows of their own eventually:

- `src=RAM` cannot write `MAR` in the same word. The RAM address IS MAR and
  the '373s are transparent while CLK is low, so it closes a live loop:
  `MAR -> M -> RAM -> MDR -> U25 -> W -> MAR`.
- `misc=MDR_OUT` must be the state IMMEDIATELY after the read that parked the
  byte. `LE_MDR` falls at the T-state boundary and can latch whatever the
  NEXT source is turning on. RET's second draft parked a byte, moved another
  one, then replayed — and loaded the PC with `0x0C0C` instead of `0x000C`.

Still genuinely uncovered, and stated as such: **`~{CIN_SEL}`,
`~{MISC_BANK}`, `~{ADDR_SEL1}`, `FLAG_SEL0/1` and `FLAG_POL` are burned into
all 4096 rows and wired to nothing.** No artifact can fail on them, because
no consumer exists. They are reserve, not coverage.

**Status legend:**
- `COVERED-EXHAUSTIVE` — full-space differential sweep against an
  independent model (cite sweep).
- `COVERED-DIRECTED` — directed self-checking test (cite).
- `COVERED-INCIDENTAL` — a real, passing artifact exists, but it does not
  specifically target the claimed behavior — it would not necessarily
  fail if only THAT behavior broke. Distinct from GAP (something does
  exercise the code path) and distinct from COVERED-DIRECTED (a
  COVERED-DIRECTED artifact is aimed at the claim; a COVERED-INCIDENTAL
  one just happens to touch it).
- `GAP` — no failing check exists.

One deliberate rider: the port-phase follow-up "`prepare_roms` CRC guard"
did not exist (`fpga/sim/conftest_helpers.py`'s `prepare_roms()` only
compared source/output *mtimes*, never content) — implemented as
`_assert_crc()` in `fpga/sim/conftest_helpers.py`, host-tested
(`docs/notes/test_vplan.py::test_assert_crc_guard_catches_content_mismatch`
and `::test_prepare_roms_integration_does_not_raise_against_real_roms`).
See RES-06.

---

## Row table

### A. Machine invariant — commit on CLK low

| ID | Spec cite | Assertion | Conditions | Check type | Check artifact | Status |
|----|---|---|---|---|---|---|
| INV-01 | CLAUDE.md "machine invariant" table | Register-file/IR shadow-load latches (`le_ir`, `NOR(clk, n_ir_load)`) commit only while CLK is LOW | all reachable `cw`/`clk` combos | directed | fpga/sim/conftest_helpers.py::invariant_monitor (standing, every whole-core test); fpga/sim/test_module_mdr.py::test_mdr_ir_capture_gated_by_clk_low | COVERED-DIRECTED |
| INV-02 | CLAUDE.md "machine invariant" table | MAR LO/HI shadow-load latches (`le_mar_lo`/`le_mar_hi`) commit only while CLK is LOW | all reachable combos | directed | fpga/sim/test_module_mar.py::test_mar_load_gated_by_clk_low | COVERED-DIRECTED |
| INV-03 | CLAUDE.md "machine invariant" table | ALU TMP_A/TMP_B shadow-load latches (`le_tmp_a`/`le_tmp_b`) commit only while CLK is LOW | all reachable combos | directed | fpga/sim/test_module_alu.py::test_alu_shadow_gated_by_clk_low_and_independent | COVERED-DIRECTED |
| INV-04 | CLAUDE.md "machine invariant" table | Register A/B/C/OUT LE stamps (`n_reg_a_le`..`n_reg_out_le`, `NOR(n_reg_x_load, clk)`) commit only while CLK is LOW | all reachable combos | directed | fpga/sim/test_module_registers_a_b.py::test_registers_load_commits_on_clk_low | COVERED-DIRECTED |
| INV-05 | CLAUDE.md "machine invariant" table | RAM write pulse (`n_ram_write_en = NAND(write_dir, ~clk)`) fires only while CLK is LOW | all reachable combos | directed | fpga/sim/test_module_memory.py::test_memory_ram_write_gated_by_clk_low | COVERED-DIRECTED |
| INV-07 | CLAUDE.md "machine invariant" table | PC LOAD (`n_pc_load_stable = NAND(n_pc_load, ~clk)`) lands only while CLK is LOW | all reachable combos | directed | fpga/sim/test_module_program_counter.py::test_pc_load_gated_by_clk_low | COVERED-DIRECTED |
| INV-08 | CLAUDE.md "machine invariant" table | PC CLEAR (`NOR(~pc_clear, clk)`) lands only while CLK is LOW; RESET is the un-gated leg | both | directed | fpga/sim/test_module_program_counter.py::test_pc_clear_gated_by_clk_low_reset_ungated | COVERED-DIRECTED |
| INV-10 | CLAUDE.md "machine invariant" table | RESET is asynchronous/un-gated for the PC counters (and, via the same NOR leg, for T-state clear) | both phases of CLK | directed | fpga/sim/test_module_program_counter.py::test_pc_clear_gated_by_clk_low_reset_ungated | COVERED-DIRECTED |
| INV-11 | CLAUDE.md "machine invariant" table | Bus output enables (`~ROM_OUT`/`~RAM_OUT`/`~REG_x_OUT`/`~ALU_OUT`/`~SW_OUT`/`~MDR_OUT`) are pure functions of `cw`/`flag_z`, never CLK-qualified | exhaustive `cw` sweep | directed (incidental) | fpga/sim/test_module_control_word.py::test_control_word_all_groups_active_no_interaction (never varies clk, so a future clk-dependent regression would not be caught BY THIS TEST specifically); fpga/gen/control_word.vhd (entity has no machine-CLK port at all — the real guarantee is structural, not test-driven) | COVERED-INCIDENTAL |
| INV-12 | CLAUDE.md "consequence" paragraph; BRINGUP.md "why the ungated ones do not matter" | A microcode decode glitch (transient double-enable during the ROM access window) cannot corrupt state, because every state-changing path is CLK-qualified per INV-01..INV-10 | — | derived | (composite of the surviving machine-invariant rows in this section: INV-01..INV-05, INV-07, INV-08, INV-10; no independent artifact beyond their union — the sole row in this table with no path citation of its own, by design) | COVERED-DIRECTED (derived) |

### B. Bus one-hot / shared-bus discipline

| ID | Spec cite | Assertion | Conditions | Check type | Check artifact | Status |
|----|---|---|---|---|---|---|
| BUS-03 | verification-design spec, Track 3.1 (structural precondition) | Each `'138` decoder (SRC/MISC) is one-hot within its own group for every select code, independent of ROM content | exhaustive select x enable | exhaustive | fpga/ttl/test_msi.py::decoder_truth_table | COVERED-EXHAUSTIVE |

### D. Microcode ROM policing rules (`microcode_gen.check_word`/`check_table`)

| ID | Spec cite | Assertion | Conditions | Check type | Check artifact | Status |
|----|---|---|---|---|---|---|
| ROM-01 | docs/notes/microcode_gen.py check_word() | `src=RAM` and `dst=RAM` in the same microword is illegal (RAM corrupts) | crafted bad word | directed | docs/notes/test_microcode_gen.py (must_raise: src=RAM dst=RAM — module-level assert, no enclosing function to cite by name) | COVERED-DIRECTED |
| ROM-02 | docs/notes/microcode_gen.py check_word() | `/MDR_OUT` replay concurrent with any other active `src` is a W-bus fight and illegal | crafted bad word | directed | docs/notes/test_microcode_gen.py (must_raise: MDR_OUT plus src=ROM) | COVERED-DIRECTED |
| ROM-03 | docs/notes/microcode_gen.py check_word() | `PC_UP` concurrent with `/PC_LOAD` in the same microword is illegal (fragile on `'193` internals) | crafted bad word | directed | docs/notes/test_microcode_gen.py (must_raise: PC_UP with PC_LOAD) | COVERED-DIRECTED |
| ROM-04 | docs/notes/microcode_gen.py check_word() | `IR_LOAD` may only occur at T0 (the instruction register changes only at fetch) | crafted bad word | directed | docs/notes/test_microcode_gen.py (must_raise: IR_LOAD outside T0) | COVERED-DIRECTED |
| ROM-05 | docs/notes/microcode_gen.py check_word() | T0 of every one of the 256 opcodes must be the universal FETCH word | all 256 opcodes + crafted bad word | directed | docs/notes/test_microcode_gen.py (256-opcode sweep + must_raise: non-fetch T0 row) | COVERED-DIRECTED |
| ROM-06 | docs/notes/microcode_gen.py check_table() | Every opcode's defined microcode block terminates (END or HALT bit) before running into safe-fill | crafted END-less block | directed | docs/notes/test_microcode_gen.py (check_table END-less-block rejection) | COVERED-DIRECTED |
| ROM-07 | docs/notes/microcode_gen.py check_word() | `src==dst` for the same register (A/B/C, "probable MOV typo") is flagged | any such word | — | check_word() only `print()`s a WARNING; never raises, never asserted by any test | GAP |
| ROM-08 | docs/notes/microcode_gen.py _check_lengths() | Per-instruction `PC_UP` count matches the instruction's byte length | every INSTRUCTIONS entry | — | _check_lengths() only `print()`s a WARNING; never raises, never asserted by any test | GAP |
| ROM-09 | CLAUDE.md "what is proven" section | `progrom_gen.OPCODES` is imported from `microcode_gen`, so the microcode and program ROMs cannot disagree on an opcode's meaning | — | directed (incidental) | docs/notes/test_progrom_coverage.py::test_simulator_against_microcode (targets simulator-vs-microcode agreement, not opcode-table identity specifically — a future accidental OPCODES fork would very likely, but not necessarily, be caught here as a side effect) | COVERED-INCIDENTAL |
| ROM-10 | CLAUDE.md "what is proven" section | The SA (ALU-select) field reaches the `'382` in the wiring's actual (bit-reversed at the microcode-bit level) order — the historical ADD-executes-as-AND bug | full netlist walk | directed | docs/notes/test_microcode_gen.py::test_sa_field_reaches_the_382_uninverted | COVERED-DIRECTED |

### E. Port fidelity (exact virtual copy)

| ID | Spec cite | Assertion | Conditions | Check type | Check artifact | Status |
|----|---|---|---|---|---|---|
| FID-01 | port-design spec, "Emitter" | Every physical chip on every one of the 10 schematic sheets is instantiated exactly once in the generated VHDL | all 10 sheets | directed | docs/notes/test_fpga_gen.py::test_emit_every_chip_once_every_net_somewhere | COVERED-DIRECTED |
| FID-02 | port-design spec, "Emitter" | Every pin of every used part type is mapped to a net or explicitly marked NC; a missing mapping is a hard failure, not a warning | every part type | directed | docs/notes/test_fpga_gen.py::test_missing_pin_map_entry_is_a_hard_failure; docs/notes/test_fpga_gen.py::test_nc_allowed_covers_every_unconnected_model_input | COVERED-DIRECTED |
| FID-03 | port-design spec, "never hand-edited" | The committed `fpga/gen/*.vhd` exactly matches a fresh emitter run (no hand-edit drift) | every generated file | directed | docs/notes/test_fpga_gen.py::test_committed_gen_matches_emit_output_no_drift | COVERED-DIRECTED |
| FID-04 | port-design spec, "Chip model contract" | `clk_sys` is threaded to every stateful chip instance | every stateful instance | directed | docs/notes/test_fpga_gen.py::test_clk_sys_threaded_to_every_stateful_instance | COVERED-DIRECTED |
| FID-05 | port-design spec, Goal ("byte-identical, CRC-matched") | ROM/RAM models are initialized from the SAME bytes, CRC-matched, as the bench-burned chips | every ROM | directed | fpga/sim/conftest_helpers.py::_assert_crc (this task's rider, RES-06) | COVERED-DIRECTED |
| FID-07 | port-design spec, Goal ("byte-identical, CRC-matched") | The GENERATED `microcode` module entity's own ROM content, read back through its gate-level ports, exactly matches `microcode_gen.build_real()` — not just the `.bin`/`.hex` file on disk | all 4096 rows | exhaustive | fpga/sim/test_module_microcode.py::test_microcode_full_image_matches_build_real; fpga/sim/test_module_microcode.py::test_microcode_known_rows_match_build_real | COVERED-EXHAUSTIVE |
| FID-08 | port-design spec, Goal ("byte-identical, CRC-matched") | The GENERATED `memory` module entity's own ROM content, read back through its gate-level ports, exactly matches `progrom_gen.build_real()` | spot rows | directed | fpga/sim/test_module_memory.py::test_memory_rom_content_matches_build_real | COVERED-DIRECTED |

### F. Whole-core simulation / ISA execution

| ID | Spec cite | Assertion | Conditions | Check type | Check artifact | Status |
|----|---|---|---|---|---|---|
| SIM-01 | CLAUDE.md 2026-08-04 state; port-design spec, Testing step 4 | The milestone program (`LDAI 0xFF; OUT; LDAI 0x2F; LDBI 0x1E; ADD; OUT; HALT`) free-runs in the gate-level model to `OB=0x4D` | free-run | directed | fpga/sim/test_core_milestone.py::milestone_free_runs_to_4d | COVERED-DIRECTED |
| SIM-02 | CLAUDE.md 2026-08-04 state ("PROG_in ... SW1=0x01 gives 0x30, SW1=0x1E gives 0x4D") | `IN` reads its operand from the DIP switches | SW1=0x01 and SW1=0x1E | directed | fpga/sim/test_core_milestone.py::in_tracks_switches | COVERED-DIRECTED |
| SIM-03 | port-design spec, "Standing sim assertion" | No gated-clock edge (of `gated_clocks.txt`'s checked set) ever fires while sampled machine CLK is high, across every whole-core run | every whole-core test | directed | fpga/sim/conftest_helpers.py::invariant_monitor; fpga/sim/test_core_milestone.py; fpga/sim/test_core_coverage.py; fpga/sim/test_core_fuzz.py | COVERED-DIRECTED |
| SIM-04 | CLAUDE.md 2026-08-04 state ("alu 0x39 all eight SA codes, chained non-maskingly") | The `alu` coverage image exercises all eight SA codes, chained non-maskingly; gate-level `OB` matches the oracle | full coverage run | directed | fpga/sim/test_core_coverage.py::alu_covers_every_sa_code | COVERED-DIRECTED |
| SIM-05 | CLAUDE.md 2026-08-04 state ("mem 0xC5 MAR as a latch, RAM round trip") | The `mem` coverage image witnesses MAR-as-a-latch and a RAM round trip; gate-level `OB` matches the oracle | full coverage run | directed | fpga/sim/test_core_coverage.py::mem_witnesses_mar_as_a_latch | COVERED-DIRECTED |
| SIM-06 | CLAUDE.md 2026-08-04 state ("flow 0x39 JMP lands; SUB sets FLAG_Z; JNZ correctly declines") | The `flow` coverage image's JMP lands, SUB sets FLAG_Z, and JNZ correctly declines; gate-level `OB` matches the oracle | full coverage run | directed | fpga/sim/test_core_coverage.py::flow_takes_the_jump_and_falls_through | COVERED-DIRECTED |
| SIM-07 | CLAUDE.md 2026-08-04 state ("loop 0x15 JNZ TAKEN arm x3 ... exact iteration count 3x7=21") | The `loop` coverage image's JNZ-taken arm fires 3x, flags survive an intervening STA, exact iteration count holds; gate-level `OB` matches the oracle | full coverage run | directed | fpga/sim/test_core_coverage.py::loop_takes_the_jnz_branch | COVERED-DIRECTED |
| SIM-08 | CLAUDE.md "What it cost" section (mardisc/pads, port-design spec's coverage ladder) | The `mardisc`/`pads` coverage images (MAR discriminates two different addresses; PC_LOAD lands exactly on target) match the oracle at gate level | full coverage run | directed | fpga/sim/test_core_coverage.py::mardisc_discriminates_mar_lo; fpga/sim/test_core_coverage.py::pads_lands_the_jmp_at_the_named_pad | COVERED-DIRECTED |
| SIM-09 | BRINGUP_FPGA.md "gate 5" | The POST-SYNTHESIS netlist (not the source VHDL) still reaches `OB=0x4D` on the milestone program | post-synth run | directed | fpga/postsynth/test_postsynth_milestone.py::postsynth_milestone_free_runs_to_4d | COVERED-DIRECTED |

### G. Synthesis gates

| ID | Spec cite | Assertion | Conditions | Check type | Check artifact | Status |
|----|---|---|---|---|---|---|
| SYN-01 | BRINGUP_FPGA.md "gate 1" (netlist-integrity) | GHDL import severs no declared signal | every generated entity | directed | docs/notes/test_netlist_integrity.py::test_ghdl_import_severs_no_declared_signal | COVERED-DIRECTED |
| SYN-02 | BRINGUP_FPGA.md "gate 1" | The tri-state bus-resolution pre-pass (`bus_resolve.ys`) leaves no multiply-driven net | full synth | directed | docs/notes/test_netlist_integrity.py::test_bus_resolve_leaves_no_multiply_driven_net | COVERED-DIRECTED |
| SYN-03 | BRINGUP_FPGA.md "gate 5" motivation (opt_clean regression) | Coarse synthesis preserves all four memories (ROM x2 half-bytes, program ROM, RAM) — none get eaten by `opt_clean` | full synth | directed | docs/notes/test_netlist_integrity.py::test_synth_coarse_preserves_all_four_memories | COVERED-DIRECTED |
| SYN-04 | port-design spec, "Written to be BRAM-inferable" | Full synthesis maps all four memories to real block RAM (DP16KD), not distributed logic | full synth | directed | docs/notes/test_netlist_integrity.py::test_full_synth_maps_all_five_memories_to_block_ram | COVERED-DIRECTED |
| SYN-05 | BRINGUP_FPGA.md "hex-vs-roms staleness check" | Every committed `.hex` matches its committed `roms/*.bin`, byte-for-byte | every image tag | directed | fpga/synth/check_images.py::check_hex (run on every `make bit`) | COVERED-DIRECTED |
| SYN-06 | BRINGUP_FPGA.md "check-images ... --meminit gate" | The synthesized `$mem_v2` INIT content matches `roms/*.bin` byte-for-byte, for every image tag — the bytes Rico actually burns | every image tag, full synth | directed | fpga/synth/check_images.py::check_meminit (`make -C fpga check-images`) | COVERED-DIRECTED |
| SYN-07 | BRINGUP_FPGA.md "the timing gate" | Post-route timing closes at the `clk_sys` constraint (Fmax PASS) for every image tag | every image tag | directed | fpga/Makefile ($(BUILD_DIR)/dino_%.bit "timing gate" recipe step) | COVERED-DIRECTED |
| SYN-08 | port-design spec, Testing rung 6 ("zero inferred latches") | Synthesis infers zero latches | full synth, every image | — | `proc -latches warn` (fpga/Makefile, fpga/postsynth/Makefile, fpga/synth/check_images.py) only WARNS to a log; nothing parses that log and fails if the warning count is nonzero | GAP |

### I. Differential fuzzing

| ID | Spec cite | Assertion | Conditions | Check type | Check artifact | Status |
|----|---|---|---|---|---|---|
| FUZZ-01 | verification-design spec, Track 1 | Random legal DINO programs produce a gate-level final `OB` matching `progrom_gen.simulate()`'s oracle | seeded soak (500 seeds) | directed | fpga/sim/test_core_fuzz.py::fuzz_one_seed | COVERED-DIRECTED |
| FUZZ-02 | verification-design spec, Track 1 ("compare those too, not just OB") | Gate-level RAM-writes summary and branches-taken count match the oracle, not just `OB` (mirror-witness discipline extended to fuzzing) | seeded soak | directed | fpga/sim/test_core_fuzz.py::fuzz_one_seed | COVERED-DIRECTED |
| FUZZ-03 | verification-design spec, Track 1 ("also fuzz the switches") | Fuzzing exercises `IN` with random, seed-derived (not hardcoded) DIP-switch values | programs containing IN | directed | fpga/sim/test_core_fuzz.py::fuzz_one_seed (drives `meta["switches"]`, a `fuzz_gen.gen()`-derived per-seed value, not a constant); docs/notes/test_fuzz_gen.py::test_uses_in_matches_program; docs/notes/test_fuzz_gen.py::test_switches_are_seed_derived_reproducible_and_vary | COVERED-DIRECTED |
| FUZZ-04 | verification-design spec, "Open items" (metavalue budget) | The metavalue-warning count across a fuzz soak stays within a documented, only-shrinking budget | full soak | directed | fpga/sim/test_core_fuzz.py::run_fuzz_seeds (budget check, raises if exceeded) | COVERED-DIRECTED |
| FUZZ-05 | verification-design spec, Track 1 (generator contract: "legal DINO programs...always terminated by HALT...jump targets constrained to program bounds") | `fuzz_gen.py`'s generator produces only sim-supported opcodes, is deterministic per seed, always HALT-terminates, jumps are forward-only (guaranteeing termination), memory ops stay inside the pinned RAM window with distinct low bytes when there are >=2, and its `uses_in` metadata matches the actual program | seeded (50 seeds per property) | directed | docs/notes/test_fuzz_gen.py::test_deterministic_and_legal; docs/notes/test_fuzz_gen.py::test_every_seed_terminates_in_oracle; docs/notes/test_fuzz_gen.py::test_jumps_are_forward_only; docs/notes/test_fuzz_gen.py::test_jnz_always_preceded_by_alu_op; docs/notes/test_fuzz_gen.py::test_memory_ops_use_distinct_low_bytes; docs/notes/test_fuzz_gen.py::test_memory_addresses_stay_in_ram; docs/notes/test_fuzz_gen.py::test_uses_in_matches_program; docs/notes/test_fuzz_gen.py::test_limit_truncates_reproducibly | COVERED-DIRECTED |

### K. Residue / ledger follow-ups

**RES-03 and RES-05 are intentionally absent** — not a gap in this
document, a gap in the ID sequence itself. `test_vplan.py::test_row_ids_
are_unique` only requires IDs to be unique, never contiguous, so nothing
mechanical depends on filling them. Recorded here, explicitly, rather
than left silently missing: these two numbers were never used.

| ID | Spec cite | Assertion | Conditions | Check type | Check artifact | Status |
|----|---|---|---|---|---|---|
| RES-01 | progress.md, Task 1 note | The verification-design spec's premise ("17 sim-proven opcodes, NOP/LDCI excluded: no sim support") is stale: `sim_supports()` reports every implemented instruction (`microcode_gen.INSTRUCTIONS`, all 19, NOP/LDCI included) as executable by the oracle interpreter | every implemented instruction | directed | docs/notes/test_progrom_coverage.py::test_simulator_against_microcode (iterates `INSTRUCTIONS`, asserts `sim_supports(name)` for each — fails if NOP, LDCI, or any other opcode stopped being oracle-executable) | COVERED-DIRECTED |
| RES-02 | CLAUDE.md 2026-08-04 state ("Only LDCI and NOP remain unrun ... both unreachable by design") | LDCI's (and NOP's) FPGA-model behavior has bench silicon ground truth to validate against | — | — | none — LDCI/NOP have never executed on real DINO hardware; the fuzz harness's oracle-vs-gate-model agreement (FUZZ-01) is INTERNALLY self-consistent but has nothing on real silicon to anchor against for these two opcodes specifically | GAP |
| RES-04 | progress.md, Task 7 note | The 6 gated-clock identifiers `n_bo1`/`n_bo2`/`n_bo3`/`n_co1`/`n_co2`/`n_co3` (the `program_counter.vhd` `'193` ripple-carry chain) never rise while sampled machine CLK already reads high, on any whole-core run | multi-cycle, accumulated counter state | directed | fpga/sim/conftest_helpers.py::invariant_monitor (all six ARE in `gated_clocks.txt` and NONE are in `MONITOR_EXCLUDE` — the monitor resolves and RISE-checks them on every whole-core run; `_report_monitor`'s `assert not gaps` would fail loudly if any of the six ever became unresolvable, and a genuine CLK-high rise on any of them fails the run's own invariant assertion) | COVERED-DIRECTED |
| RES-06 | verification-design spec, Track 4 ("prepare_roms CRC guard") — port-phase follow-up, now CLOSED | `roms/*.bin` on disk is content-verified against a fresh in-memory rebuild every `prepare_roms()` call, not just when the mtime heuristic decides to regenerate | every prepare_roms() call | directed | fpga/sim/conftest_helpers.py::_assert_crc (this task's rider); docs/notes/test_vplan.py::test_assert_crc_guard_catches_content_mismatch; docs/notes/test_vplan.py::test_prepare_roms_integration_does_not_raise_against_real_roms | COVERED-DIRECTED |
| RES-07 | verification-design spec, Track 1 ("17 sim-proven opcodes... instruction stream from the 17 sim-proven opcodes") — split off from RES-01 | `fuzz_gen.py`'s `_MENU` continues to include NOP and LDCI as legal generation choices, and generated programs actually contain them from time to time (not merely menu-eligible in theory) | — | — | none — `fuzz_gen.py`'s own module-level assert (`assert all(sim_supports(n) for n in _MENU)`) only checks menu members ARE supported, never that any SPECIFIC name (NOP, LDCI, or any other) remains a member; none of `test_fuzz_gen.py`'s 8 tests check `_MENU` membership or per-opcode selection frequency either — a silent removal of NOP/LDCI from `_MENU` would narrow fuzz coverage with nothing noticing | GAP |

### L. Per-model TTL testbenches (`fpga/ttl/`)

These 18 model TBs anchor every FID/SIM claim about the generated design:
each ultimately rests on these per-part-type models being individually
correct against their own datasheet truth tables.

| ID | Spec cite | Assertion | Conditions | Check type | Check artifact | Status |
|----|---|---|---|---|---|---|
| MDL-01 | port-design spec, "Chip model contract" (combinational parts) | The combinational gate primitives (`'00` NAND, `'02` NOR, `'08` AND, `'04` inverter) match their datasheet truth tables | exhaustive input sweep | exhaustive | fpga/ttl/test_gates.py::nand_truth_table; fpga/ttl/test_gates.py::nor_truth_table; fpga/ttl/test_gates.py::and_truth_table; fpga/ttl/test_gates.py::inverter_truth_table | COVERED-EXHAUSTIVE |
| MDL-02 | port-design spec, "Chip model contract" | The `'138` decoder and `'157` mux match their datasheet truth tables | exhaustive select x enable | exhaustive | fpga/ttl/test_msi.py::decoder_truth_table; fpga/ttl/test_msi.py::mux_truth_table | COVERED-EXHAUSTIVE |
| MDL-03 | port-design spec, "Tri-state parts" | The `'244` buffer drives its outputs when enabled and floats real `'Z'` when disabled | both states | directed | fpga/ttl/test_msi.py::buffer_tri_state | COVERED-DIRECTED |
| MDL-04 | port-design spec, "Tri-state parts" | The `'245` transceiver drives both directions correctly and releases (floats `'Z'`) the side it is not currently driving | both directions, both sides | directed | fpga/ttl/test_msi.py::xcvr_both_directions; fpga/ttl/test_msi.py::xcvr_releases_the_side_it_is_not_driving | COVERED-DIRECTED |
| MDL-05 | port-design spec, "Open items" ("Confirm the '382 model...during its testbench work") | The `'382` ALU matches its datasheet truth table across every op x operand pair x carry-in | exhaustive | exhaustive | fpga/ttl/test_74f382.py::alu_exhaustive | COVERED-EXHAUSTIVE |
| MDL-06 | port-design spec, "ROMs...and RAM" | The ROM models (AT28C64B/AT28C256) read back exactly what was loaded and deselect (float) correctly | both chips, both states | directed | fpga/ttl/test_memory.py::rom64_exact_readback_and_deselect; fpga/ttl/test_memory.py::rom256_exact_readback_and_deselect | COVERED-DIRECTED |
| MDL-07 | port-design spec, "ROMs...and RAM" | The RAM model (MCM60256) writes then reads back correctly under permuted addressing, and releases DQ when deselected | permuted addresses, both states | directed | fpga/ttl/test_memory.py::ram_write_then_read_permuted; fpga/ttl/test_memory.py::ram_releases_dq_when_deselected | COVERED-DIRECTED |
| MDL-08 | port-design spec, "Stateful parts" | The stateful models (`'74`, `'163`, `'193`, `'273`, `'373`) match their datasheet edge-detect/async-clear/transparent-latch behavior | per part | directed | fpga/ttl/test_stateful.py::ff74_edge_and_async; fpga/ttl/test_stateful.py::counter163_sync; fpga/ttl/test_stateful.py::counter193_async; fpga/ttl/test_stateful.py::register273_async_clear; fpga/ttl/test_stateful.py::register273_captures_pre_edge_d; fpga/ttl/test_stateful.py::latch373_transparent; fpga/ttl/test_stateful.py::latch373_no_stale_glitch_on_le_fall | COVERED-DIRECTED |
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

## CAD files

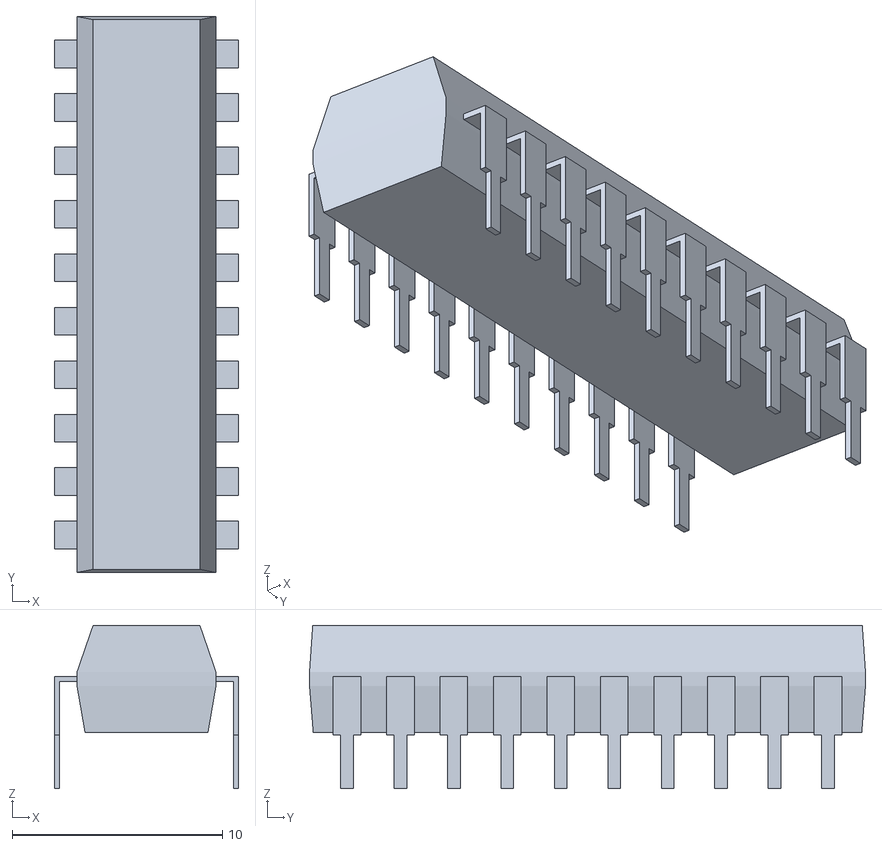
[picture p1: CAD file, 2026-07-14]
dino_v0_0_2/74F382PC/PDIP20_26P42X6P6_ONS.stl
8.76 x 26.4 x 7.75

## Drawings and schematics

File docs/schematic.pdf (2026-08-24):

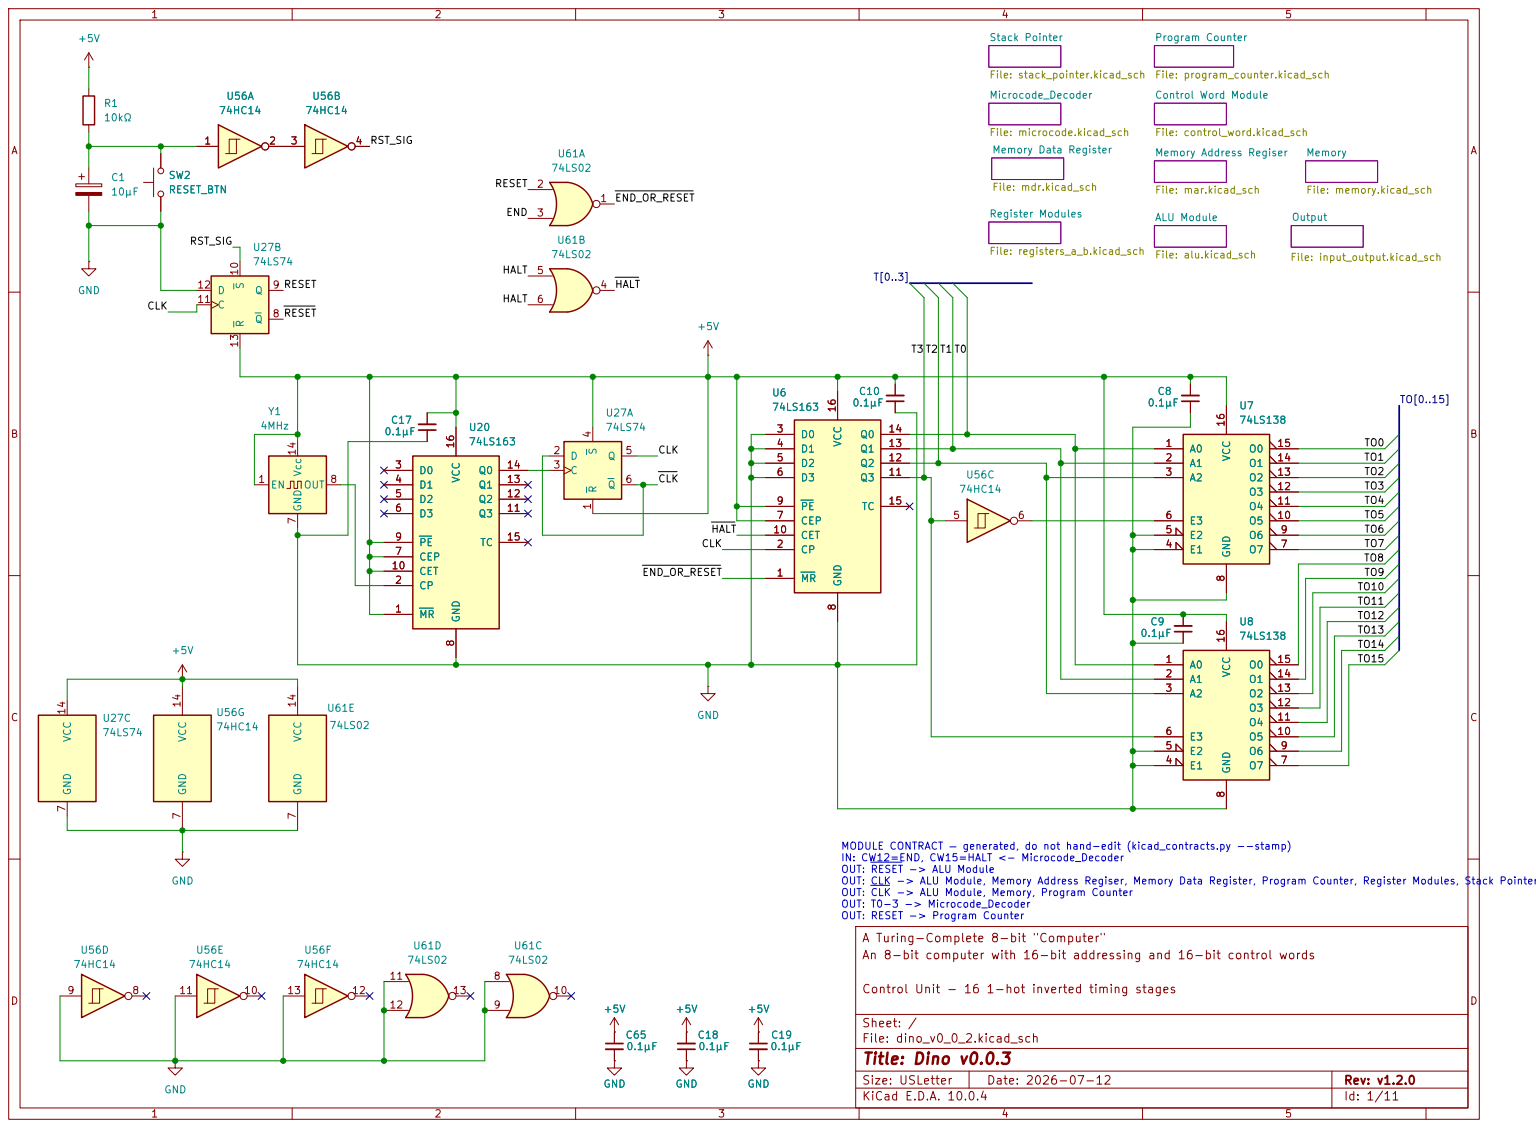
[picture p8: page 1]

File: control_word.kicad_sch Stack Pointer File: stack_pointer.kicad_sch

Memory Address Regiser File: mar.kicad_sch Control Word Module

Memory Data Register File: mdr.kicad_sch Register Modules File: registers_a_b.kicad_sch C8

IN: CW12=END, CW15=HALT <- Microcode_Decoder OUT: RESET -> ALU Module OUT: CLK -> ALU Module, Memory Address Regiser, Memory Data Register, Program Counter, Register Modules, Stack Pointer OUT: CLK -> ALU Module, Memory, Program Counter OUT: T0-3 -> Microcode_Decoder OUT: RESET -> Program Counter

A Turing-Complete 8-bit "Computer"
An 8-bit computer with 16-bit addressing and 16-bit control words

Control Unit - 16 1-hot inverted timing stages

Size: USLetter | Rev: v1.2.0
KiCad E.D.A. 10.0.4 | Id: 1/11

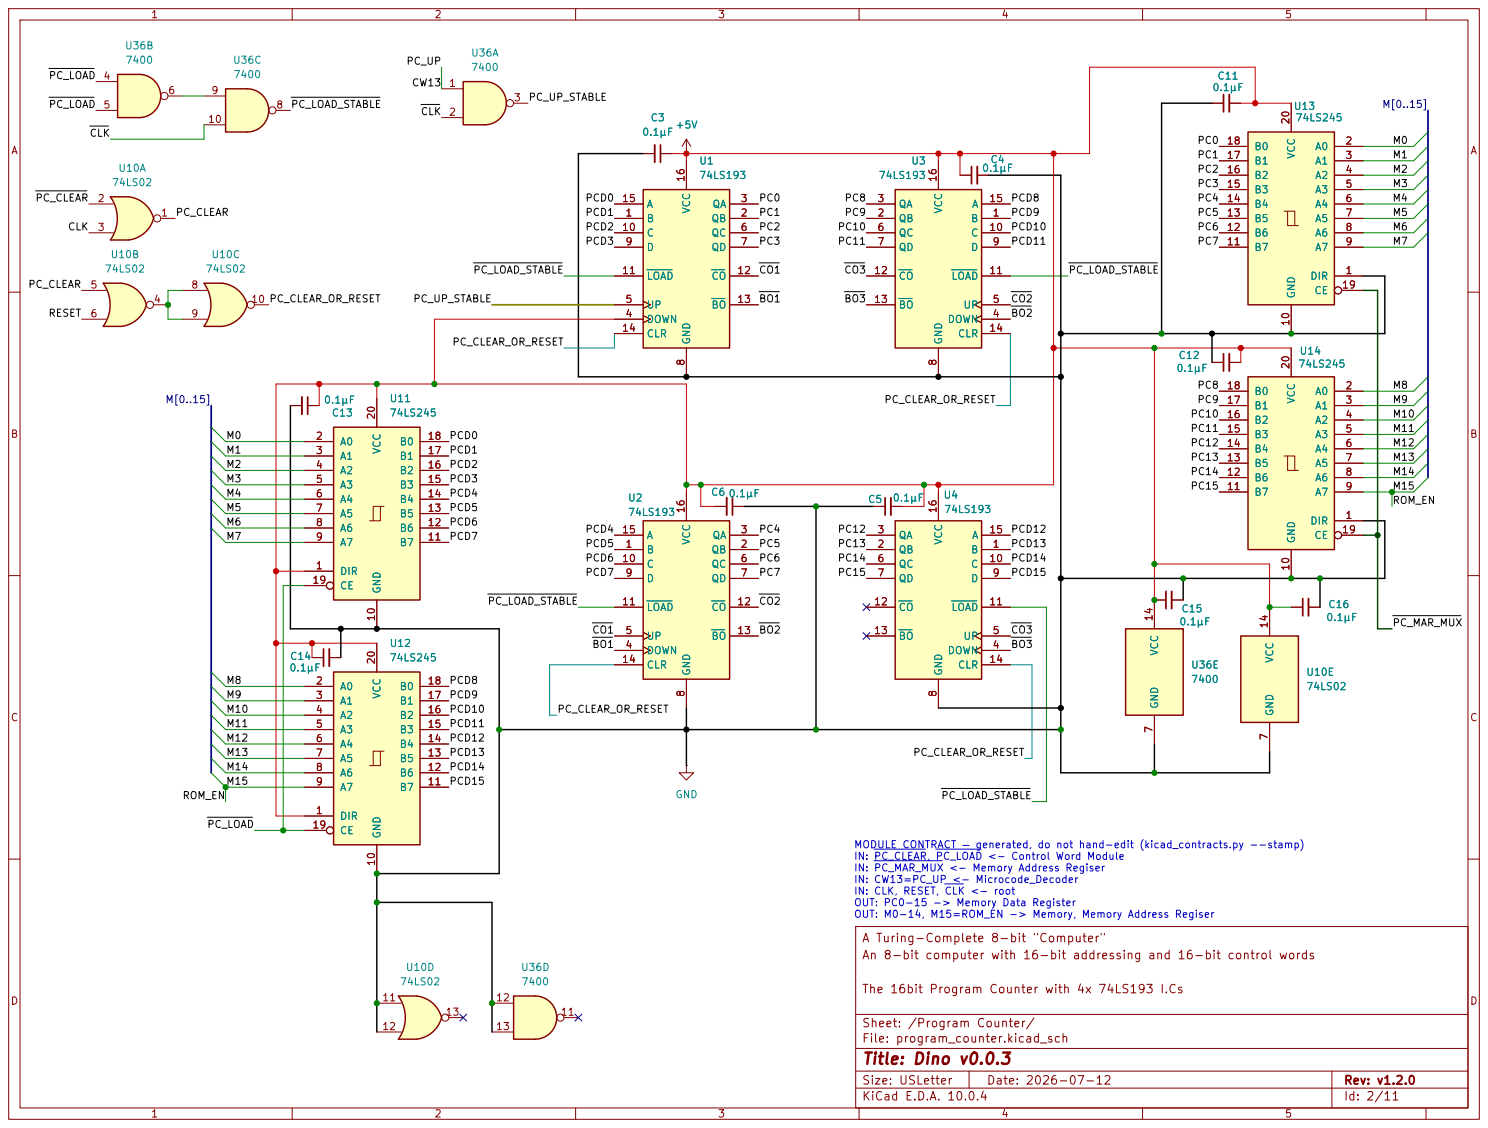
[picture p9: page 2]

A1 3
A2 4
A3 5
A4 6
A5 7
A6 8

IN: CLK, RESET, CLK <- root OUT: PC0-15 -> Memory Data Register OUT: M0-14, M15=ROM_EN -> Memory, Memory Address Regiser C15

IN: PC_CLEAR, PC_LOAD <- Control Word Module
IN: PC_MAR_MUX <- Memory Address Regiser
IN: CW13=PC_UP <- Microcode_Decoder

An 8-bit computer with 16-bit addressing and 16-bit control words

The 16bit Program Counter with 4x 74LS193 I.Cs

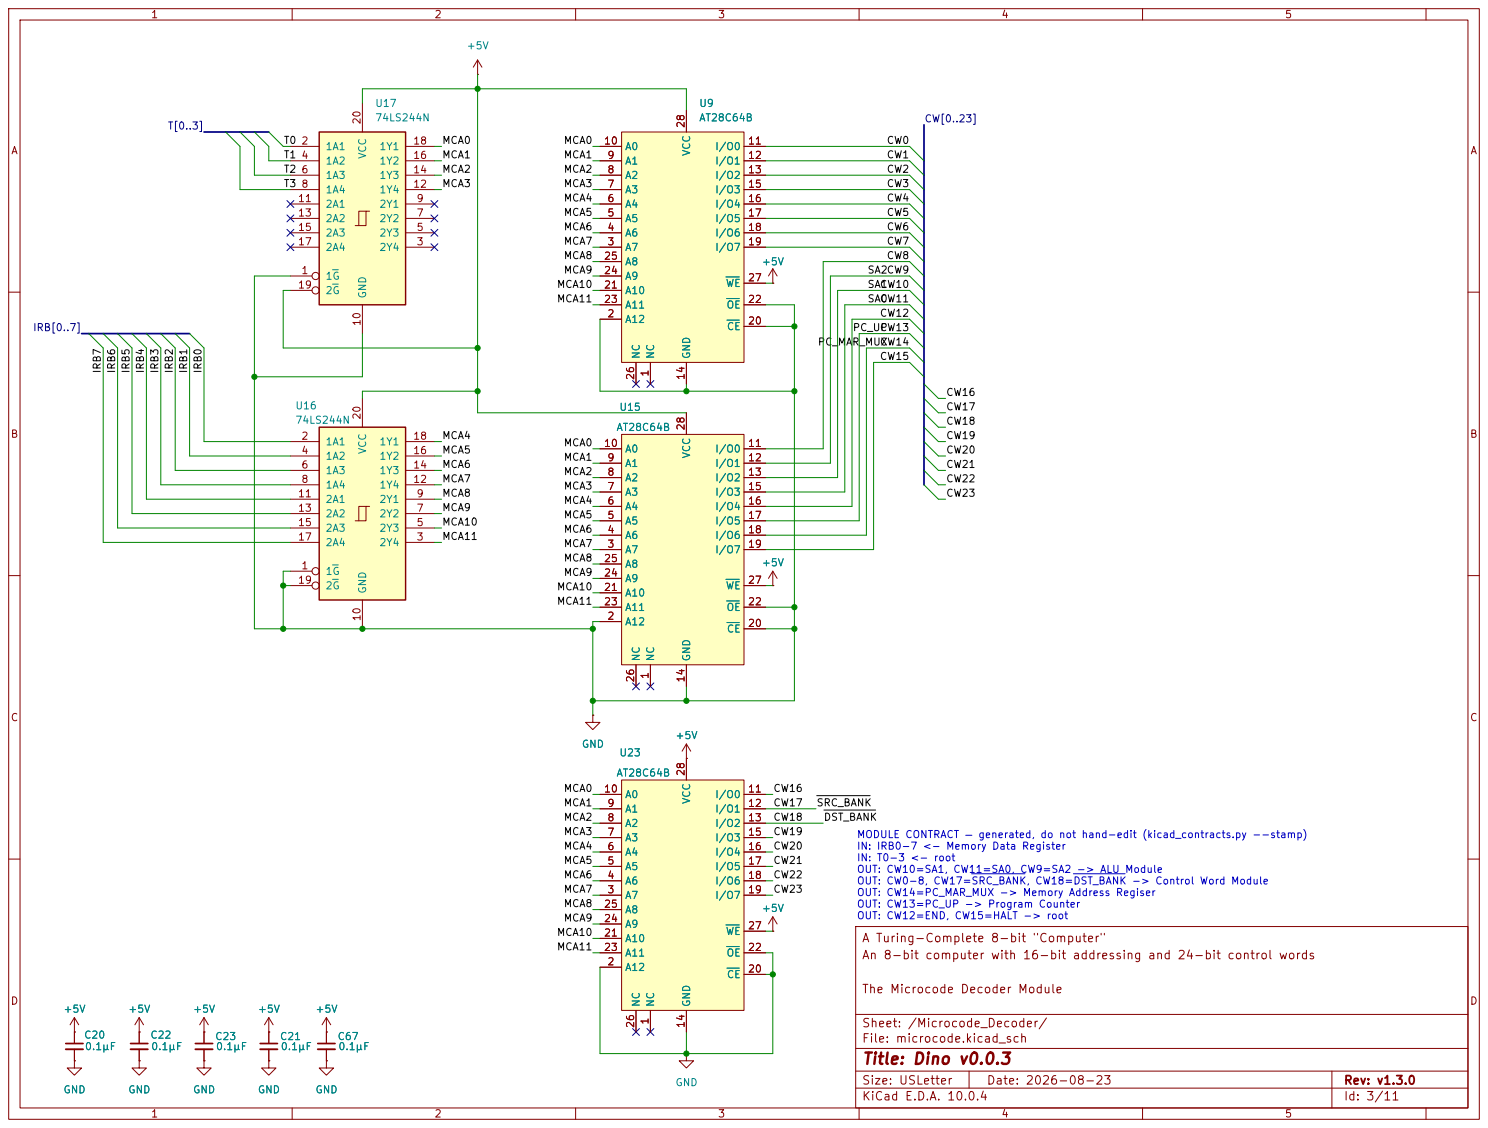
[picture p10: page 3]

CW15 MODULE CONTRACT — generated, do not hand-edit (kicad_contracts.py --stamp)

A Turing-Complete 8-bit "Computer" GND +5V

IN: T0-3 <- root OUT: CW10=SA1, CW11=SA0, CW9=SA2 -> ALU Module OUT: CW0-8, CW17=SRC_BANK, CW18=DST_BANK -> Control Word Module OUT: CW14=PC_MAR_MUX -> Memory Address Regiser OUT: CW13=PC_UP -> Program Counter OUT: CW12=END, CW15=HALT -> root U23

IN: IRB0-7 <- Memory Data Register

An 8-bit computer with 16-bit addressing and 24-bit control words

The Microcode Decoder Module

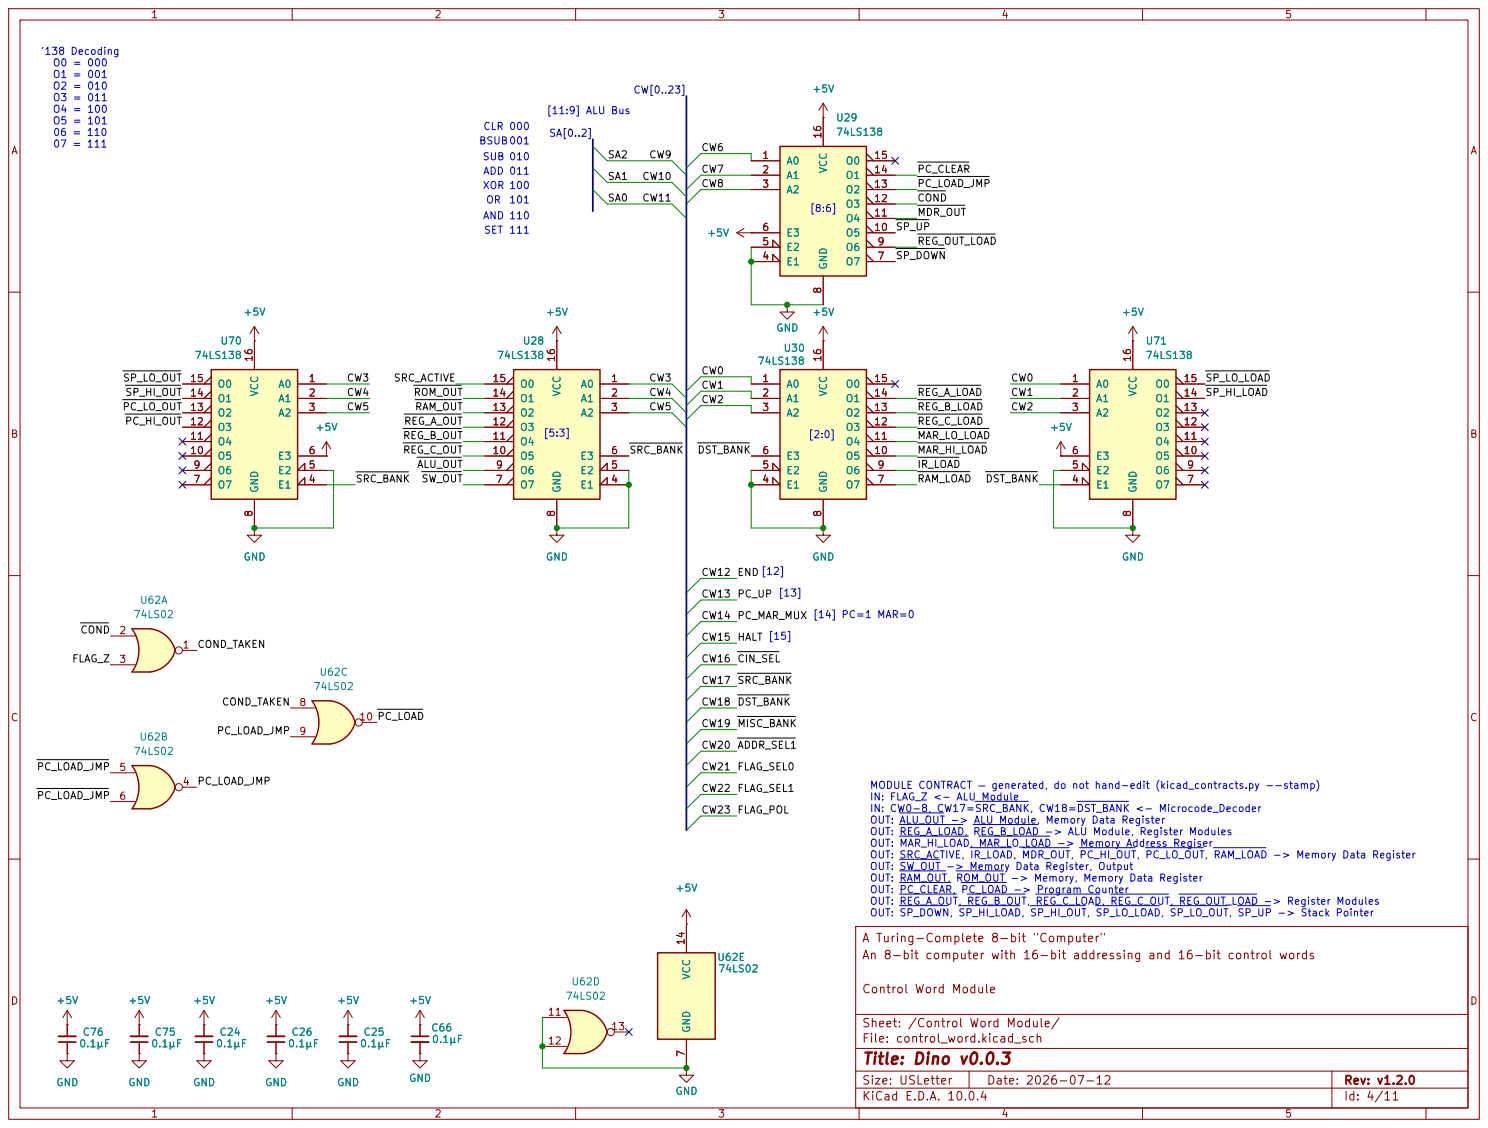
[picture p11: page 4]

A Turing-Complete 8-bit "Computer" GND +5V 4

[15] MODULE CONTRACT — generated, do not hand-edit (kicad_contracts.py --stamp)

IN: FLAG_Z <- ALU Module
IN: CW0-8, CW17=SRC_BANK, CW18=DST_BANK <- Microcode_Decoder OUT: ALU_OUT -> ALU Module, Memory Data Register OUT: REG_A_LOAD, REG_B_LOAD -> ALU Module, Register Modules OUT: MAR_HI_LOAD, MAR_LO_LOAD -> Memory Address Regiser OUT: SRC_ACTIVE, IR_LOAD, MDR_OUT, PC_HI_OUT, PC_LO_OUT, RAM_LOAD -> Memory Data Register OUT: SW_OUT -> Memory Data Register, Output OUT: RAM_OUT, ROM_OUT -> Memory, Memory Data Register OUT: PC_CLEAR, PC_LOAD -> Program Counter OUT: REG_A_OUT, REG_B_OUT, REG_C_LOAD, REG_C_OUT, REG_OUT_LOAD -> Register Modules OUT: SP_DOWN, SP_HI_LOAD, SP_HI_OUT, SP_LO_LOAD, SP_LO_OUT, SP_UP -> Stack Pointer

An 8-bit computer with 16-bit addressing and 16-bit control words

Sheet: /Control Word Module/
File: control_word.kicad_sch
Title: Dino v0.0.3

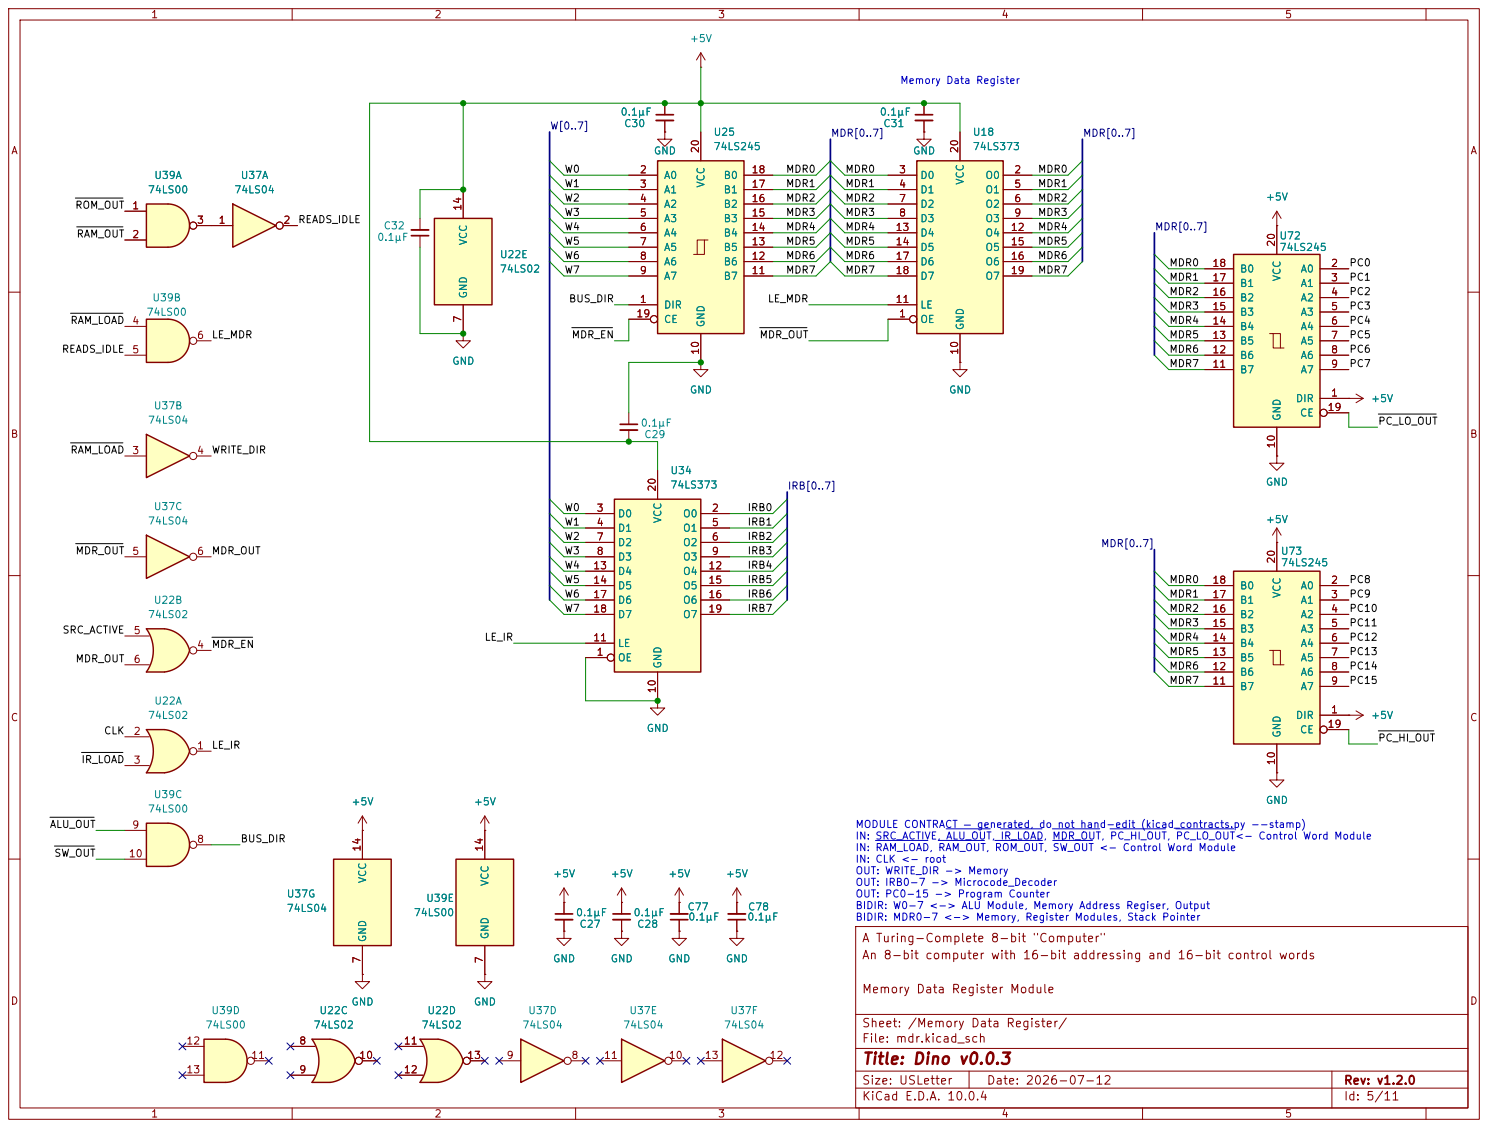
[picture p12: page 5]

7 VCC 14 GND GND +5V GND

IN: SRC_ACTIVE, ALU_OUT, IR_LOAD, MDR_OUT, PC_HI_OUT, PC_LO_OUT<- Control Word Module
IN: RAM_LOAD, RAM_OUT, ROM_OUT, SW_OUT <- Control Word Module
IN: CLK <- root OUT: WRITE_DIR -> Memory OUT: IRB0-7 -> Microcode_Decoder OUT: PC0-15 -> Program Counter BIDIR: W0-7 <-> ALU Module, Memory Address Regiser, Output BIDIR: MDR0-7 <-> Memory, Register Modules, Stack Pointer

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

Memory Data Register Module

Sheet: /Memory Data Register/
File: mdr.kicad_sch
Title: Dino v0.0.3

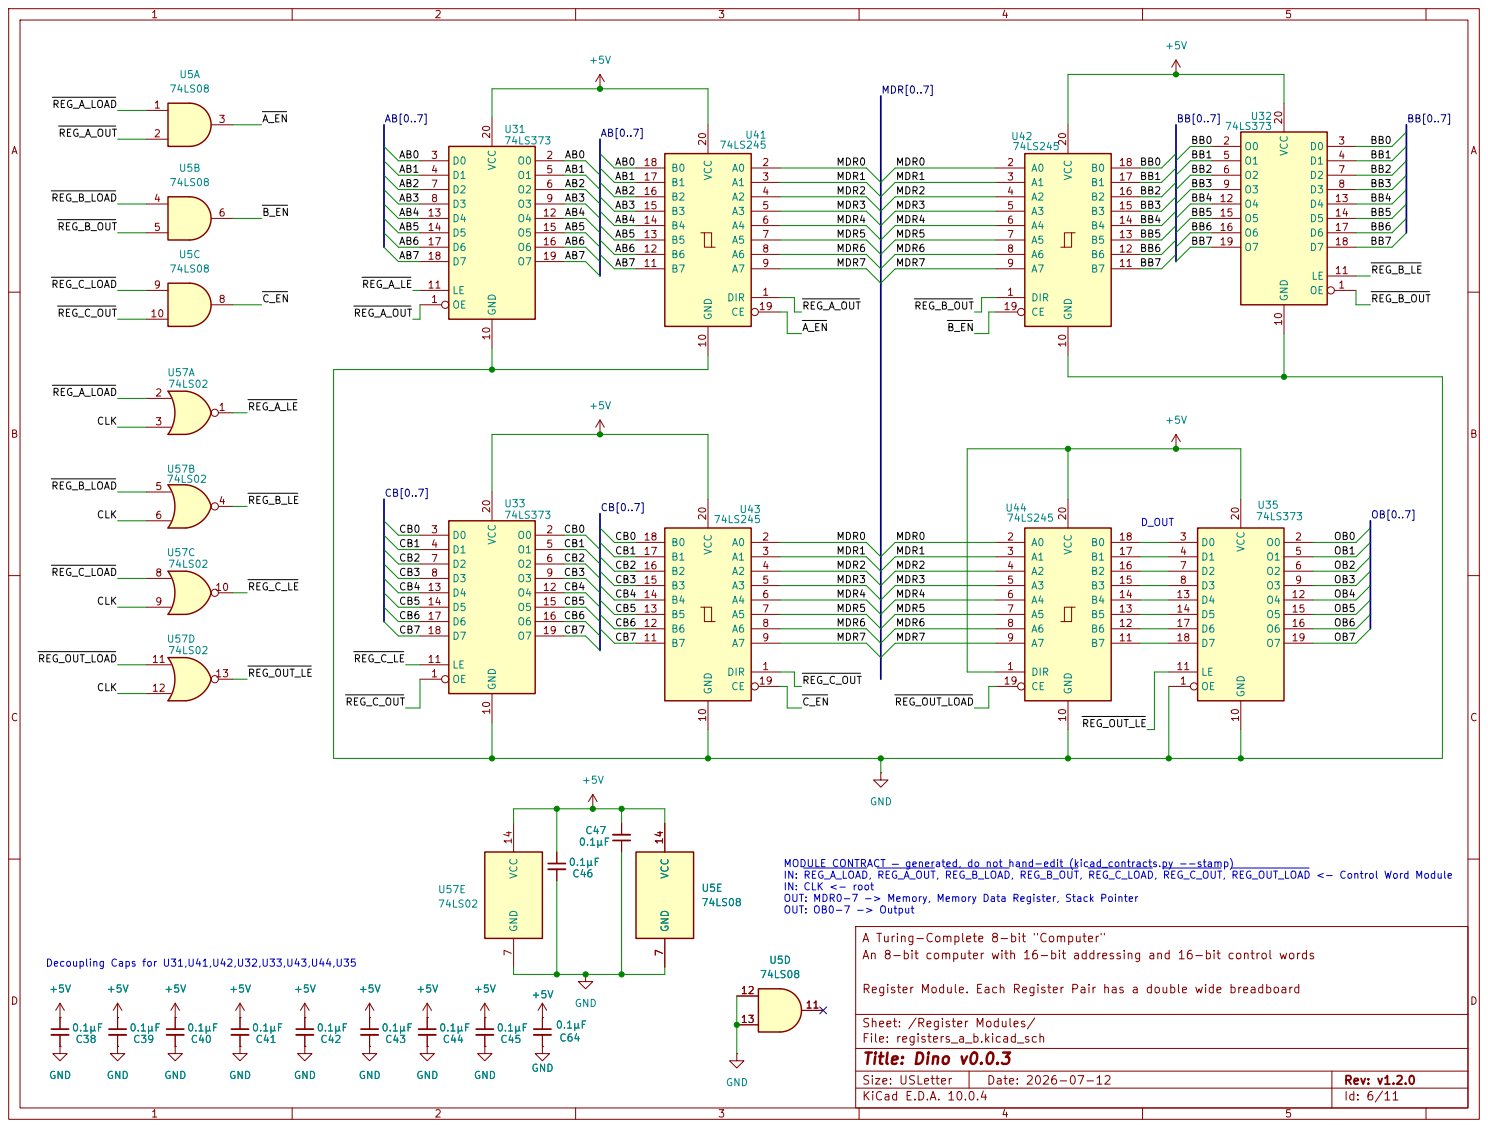
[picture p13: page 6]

IN: REG_A_LOAD, REG_A_OUT, REG_B_LOAD, REG_B_OUT, REG_C_LOAD, REG_C_OUT, REG_OUT_LOAD <- Control Word Module

An 8-bit computer with 16-bit addressing and 16-bit control words

Register Module. Each Register Pair has a double wide breadboard

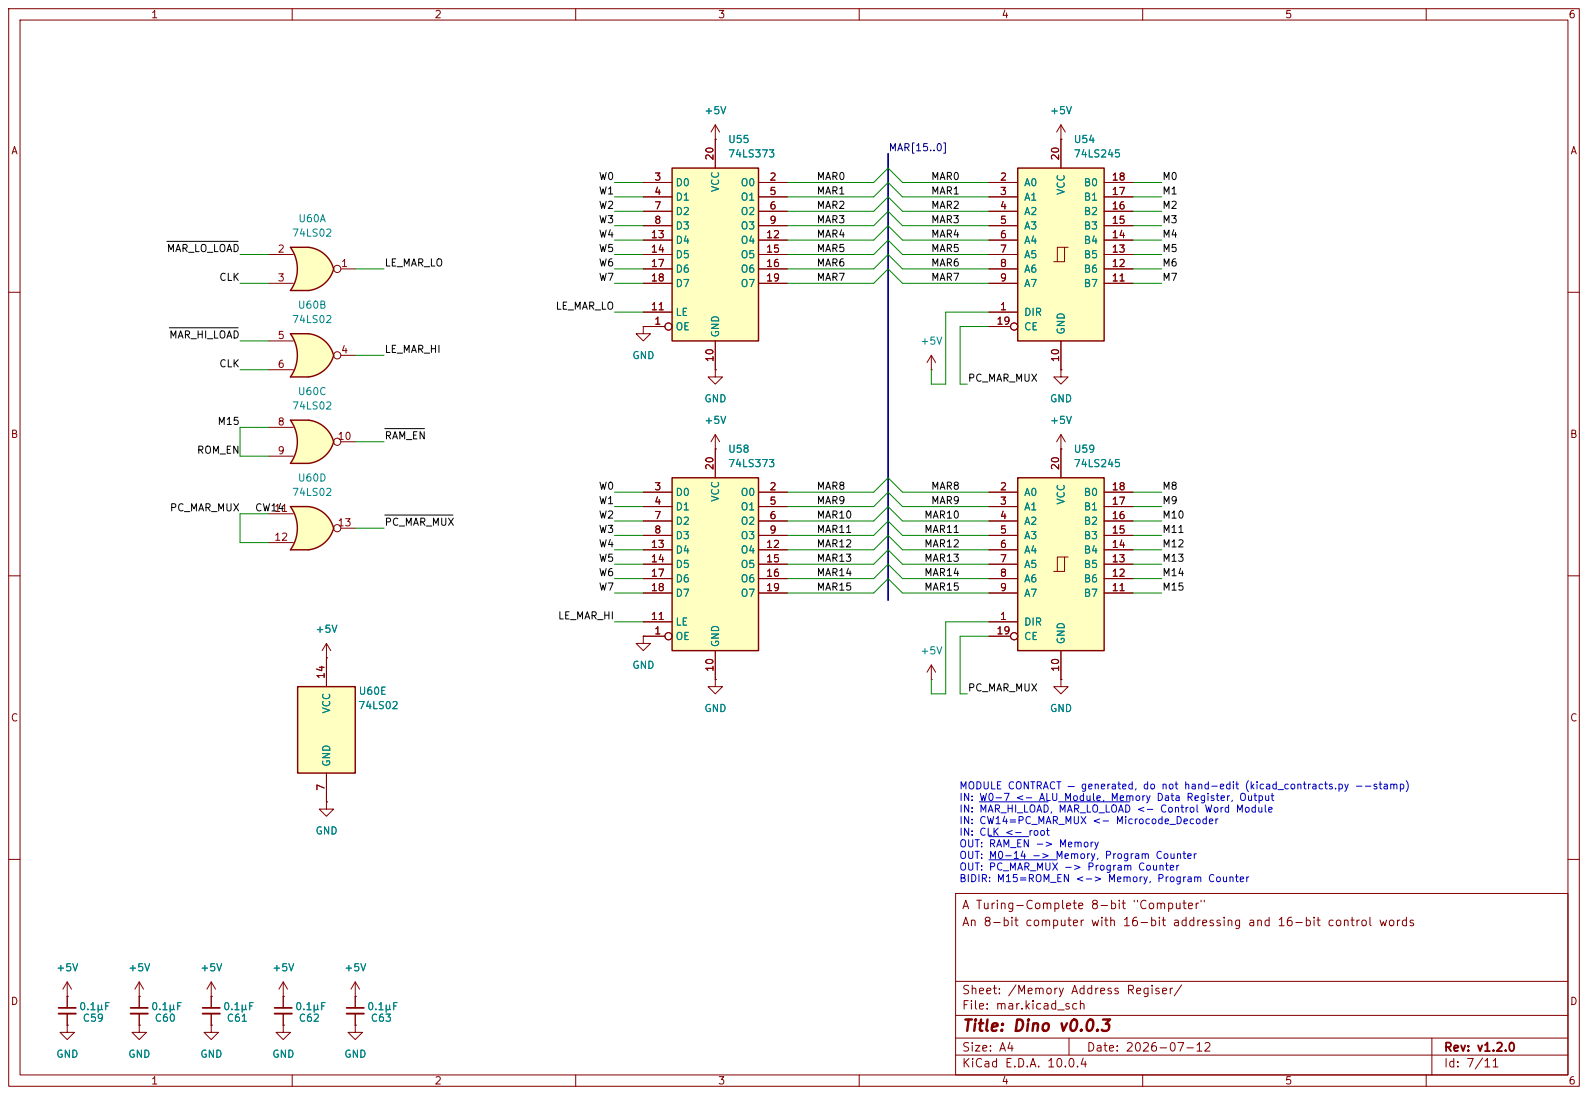
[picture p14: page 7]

IN: W0-7 <- ALU Module, Memory Data Register, Output
IN: MAR_HI_LOAD, MAR_LO_LOAD <- Control Word Module
IN: CW14=PC_MAR_MUX <- Microcode_Decoder

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

Sheet: /Memory Address Regiser/
File: mar.kicad_sch
Title: Dino v0.0.3

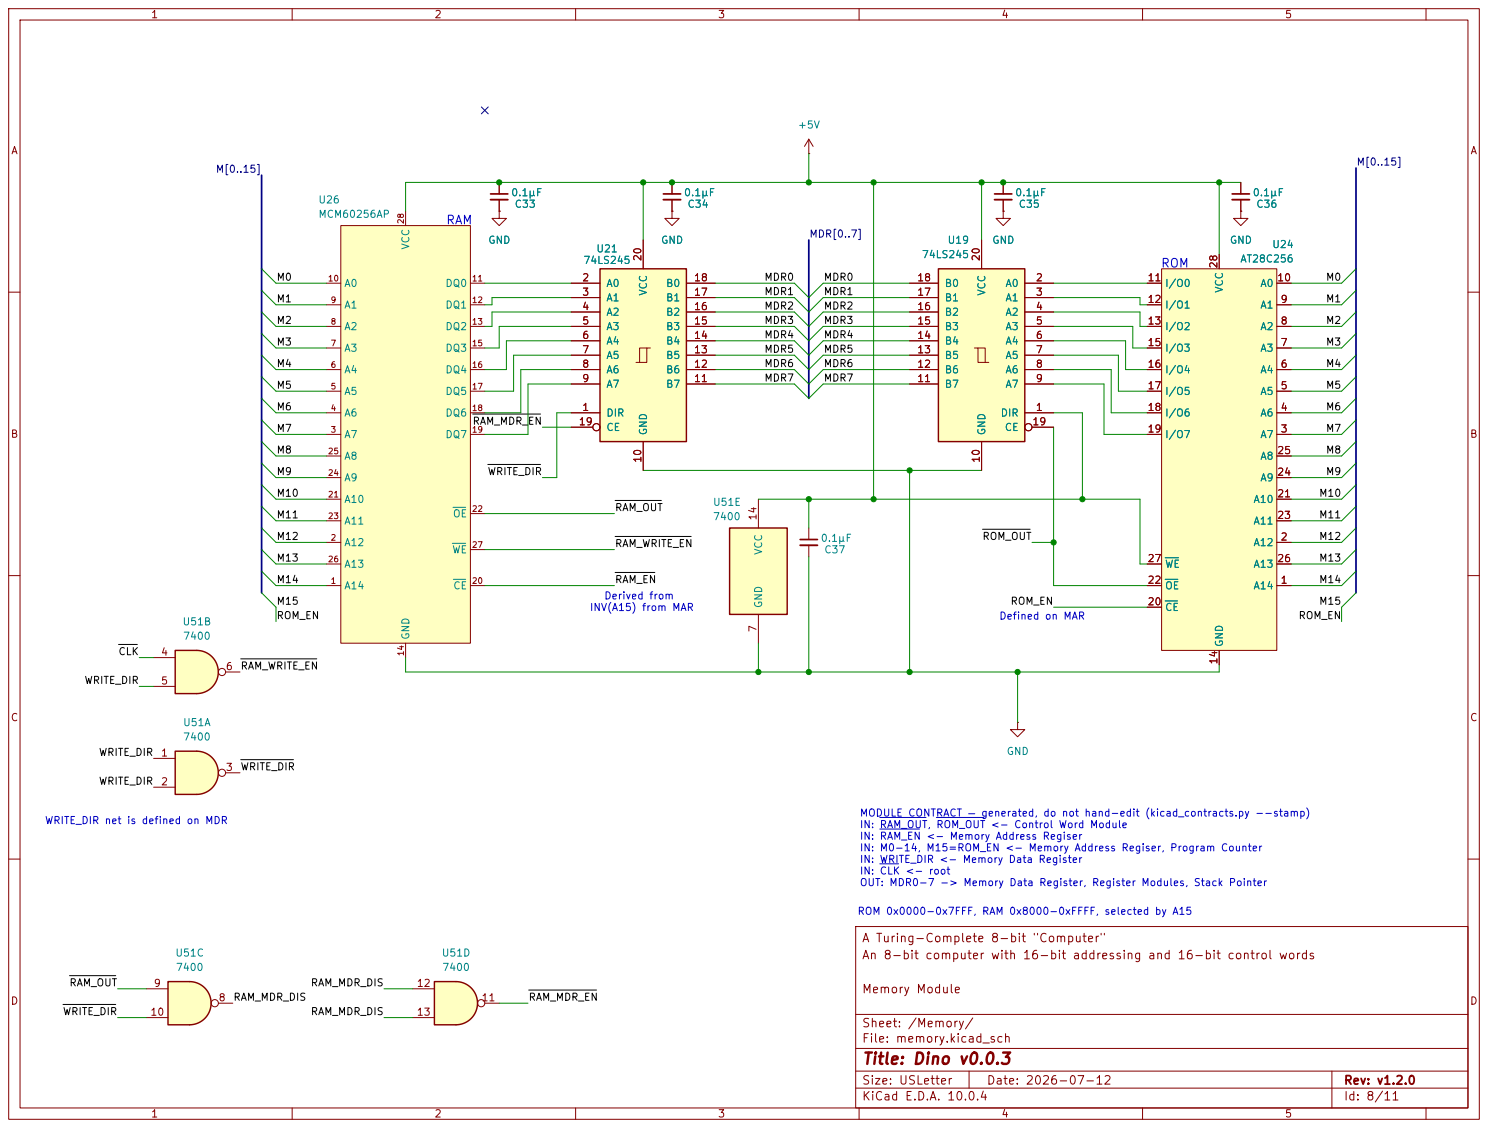
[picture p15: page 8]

INV(A15) from MAR WRITE_DIR net is defined on MDR

ROM 0x0000-0x7FFF, RAM 0x8000-0xFFFF, selected by A15 MODULE CONTRACT — generated, do not hand-edit (kicad_contracts.py --stamp)
IN: RAM_OUT, ROM_OUT <- Control Word Module
IN: RAM_EN <- Memory Address Regiser
IN: M0-14, M15=ROM_EN <- Memory Address Regiser, Program Counter
IN: WRITE_DIR <- Memory Data Register
IN: CLK <- root OUT: MDR0-7 -> Memory Data Register, Register Modules, Stack Pointer

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

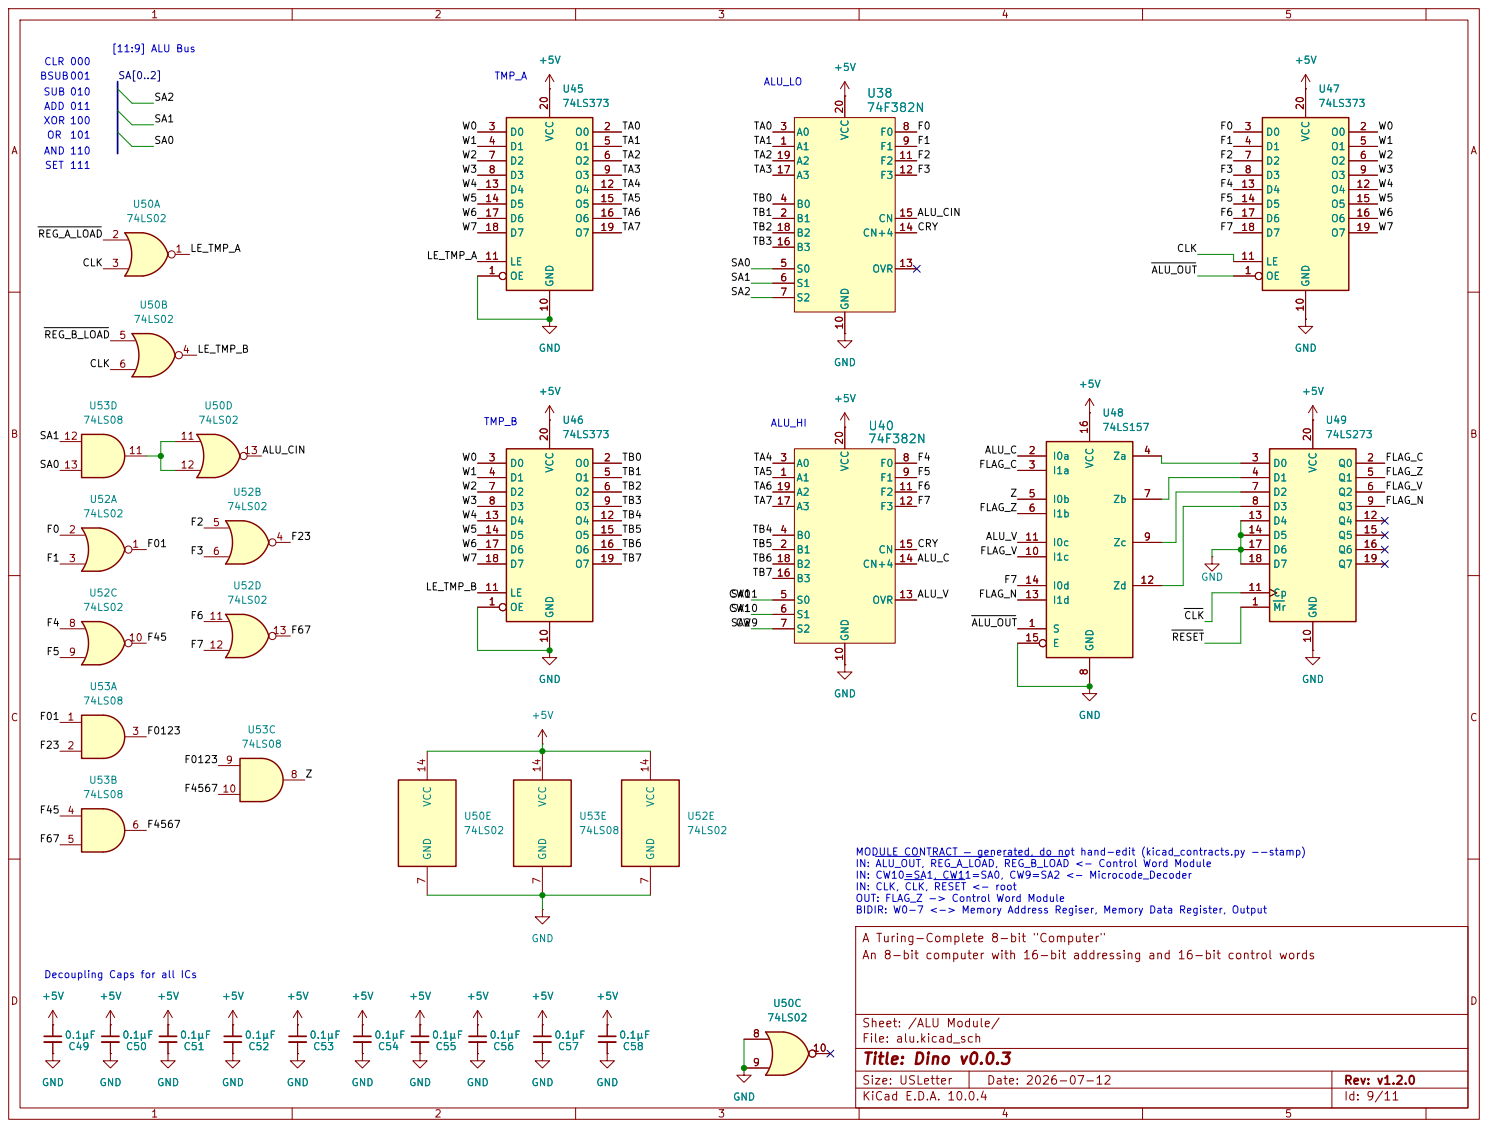
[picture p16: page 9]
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

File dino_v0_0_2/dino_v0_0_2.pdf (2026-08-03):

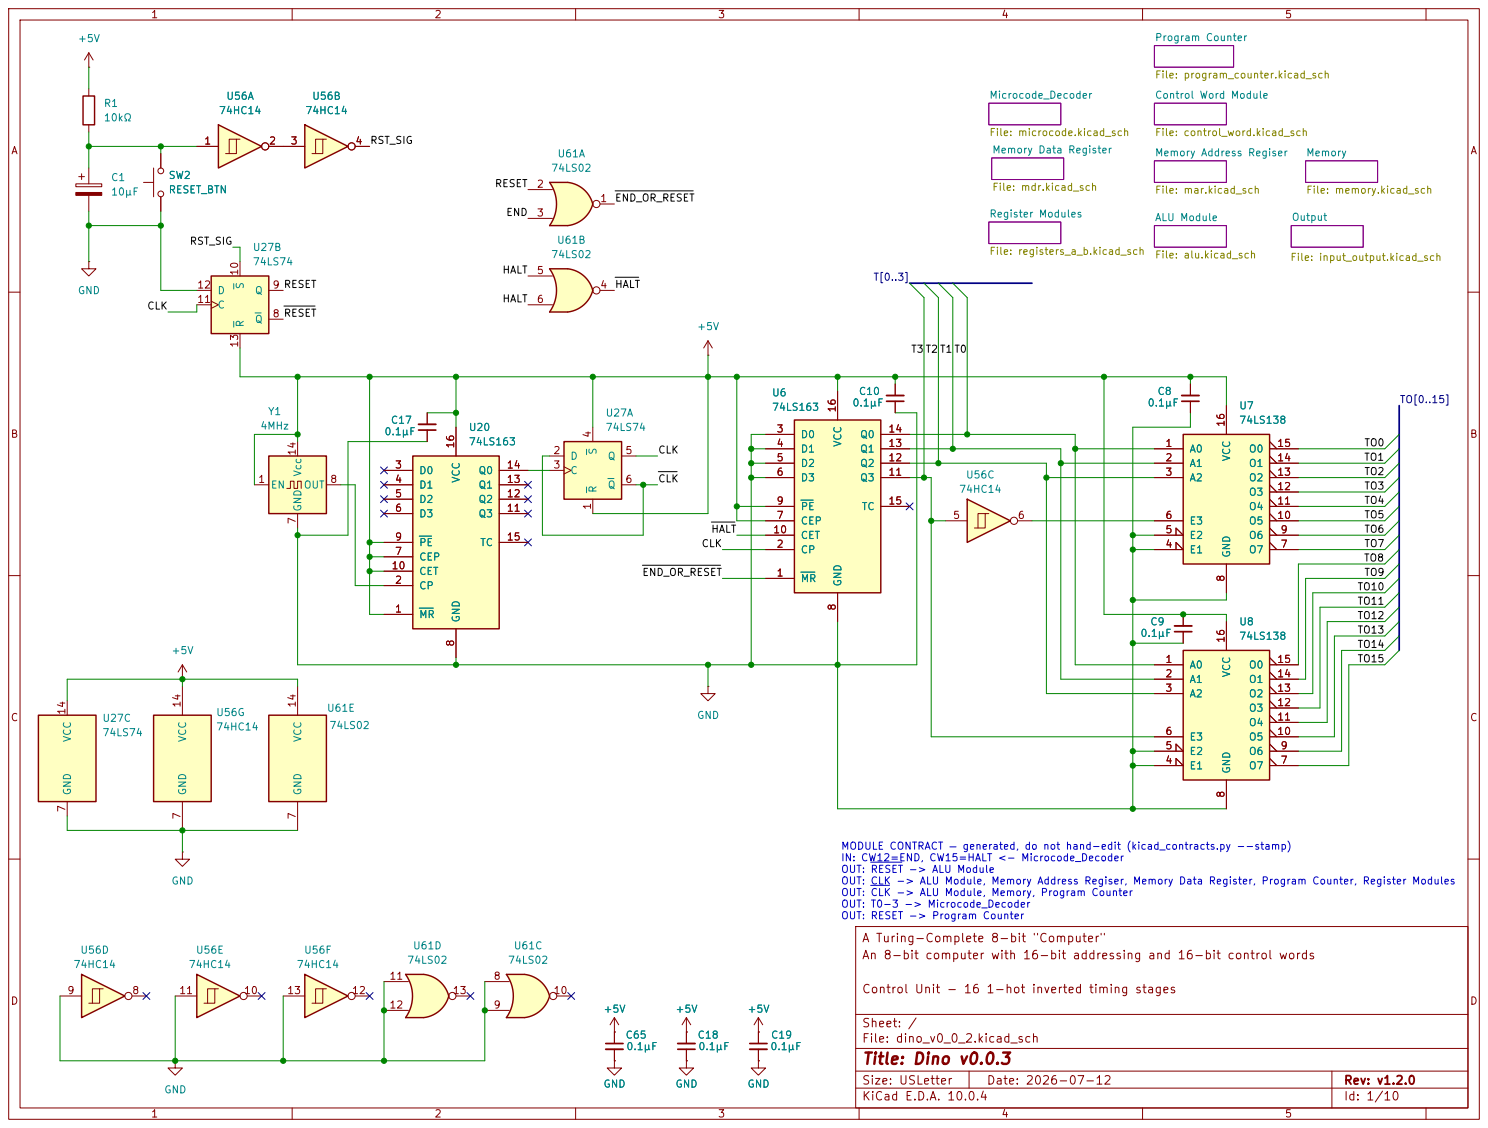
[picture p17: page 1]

File: alu.kicad_sch Program Counter File: program_counter.kicad_sch

Memory Address Regiser File: mar.kicad_sch Control Word Module

A Turing-Complete 8-bit "Computer"
An 8-bit computer with 16-bit addressing and 16-bit control words

Control Unit - 16 1-hot inverted timing stages

Size: USLetter | Rev: v1.2.0
KiCad E.D.A. 10.0.4 | Id: 1/10

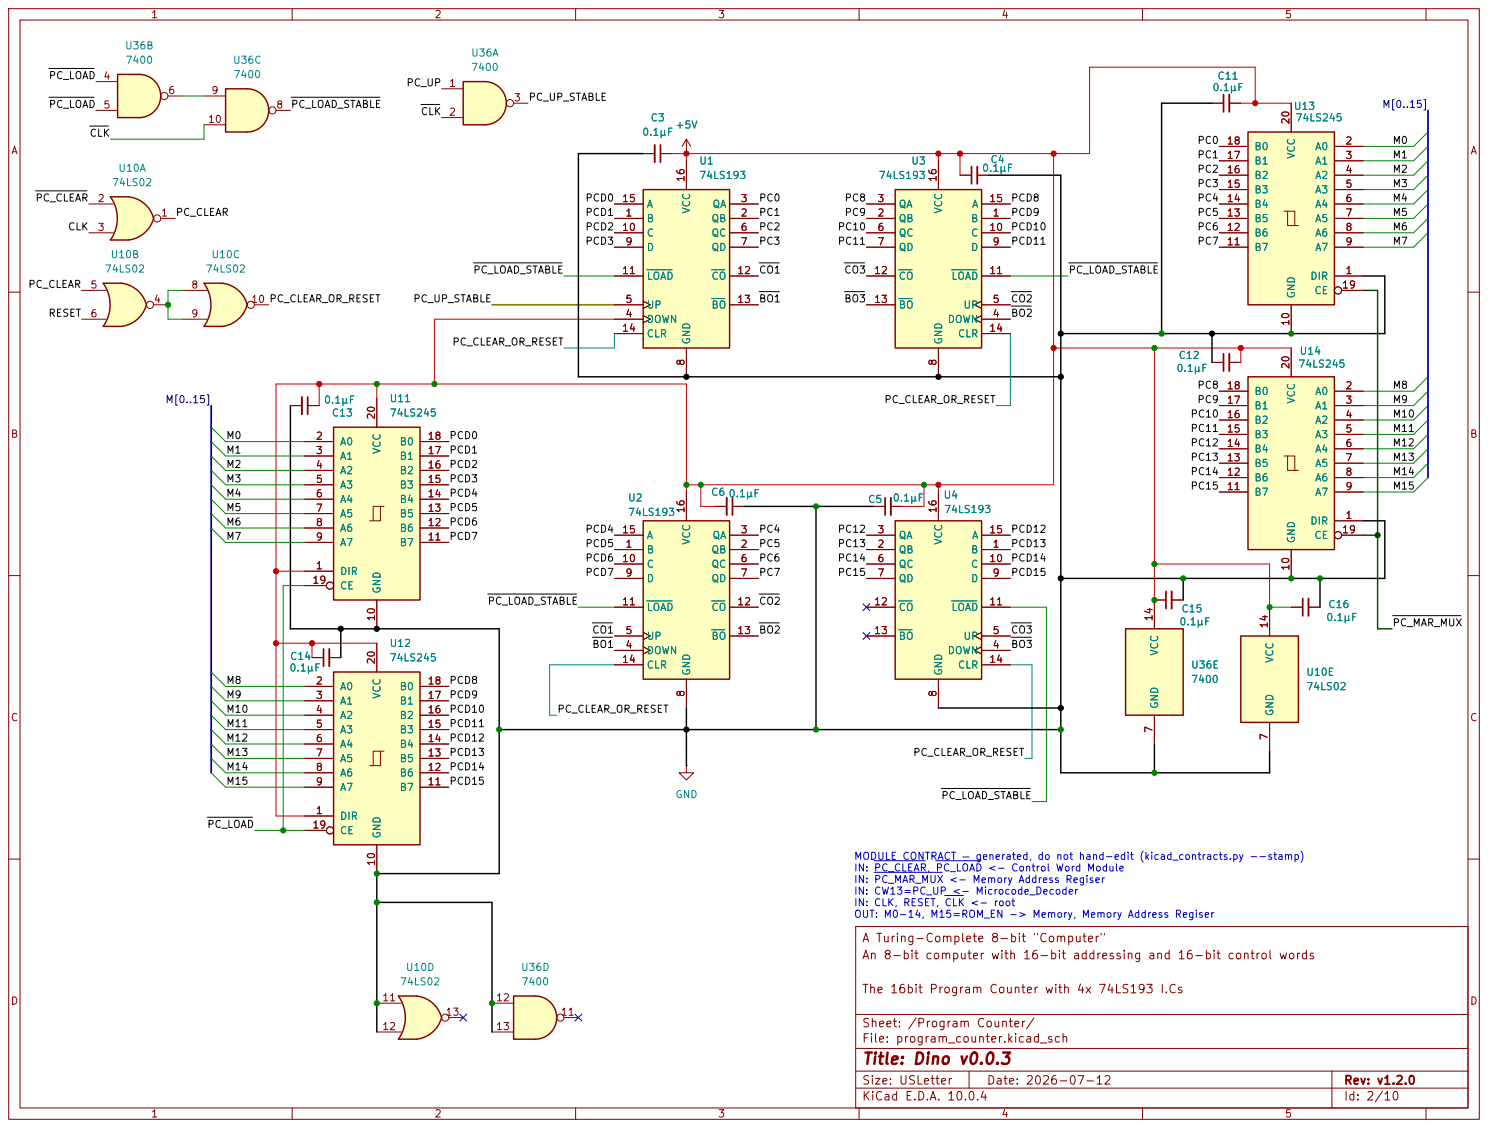
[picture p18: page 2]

IN: PC_CLEAR, PC_LOAD <- Control Word Module
IN: PC_MAR_MUX <- Memory Address Regiser
IN: CW13=PC_UP <- Microcode_Decoder
IN: CLK, RESET, CLK <- root OUT: M0-14, M15=ROM_EN -> Memory, Memory Address Regiser

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

The 16bit Program Counter with 4x 74LS193 I.Cs

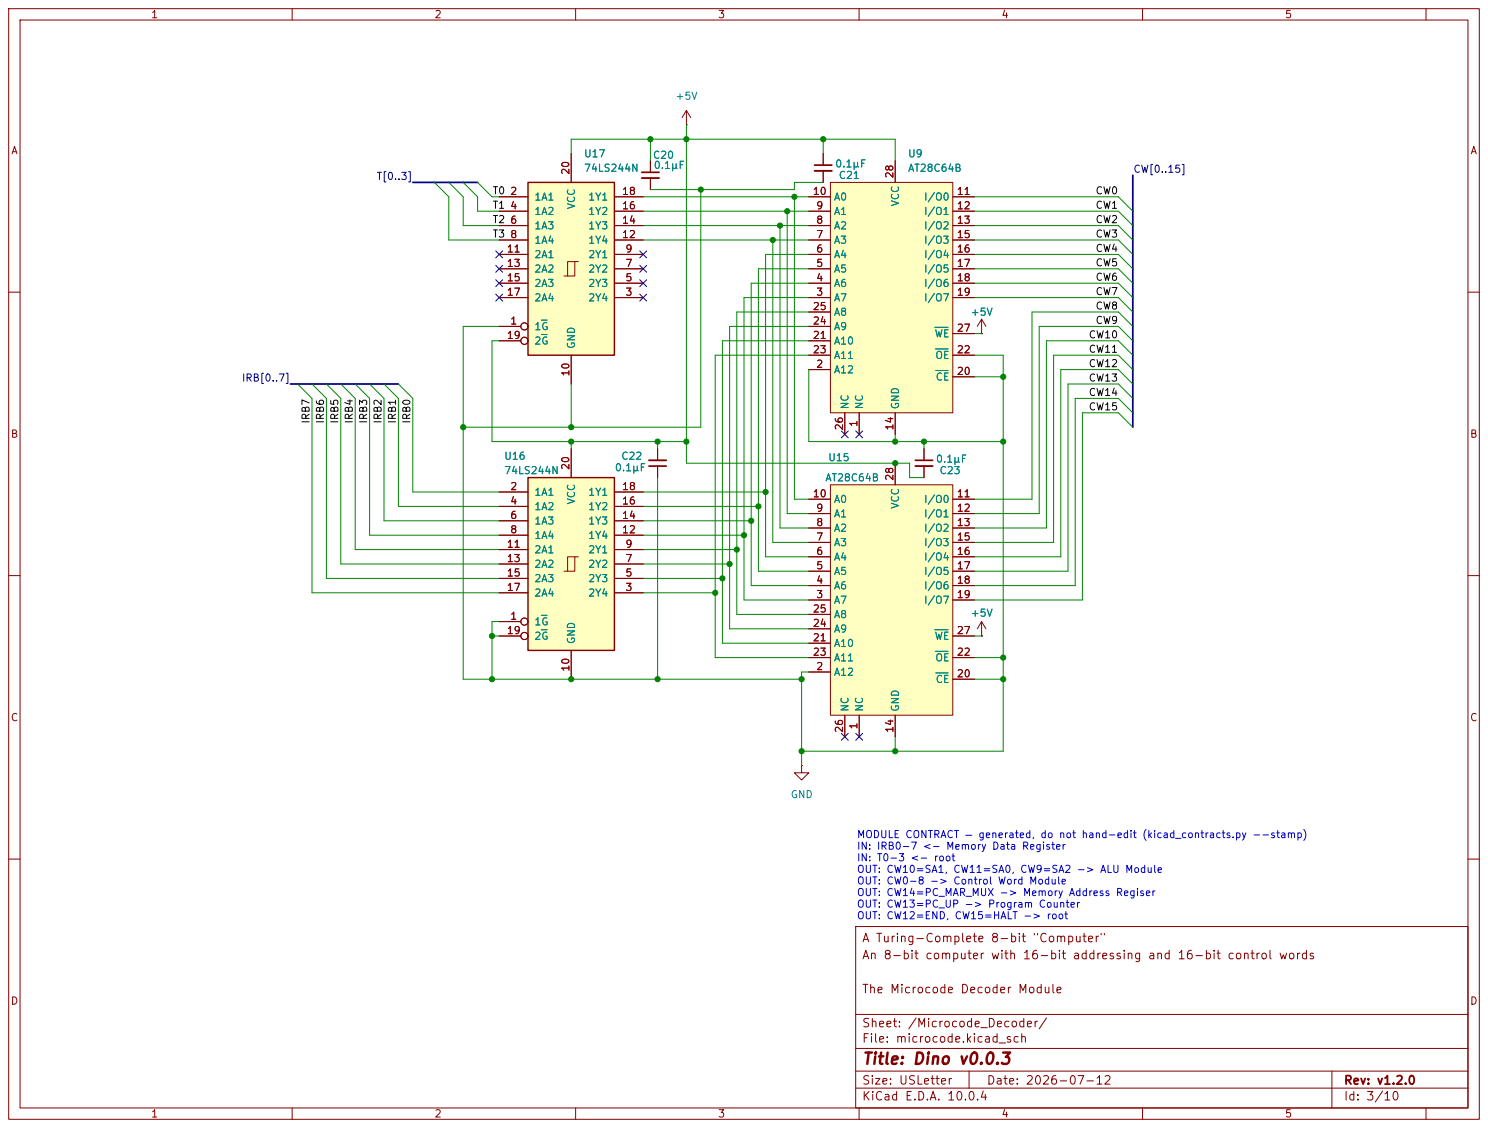
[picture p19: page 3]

IN: T0-3 <- root OUT: CW10=SA1, CW11=SA0, CW9=SA2 -> ALU Module OUT: CW0-8 -> Control Word Module OUT: CW14=PC_MAR_MUX -> Memory Address Regiser OUT: CW13=PC_UP -> Program Counter OUT: CW12=END, CW15=HALT -> root U15

IN: IRB0-7 <- Memory Data Register

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

The Microcode Decoder Module


010 MODULE CONTRACT — generated, do not hand-edit (kicad_contracts.py --stamp)

IN: FLAG_Z <- ALU Module
IN: CW0-8 <- Microcode_Decoder OUT: ALU_OUT -> ALU Module, Memory Data Register OUT: REG_A_LOAD, REG_B_LOAD -> ALU Module, Register Modules OUT: MAR_HI_LOAD, MAR_LO_LOAD -> Memory Address Regiser OUT: SRC_ACTIVE, IR_LOAD, MDR_OUT, RAM_LOAD -> Memory Data Register OUT: SW_OUT -> Memory Data Register, Output OUT: RAM_OUT, ROM_OUT -> Memory, Memory Data Register OUT: PC_CLEAR, PC_LOAD -> Program Counter OUT: REG_A_OUT, REG_B_OUT, REG_C_LOAD, REG_C_OUT, REG_OUT_LOAD -> Register Modules

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

Sheet: /Control Word Module/
File: control_word.kicad_sch
Title: Dino v0.0.3


Memory Data Register MODULE CONTRACT — generated, do not hand-edit (kicad_contracts.py --stamp)
74LS245 DIR 1

IN: CLK <- root OUT: WRITE_DIR -> Memory OUT: IRB0-7 -> Microcode_Decoder BIDIR: W0-7 <-> ALU Module, Memory Address Regiser, Output BIDIR: MDR0-7 <-> Memory, Register Modules C28

A Turing-Complete 8-bit "Computer" GND

IN: SRC_ACTIVE, ALU_OUT, IR_LOAD, MDR_OUT, RAM_LOAD, RAM_OUT, ROM_OUT, SW_OUT <- Control Word Module

An 8-bit computer with 16-bit addressing and 16-bit control words

Memory Data Register Module

Sheet: /Memory Data Register/
File: mdr.kicad_sch
Title: Dino v0.0.3


IN: REG_A_LOAD, REG_A_OUT, REG_B_LOAD, REG_B_OUT, REG_C_LOAD, REG_C_OUT, REG_OUT_LOAD <- Control Word Module

An 8-bit computer with 16-bit addressing and 16-bit control words

Register Module. Each Register Pair has a double wide breadboard


IN: CLK <- root OUT: RAM_EN -> Memory OUT: M0-14 -> Memory, Program Counter OUT: PC_MAR_MUX -> Program Counter BIDIR: M15=ROM_EN <-> Memory, Program Counter GND U59

IN: W0-7 <- ALU Module, Memory Data Register, Output
IN: MAR_HI_LOAD, MAR_LO_LOAD <- Control Word Module
IN: CW14=PC_MAR_MUX <- Microcode_Decoder

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

Sheet: /Memory Address Regiser/
File: mar.kicad_sch
Title: Dino v0.0.3


IN: CLK <- root OUT: MDR0-7 -> Memory Data Register, Register Modules ROM 0x0000-0x7FFF, RAM 0x8000-0xFFFF, selected by A15 Defined on MAR

A Turing-Complete 8-bit "Computer" 4

IN: RAM_OUT, ROM_OUT <- Control Word Module
IN: RAM_EN <- Memory Address Regiser
IN: M0-14, M15=ROM_EN <- Memory Address Regiser, Program Counter
IN: WRITE_DIR <- Memory Data Register

An 8-bit computer with 16-bit addressing and 16-bit control words


A Turing-Complete 8-bit "Computer" GND

IN: ALU_OUT, REG_A_LOAD, REG_B_LOAD <- Control Word Module
IN: CW10=SA1, CW11=SA0, CW9=SA2 <- Microcode_Decoder
IN: CLK, CLK, RESET <- root OUT: FLAG_Z -> Control Word Module BIDIR: W0-7 <-> Memory Address Regiser, Memory Data Register, Output

An 8-bit computer with 16-bit addressing and 16-bit control words

Decoupling Caps for all ICs


A Turing-Complete 8-bit "Computer" R24

IN: SW_OUT <- Control Word Module
IN: OB0-7 <- Register Modules OUT: W0-7 -> ALU Module, Memory Address Regiser, Memory Data Register

An 8-bit computer with 16-bit addressing and 16-bit control words

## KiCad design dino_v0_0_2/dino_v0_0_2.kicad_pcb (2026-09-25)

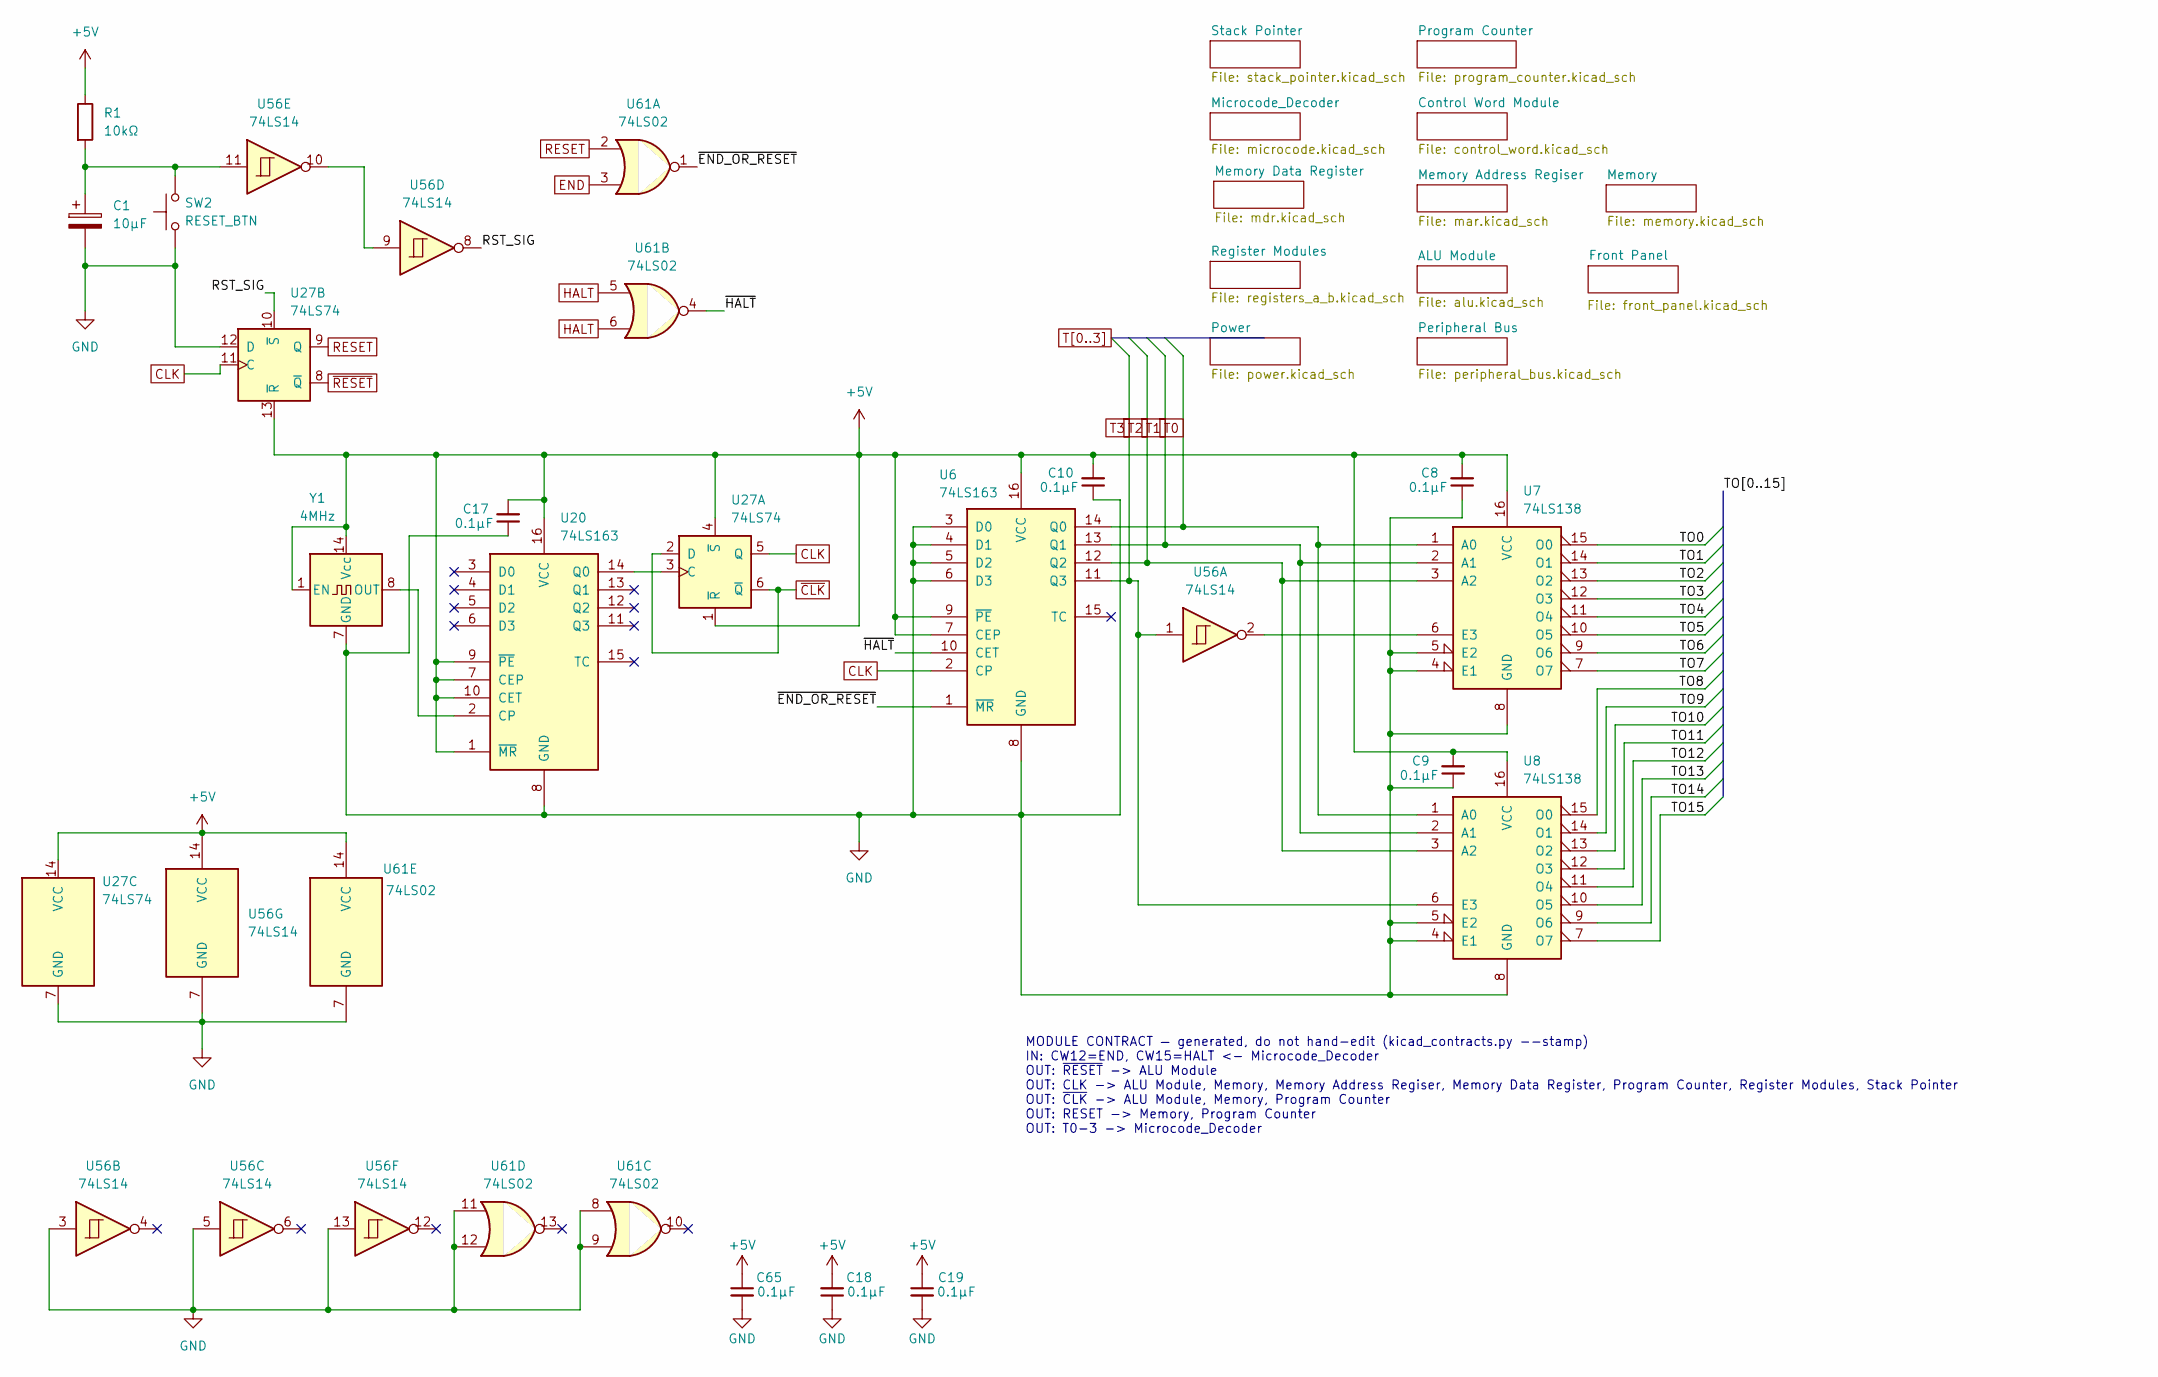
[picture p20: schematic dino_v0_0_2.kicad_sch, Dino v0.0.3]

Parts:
C1: 10µF; CP_Radial_D5.0mm_P2.00mm
C8, C9, C10, C17, C18, C19, C65: 0.1µF; C_Disc_D5.0mm_W2.5mm_P2.50mm
R1: 10kΩ; R_Axial_DIN0207_L6.3mm_D2.5mm_P10.16mm_Horizontal
SW2: RESET_BTN; SW_PUSH_6mm
U6, U20: 74LS163; DIP-16_W7.62mm
U7, U8: 74LS138; DIP-16_W7.62mm
U27: 74LS74; DIP-14_W7.62mm
U56: 74LS14; DIP-14_W7.62mm
U61: 74LS02; DIP-14_W7.62mm
Y1: 4MHz; Oscillator_DIP-14

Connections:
+5V: C8.2, C9.2, C10.2, C17.2, C18.2, C19.1, C65.1, R1.1, U6.7 (CEP), U6.9 (~PE), U6.16 (VCC), U7.16 (VCC), U8.16 (VCC), U20.1 (~MR), U20.7 (CEP), U20.9 (~PE), U20.10 (CET), U20.16 (VCC), U27.1 (~R), U27.4 (~S), U27.13 (~R), U27.14 (VCC), U56.14 (VCC), U61.14 (VCC), Y1.1 (EN), Y1.14 (Vcc); also elsewhere on the board
/RST_SIG: U27.10 (~S), U56.8
/TO0: U7.15 (O0)
/TO1: U7.14 (O1)
/TO2: U7.13 (O2)
/TO3: U7.12 (O3)
/TO4: U7.11 (O4)
/TO5: U7.10 (O5)
/TO6: U7.9 (O6)
/TO7: U7.7 (O7)
/TO8: U8.15 (O0)
/TO9: U8.14 (O1)
/TO10: U8.13 (O2)
/TO11: U8.12 (O3)
/TO12: U8.11 (O4)
/TO13: U8.10 (O5)
/TO14: U8.9 (O6)
/TO15: U8.7 (O7)
/~END_OR_RESET: U6.1 (~MR), U61.1
/~HALT: U6.10 (CET), U61.4
CLK: U6.2 (CP), U27.5 (Q), U27.11 (C); also elsewhere on the board
GND: C1.2, C8.1, C9.1, C10.1, C17.1, C18.1, C19.2, C65.2, SW2.1, U6.3 (D0), U6.4 (D1), U6.5 (D2), U6.6 (D3), U6.8 (GND), U7.4 (E1), U7.5 (E2), U7.8 (GND), U8.4 (E1), U8.5 (E2), U8.8 (GND), U20.8 (GND), U27.7 (GND), U27.12 (D), U56.3, U56.5, U56.7 (GND), U56.13, U61.7 (GND), U61.8, U61.9, U61.11, U61.12, Y1.7 (GND); also elsewhere on the board
unnamed: C1.1, R1.2, SW2.2, U56.11
unnamed: U7.6 (E3), U56.2
unnamed: U20.2 (CP), Y1.8 (OUT)
unnamed: U20.14 (Q0), U27.3 (C)
unnamed: U56.9, U56.10
RESET: U27.9 (Q), U61.2; also elsewhere on the board
T0: U6.14 (Q0), U7.1 (A0), U8.1 (A0); also elsewhere on the board
T1: U6.13 (Q1), U7.2 (A1), U8.2 (A1); also elsewhere on the board
T2: U6.12 (Q2), U7.3 (A2), U8.3 (A2); also elsewhere on the board
T3: U6.11 (Q3), U8.6 (E3), U56.1; also elsewhere on the board
~CLK: U27.2 (D), U27.6 (~Q); also elsewhere on the board
~RESET: U27.8 (~Q); also elsewhere on the board

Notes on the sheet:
MODULE CONTRACT — generated, do not hand-edit (kicad_contracts.py --stamp) IN: CW12=END, CW15=HALT <- Microcode_Decoder OUT: ~{RESET} -> ALU Module OUT: CLK -> ALU Module, Memory, Memory Address Regiser, Memory Data Register, Program Counter, Register Modules, Stack Pointer OUT: ~{CLK} -> ALU Modul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

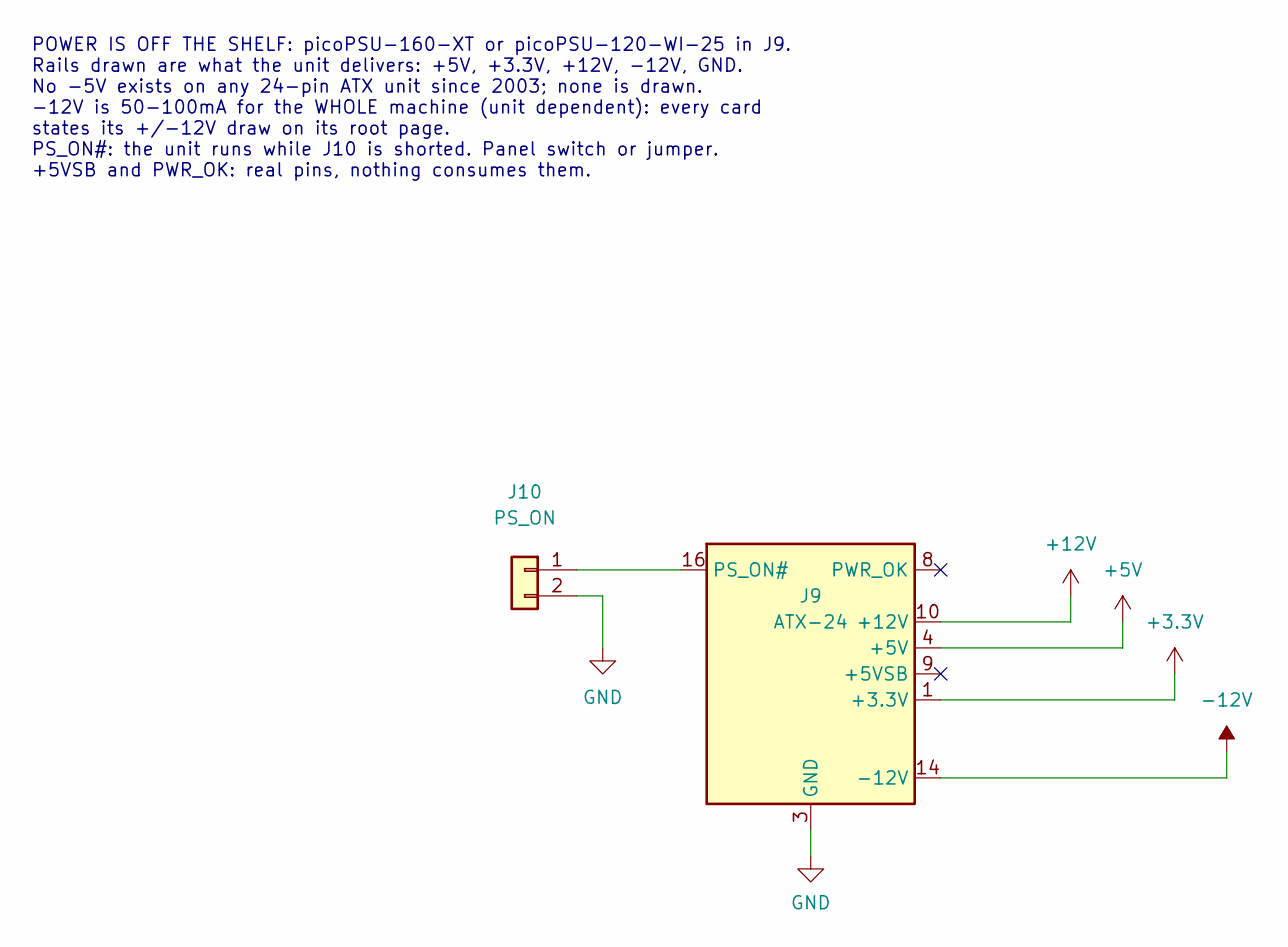
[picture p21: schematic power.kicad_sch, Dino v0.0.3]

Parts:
J9: ATX-24; Molex_Mini-Fit_Jr_5566-24A_2x12_P4.20mm_Vertical
J10: PS_ON; PinHeader_1x02_P2.54mm_Vertical

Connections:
+3.3V: J9.1 (+3.3V), J9.2 (+3.3V), J9.12 (+3.3V), J9.13 (+3.3V); also elsewhere on the board
+5V: J9.4 (+5V), J9.6 (+5V), J9.21 (+5V), J9.22 (+5V), J9.23 (+5V); also elsewhere on the board
+12V: J9.10 (+12V), J9.11 (+12V); also elsewhere on the board
-12V: J9.14 (-12V); also elsewhere on the board
GND: J9.3 (GND), J9.5 (GND), J9.7 (GND), J9.15 (GND), J9.17 (GND), J9.18 (GND), J9.19 (GND), J9.24 (GND), J10.2; also elsewhere on the board
unnamed: J9.16 (PS_ON#), J10.1

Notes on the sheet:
POWER IS OFF THE SHELF: picoPSU-160-XT or picoPSU-120-WI-25 in J9. Rails drawn are what the unit delivers: +5V, +3.3V, +12V, -12V, GND. No -5V exists on any 24-pin ATX unit since 2003; none is drawn. -12V is 50-100mA for the WHOLE machine (unit dependent): every card states its +/-12V draw on its r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

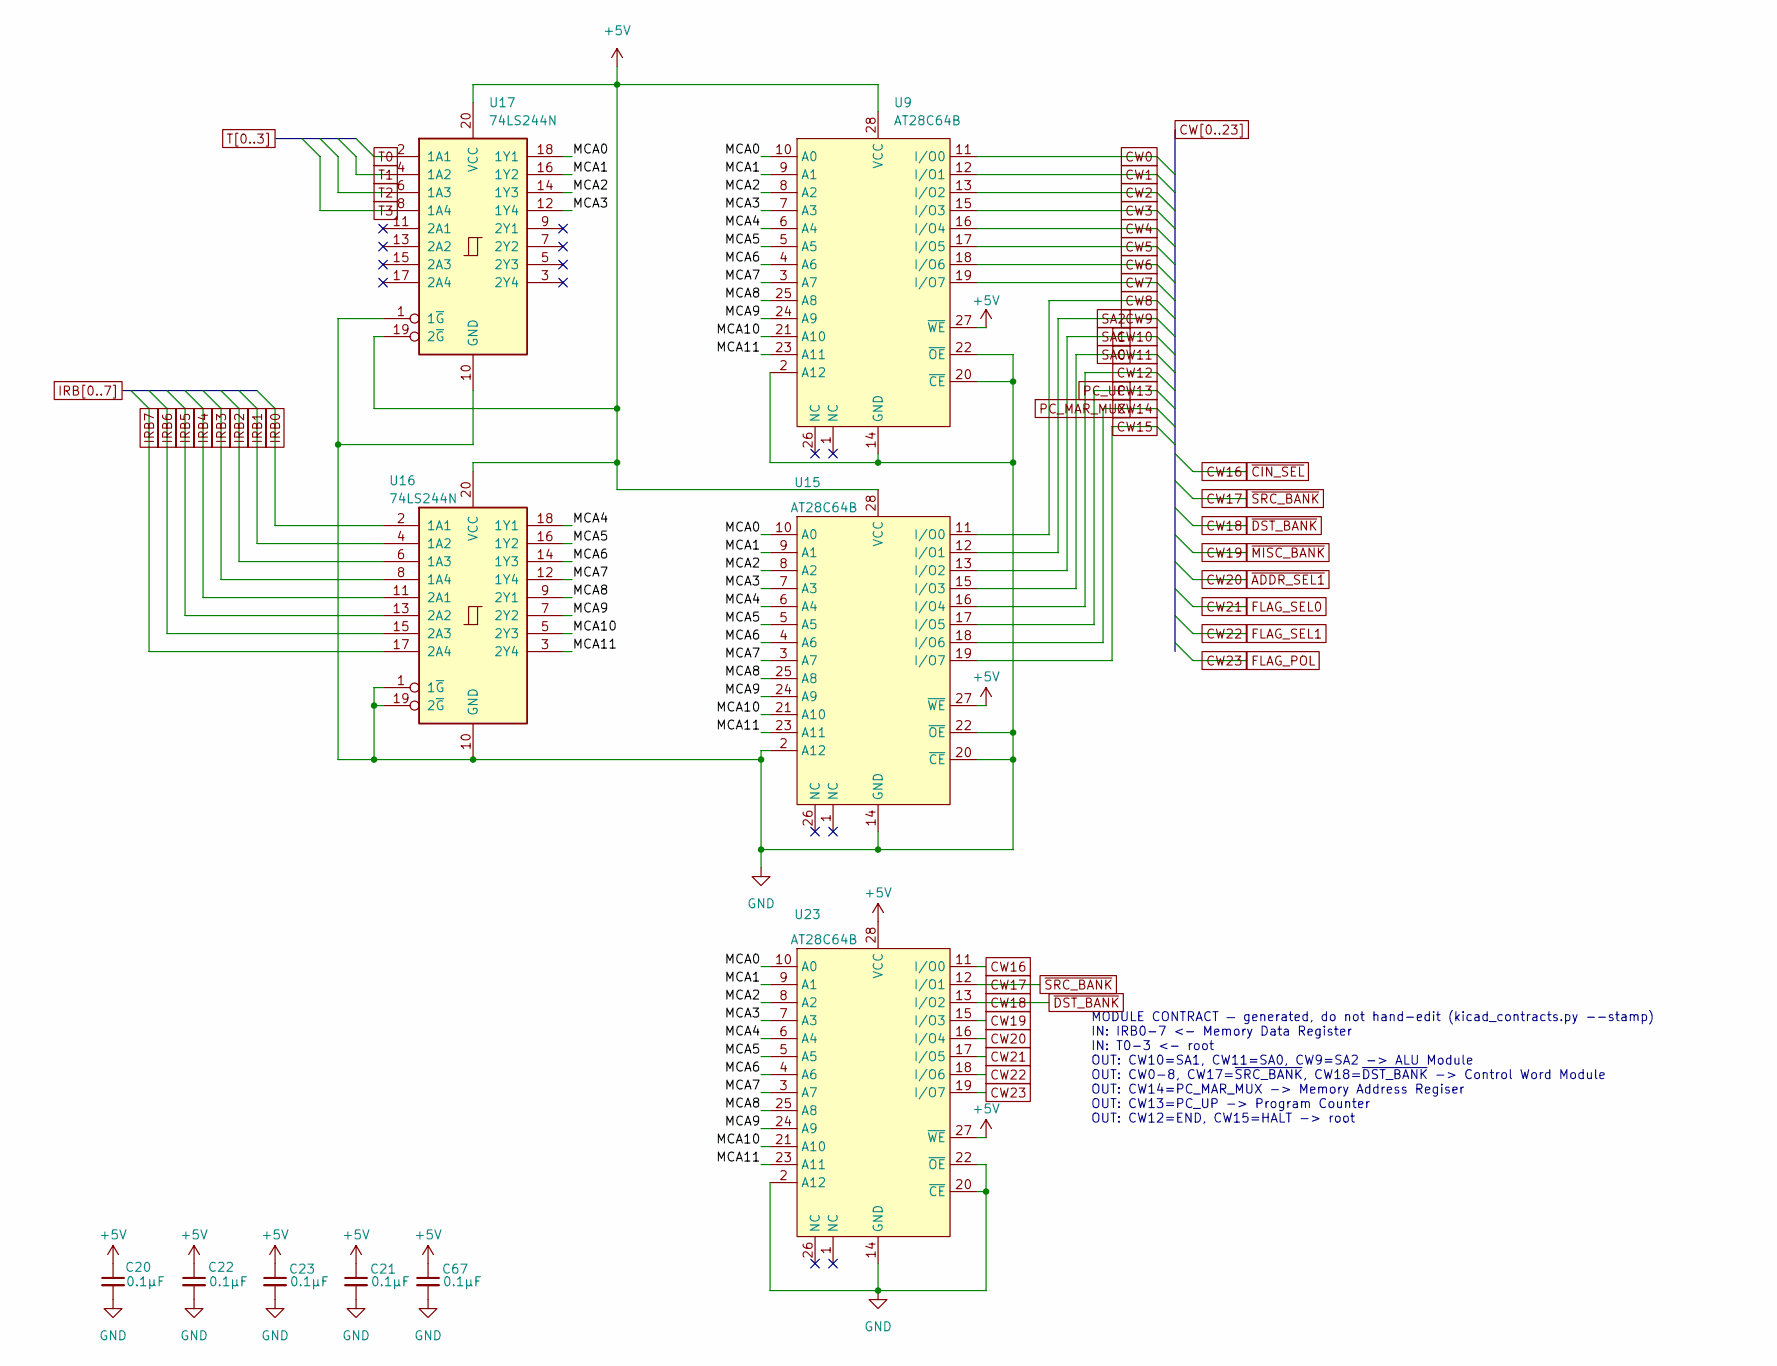
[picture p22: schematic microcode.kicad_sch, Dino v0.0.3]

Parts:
C20, C21, C22, C23, C67: 0.1µF; C_Disc_D5.0mm_W2.5mm_P2.50mm
U9, U15, U23: AT28C64B; DIP-28_W15.24mm
U16, U17: 74LS244N; DIP-20_W7.62mm

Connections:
+5V: C20.1, C21.1, C22.1, C23.1, C67.1, U9.27 (~WE), U9.28 (VCC), U15.27 (~WE), U15.28 (VCC), U16.20 (VCC), U17.19 (2~G), U17.20 (VCC), U23.27 (~WE), U23.28 (VCC); also elsewhere on the board
/Microcode_Decoder/MCA0: U9.10 (A0), U15.10 (A0), U17.18 (1Y1), U23.10 (A0)
/Microcode_Decoder/MCA1: U9.9 (A1), U15.9 (A1), U17.16 (1Y2), U23.9 (A1)
/Microcode_Decoder/MCA2: U9.8 (A2), U15.8 (A2), U17.14 (1Y3), U23.8 (A2)
/Microcode_Decoder/MCA3: U9.7 (A3), U15.7 (A3), U17.12 (1Y4), U23.7 (A3)
/Microcode_Decoder/MCA4: U9.6 (A4), U15.6 (A4), U16.18 (1Y1), U23.6 (A4)
/Microcode_Decoder/MCA5: U9.5 (A5), U15.5 (A5), U16.16 (1Y2), U23.5 (A5)
/Microcode_Decoder/MCA6: U9.4 (A6), U15.4 (A6), U16.14 (1Y3), U23.4 (A6)
/Microcode_Decoder/MCA7: U9.3 (A7), U15.3 (A7), U16.12 (1Y4), U23.3 (A7)
/Microcode_Decoder/MCA8: U9.25 (A8), U15.25 (A8), U16.9 (2Y1), U23.25 (A8)
/Microcode_Decoder/MCA9: U9.24 (A9), U15.24 (A9), U16.7 (2Y2), U23.24 (A9)
/Microcode_Decoder/MCA10: U9.21 (A10), U15.21 (A10), U16.5 (2Y3), U23.21 (A10)
/Microcode_Decoder/MCA11: U9.23 (A11), U15.23 (A11), U16.3 (2Y4), U23.23 (A11)
CW0: U9.11 (I/O0); also elsewhere on the board
CW1: U9.12 (I/O1); also elsewhere on the board
CW2: U9.13 (I/O2); also elsewhere on the board
CW3: U9.15 (I/O3); also elsewhere on the board
CW4: U9.16 (I/O4); also elsewhere on the board
CW5: U9.17 (I/O5); also elsewhere on the board
CW6: U9.18 (I/O6); also elsewhere on the board
CW7: U9.19 (I/O7); also elsewhere on the board
CW8: U15.11 (I/O0); also elsewhere on the board
CW9: U15.12 (I/O1); also elsewhere on the board
CW10: U15.13 (I/O2); also elsewhere on the board
CW11: U15.15 (I/O3); also elsewhere on the board
CW13: U15.17 (I/O5); also elsewhere on the board
CW14: U15.18 (I/O6); also elsewhere on the board
CW16: U23.11 (I/O0)
CW17: U23.12 (I/O1); also elsewhere on the board
CW18: U23.13 (I/O2); also elsewhere on the board
CW19: U23.15 (I/O3)
CW20: U23.16 (I/O4)
CW21: U23.17 (I/O5); also elsewhere on the board
CW22: U23.18 (I/O6)
CW23: U23.19 (I/O7)
GND: C20.2, C21.2, C22.2, C23.2, C67.2, U9.2 (A12), U9.14 (GND), U9.20 (~CE), U9.22 (~OE), U15.2 (A12), U15.14 (GND), U15.20 (~CE), U15.22 (~OE), U16.1 (1~G), U16.10 (GND), U16.19 (2~G), U17.1 (1~G), U17.10 (GND), U23.2 (A12), U23.14 (GND), U23.20 (~CE), U23.22 (~OE); also elsewhere on the board
IRB0: U16.2 (1A1); also elsewhere on the board
IRB1: U16.4 (1A2); also elsewhere on the board
IRB2: U16.6 (1A3); also elsewhere on the board
IRB3: U16.8 (1A4); also elsewhere on the board
IRB4: U16.11 (2A1); also elsewhere on the board
IRB5: U16.13 (2A2); also elsewhere on the board
IRB6: U16.15 (2A3); also elsewhere on the board
IRB7: U16.17 (2A4); also elsewhere on the board
T0: U17.2 (1A1); also elsewhere on the board
T1: U17.4 (1A2); also elsewhere on the board
T2: U17.6 (1A3); also elsewhere on the board
T3: U17.8 (1A4); also elsewhere on the board

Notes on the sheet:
MODULE CONTRACT — generated, do not hand-edit (kicad_contracts.py --stamp) IN: IRB0-7 <- Memory Data Register IN: T0-3 <- root OUT: CW10=SA1, CW11=SA0, CW9=SA2 -> ALU Module OUT: CW0-8, CW17=~{SRC_BANK}, CW18=~{DST_BANK} -> Control Word Module OUT: CW14=PC_MAR_MUX -> Memory Address Regiser OUT: CW1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

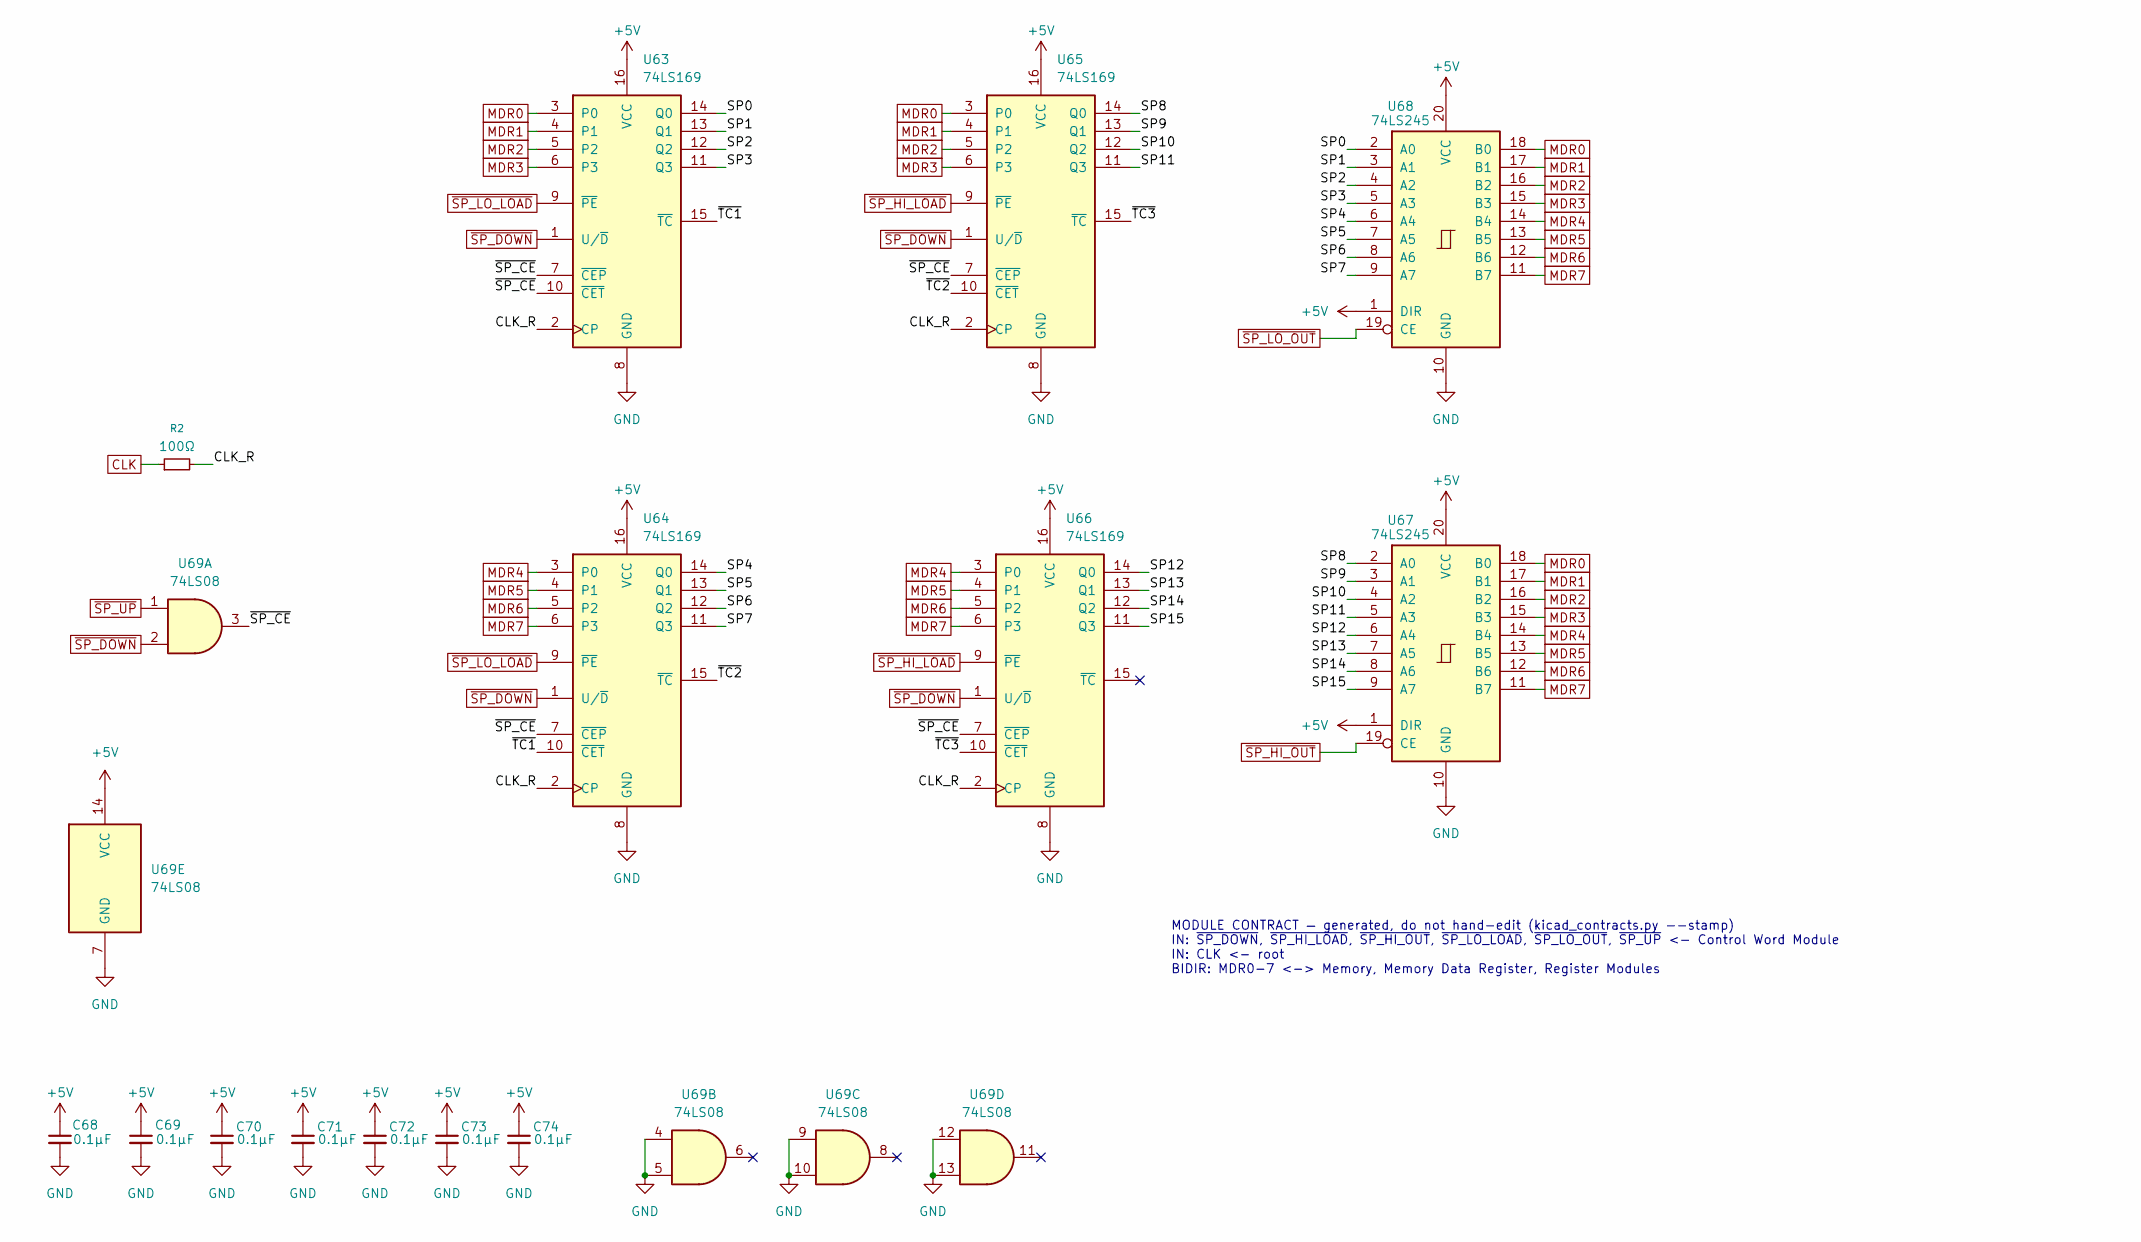
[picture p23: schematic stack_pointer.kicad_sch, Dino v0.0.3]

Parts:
C68, C69, C70, C71, C72, C73, C74: 0.1µF; C_Disc_D5.0mm_W2.5mm_P2.50mm
R2: 100Ω; R_Axial_DIN0207_L6.3mm_D2.5mm_P10.16mm_Horizontal
U63, U64, U65, U66: 74LS169; DIP-16_W7.62mm
U67, U68: 74LS245; DIP-20_W7.62mm
U69: 74LS08; DIP-14_W7.62mm

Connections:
+5V: C68.1, C69.1, C70.1, C71.1, C72.1, C73.1, C74.1, U63.16 (VCC), U64.16 (VCC), U65.16 (VCC), U66.16 (VCC), U67.1 (DIR), U67.20 (VCC), U68.1 (DIR), U68.20 (VCC), U69.14 (VCC); also elsewhere on the board
/Stack Pointer/CLK_R: R2.2, U63.2 (CP), U64.2 (CP), U65.2 (CP), U66.2 (CP)
/Stack Pointer/SP0: U63.14 (Q0), U68.2 (A0)
/Stack Pointer/SP1: U63.13 (Q1), U68.3 (A1)
/Stack Pointer/SP2: U63.12 (Q2), U68.4 (A2)
/Stack Pointer/SP3: U63.11 (Q3), U68.5 (A3)
/Stack Pointer/SP4: U64.14 (Q0), U68.6 (A4)
/Stack Pointer/SP5: U64.13 (Q1), U68.7 (A5)
/Stack Pointer/SP6: U64.12 (Q2), U68.8 (A6)
/Stack Pointer/SP7: U64.11 (Q3), U68.9 (A7)
/Stack Pointer/SP8: U65.14 (Q0), U67.2 (A0)
/Stack Pointer/SP9: U65.13 (Q1), U67.3 (A1)
/Stack Pointer/SP10: U65.12 (Q2), U67.4 (A2)
/Stack Pointer/SP11: U65.11 (Q3), U67.5 (A3)
/Stack Pointer/SP12: U66.14 (Q0), U67.6 (A4)
/Stack Pointer/SP13: U66.13 (Q1), U67.7 (A5)
/Stack Pointer/SP14: U66.12 (Q2), U67.8 (A6)
/Stack Pointer/SP15: U66.11 (Q3), U67.9 (A7)
/Stack Pointer/~SP_CE: U63.7 (~CEP), U63.10 (~CET), U64.7 (~CEP), U65.7 (~CEP), U66.7 (~CEP), U69.3
/Stack Pointer/~TC1: U63.15 (~TC), U64.10 (~CET)
/Stack Pointer/~TC2: U64.15 (~TC), U65.10 (~CET)
/Stack Pointer/~TC3: U65.15 (~TC), U66.10 (~CET)
CLK: R2.1; also elsewhere on the board
GND: C68.2, C69.2, C70.2, C71.2, C72.2, C73.2, C74.2, U63.8 (GND), U64.8 (GND), U65.8 (GND), U66.8 (GND), U67.10 (GND), U68.10 (GND), U69.4, U69.5, U69.7 (GND), U69.9, U69.10, U69.12, U69.13; also elsewhere on the board
MDR0: U63.3 (P0), U65.3 (P0), U67.18 (B0), U68.18 (B0); also elsewhere on the board
MDR1: U63.4 (P1), U65.4 (P1), U67.17 (B1), U68.17 (B1); also elsewhere on the board
MDR2: U63.5 (P2), U65.5 (P2), U67.16 (B2), U68.16 (B2); also elsewhere on the board
MDR3: U63.6 (P3), U65.6 (P3), U67.15 (B3), U68.15 (B3); also elsewhere on the board
MDR4: U64.3 (P0), U66.3 (P0), U67.14 (B4), U68.14 (B4); also elsewhere on the board
MDR5: U64.4 (P1), U66.4 (P1), U67.13 (B5), U68.13 (B5); also elsewhere on the board
MDR6: U64.5 (P2), U66.5 (P2), U67.12 (B6), U68.12 (B6); also elsewhere on the board
MDR7: U64.6 (P3), U66.6 (P3), U67.11 (B7), U68.11 (B7); also elsewhere on the board
~SP_DOWN: U63.1 (U/~D), U64.1 (U/~D), U65.1 (U/~D), U66.1 (U/~D), U69.2; also elsewhere on the board
~SP_HI_LOAD: U65.9 (~PE), U66.9 (~PE); also elsewhere on the board
~SP_HI_OUT: U67.19 (CE); also elsewhere on the board
~SP_LO_LOAD: U63.9 (~PE), U64.9 (~PE); also elsewhere on the board
~SP_LO_OUT: U68.19 (CE); also elsewhere on the board
~SP_UP: U69.1; also elsewhere on the board

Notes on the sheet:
MODULE CONTRACT — generated, do not hand-edit (kicad_contracts.py --stamp) IN: ~{SP_DOWN}, ~{SP_HI_LOAD}, ~{SP_HI_OUT}, ~{SP_LO_LOAD}, ~{SP_LO_OUT}, ~{SP_UP} <- Control Word Module IN: CLK <- root BIDIR: MDR0-7 <-> Memory, Memory Data Register, Register Modules

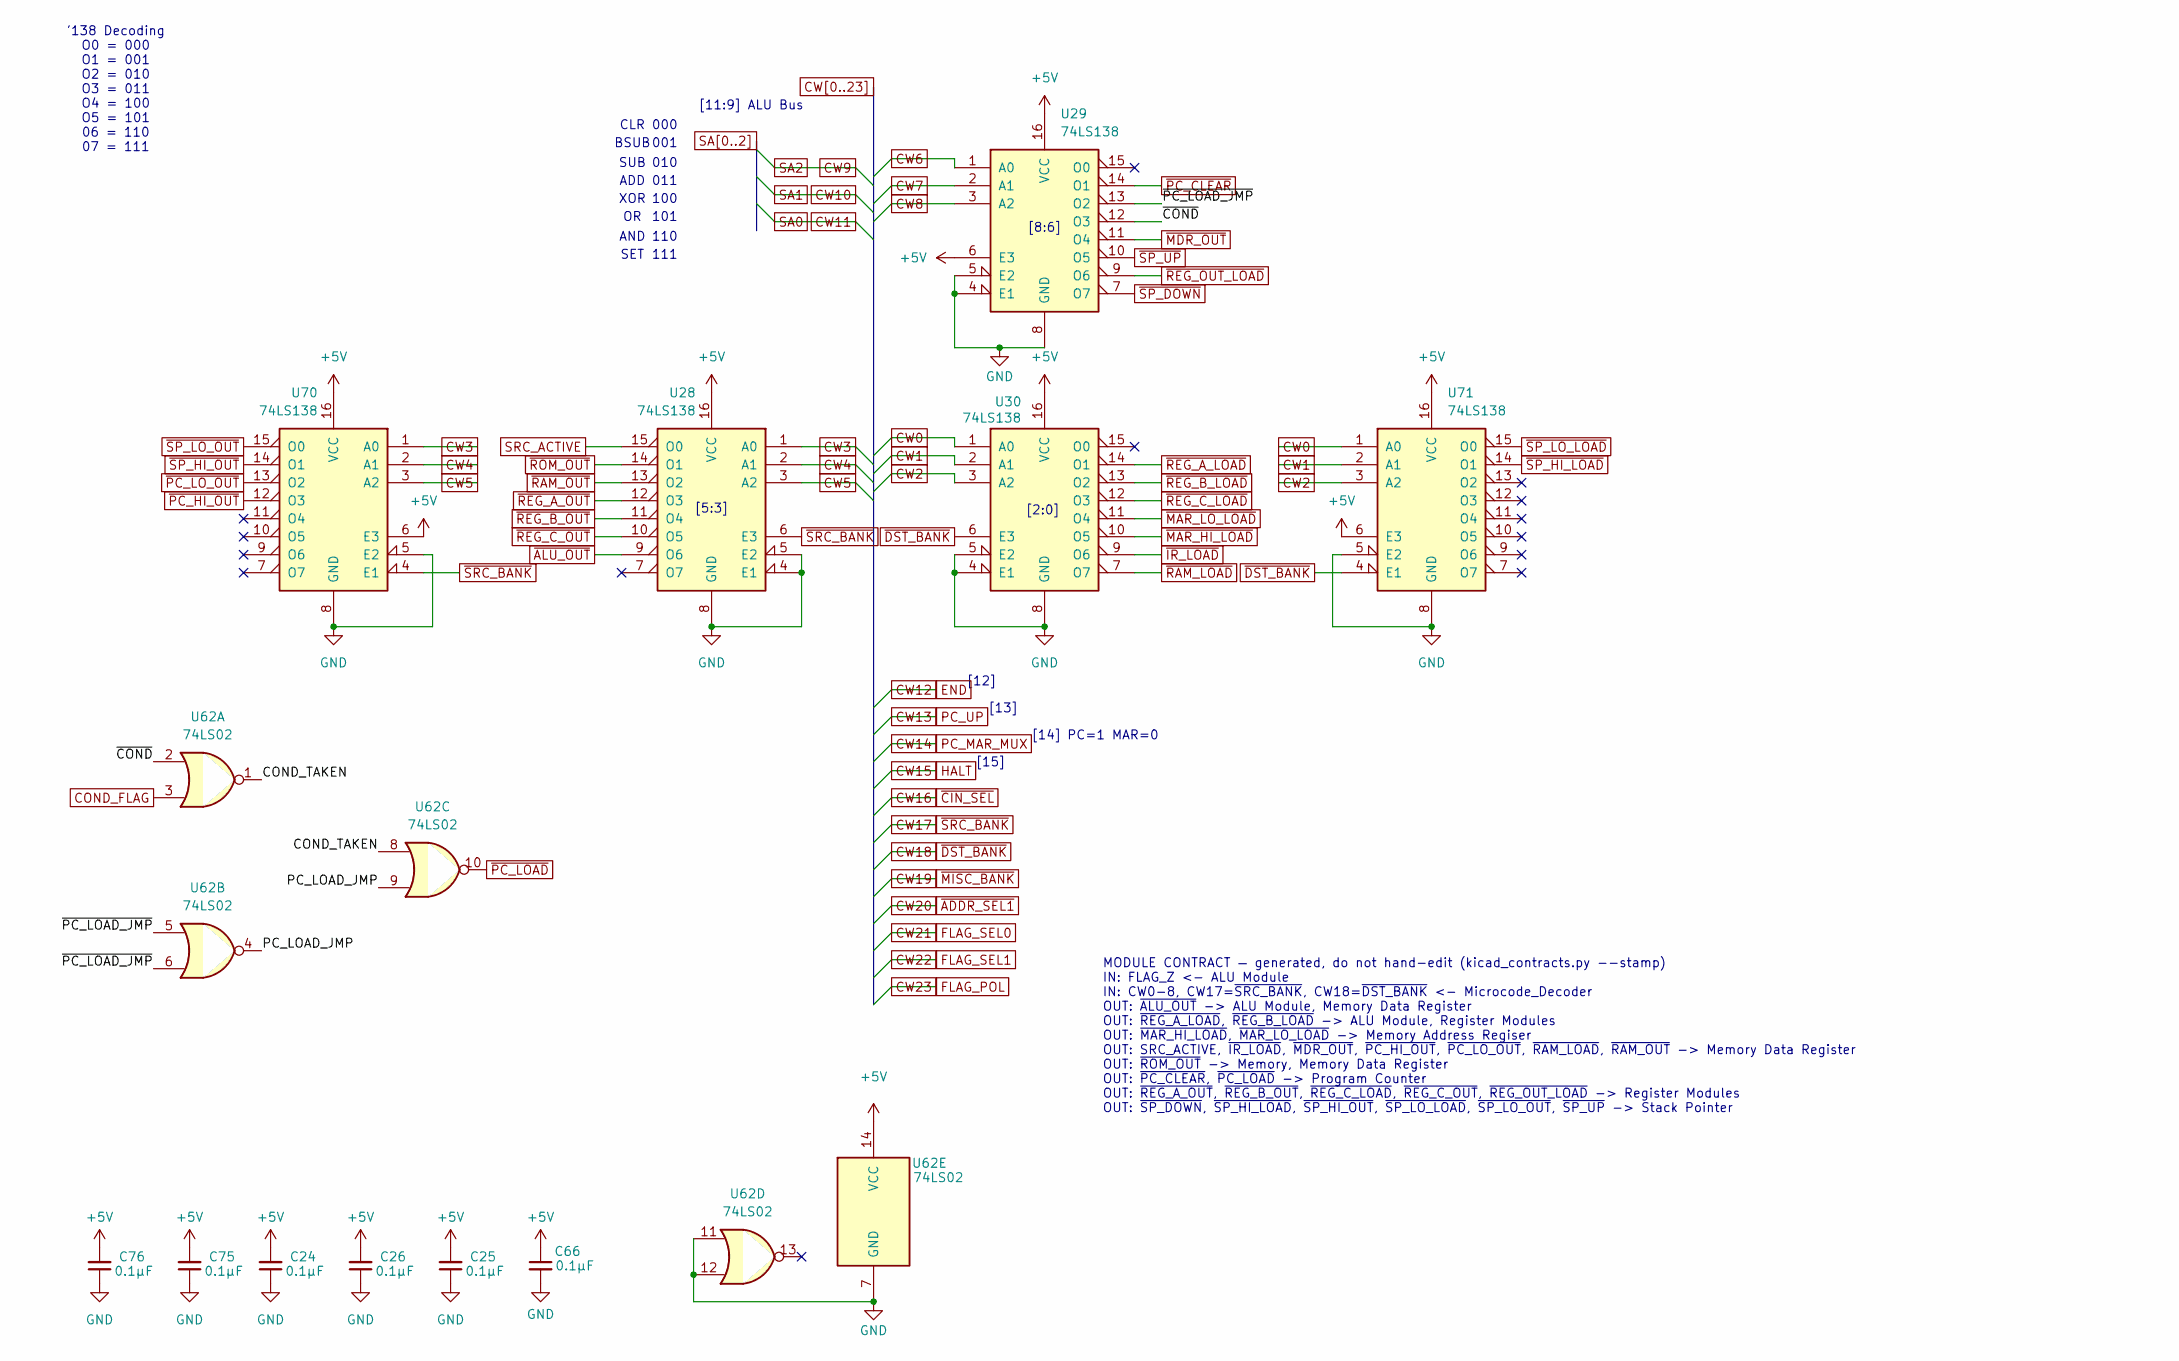
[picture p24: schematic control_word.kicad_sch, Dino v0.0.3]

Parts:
C24, C25, C26, C66, C75, C76: 0.1µF; C_Disc_D5.0mm_W2.5mm_P2.50mm
U28, U29, U30, U70, U71: 74LS138; DIP-16_W7.62mm
U62: 74LS02; DIP-14_W7.62mm

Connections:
+5V: C24.2, C25.2, C26.2, C66.1, C75.2, C76.2, U28.16 (VCC), U29.6 (E3), U29.16 (VCC), U30.16 (VCC), U62.14 (VCC), U70.6 (E3), U70.16 (VCC), U71.6 (E3), U71.16 (VCC); also elsewhere on the board
/Control Word Module/COND_TAKEN: U62.1, U62.8
/Control Word Module/PC_LOAD_JMP: U62.4, U62.9
/Control Word Module/~COND: U29.12 (O3), U62.2
/Control Word Module/~PC_LOAD_JMP: U29.13 (O2), U62.5, U62.6
COND_FLAG: U62.3; also elsewhere on the board
CW0: U30.1 (A0), U71.1 (A0); also elsewhere on the board
CW1: U30.2 (A1), U71.2 (A1); also elsewhere on the board
CW2: U30.3 (A2), U71.3 (A2); also elsewhere on the board
CW3: U28.1 (A0), U70.1 (A0); also elsewhere on the board
CW4: U28.2 (A1), U70.2 (A1); also elsewhere on the board
CW5: U28.3 (A2), U70.3 (A2); also elsewhere on the board
CW6: U29.1 (A0); also elsewhere on the board
CW7: U29.2 (A1); also elsewhere on the board
CW8: U29.3 (A2); also elsewhere on the board
CW17: U28.6 (E3), U70.4 (E1); also elsewhere on the board
CW18: U30.6 (E3), U71.4 (E1); also elsewhere on the board
GND: C24.1, C25.1, C26.1, C66.2, C75.1, C76.1, U28.4 (E1), U28.5 (E2), U28.8 (GND), U29.4 (E1), U29.5 (E2), U29.8 (GND), U30.4 (E1), U30.5 (E2), U30.8 (GND), U62.7 (GND), U62.11, U62.12, U70.5 (E2), U70.8 (GND), U71.5 (E2), U71.8 (GND); also elsewhere on the board
SRC_ACTIVE: U28.15 (O0); also elsewhere on the board
~ALU_OUT: U28.9 (O6); also elsewhere on the board
~IR_LOAD: U30.9 (O6); also elsewhere on the board
~MAR_HI_LOAD: U30.10 (O5); also elsewhere on the board
~MAR_LO_LOAD: U30.11 (O4); also elsewhere on the board
~MDR_OUT: U29.11 (O4); also elsewhere on the board
~PC_CLEAR: U29.14 (O1); also elsewhere on the board
~PC_HI_OUT: U70.12 (O3); also elsewhere on the board
~PC_LOAD: U62.10; also elsewhere on the board
~PC_LO_OUT: U70.13 (O2); also elsewhere on the board
~RAM_LOAD: U30.7 (O7); also elsewhere on the board
~RAM_OUT: U28.13 (O2); also elsewhere on the board
~REG_A_LOAD: U30.14 (O1); also elsewhere on the board
~REG_A_OUT: U28.12 (O3); also elsewhere on the board
~REG_B_LOAD: U30.13 (O2); also elsewhere on the board
~REG_B_OUT: U28.11 (O4); also elsewhere on the board
~REG_C_LOAD: U30.12 (O3); also elsewhere on the board
~REG_C_OUT: U28.10 (O5); also elsewhere on the board
~REG_OUT_LOAD: U29.9 (O6); also elsewhere on the board
~ROM_OUT: U28.14 (O1); also elsewhere on the board
~SP_DOWN: U29.7 (O7); also elsewhere on the board
~SP_HI_LOAD: U71.14 (O1); also elsewhere on the board
~SP_HI_OUT: U70.14 (O1); also elsewhere on the board
~SP_LO_LOAD: U71.15 (O0); also elsewhere on the board
~SP_LO_OUT: U70.15 (O0); also elsewhere on the board
~SP_UP: U29.10 (O5); also elsewhere on the board

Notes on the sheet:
SET
PC=1 MAR=0
[15]
100
[13]
'138 Decoding O0 = 000 O1 = 001 O2 = 010 O3 = 011 O4 = 100 O5 = 101 06 = 110 07 = 111
101
[14]
SUB
[8:6]
110
[2:0]
001
BSUB
[12]
MODULE CONTRACT — generated, do not hand-edit (kicad_contracts.py --stamp) IN: FLAG_Z <- ALU Module IN: CW0-8, CW17=~{SRC_BANK}, CW18=~{DST_BANK} <- Microcode_Decoder OUT: ~{ALU_OUT} -> ALU Module, Memory Data Register OUT: ~{REG_A_LOAD}, ~{REG_B_LOAD} -> ALU Module, Register Modules OUT: ~{MAR_HI_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
011
000
AND
CLR
010
111
XOR
[11:9] ALU Bus
ADD
[5:3]

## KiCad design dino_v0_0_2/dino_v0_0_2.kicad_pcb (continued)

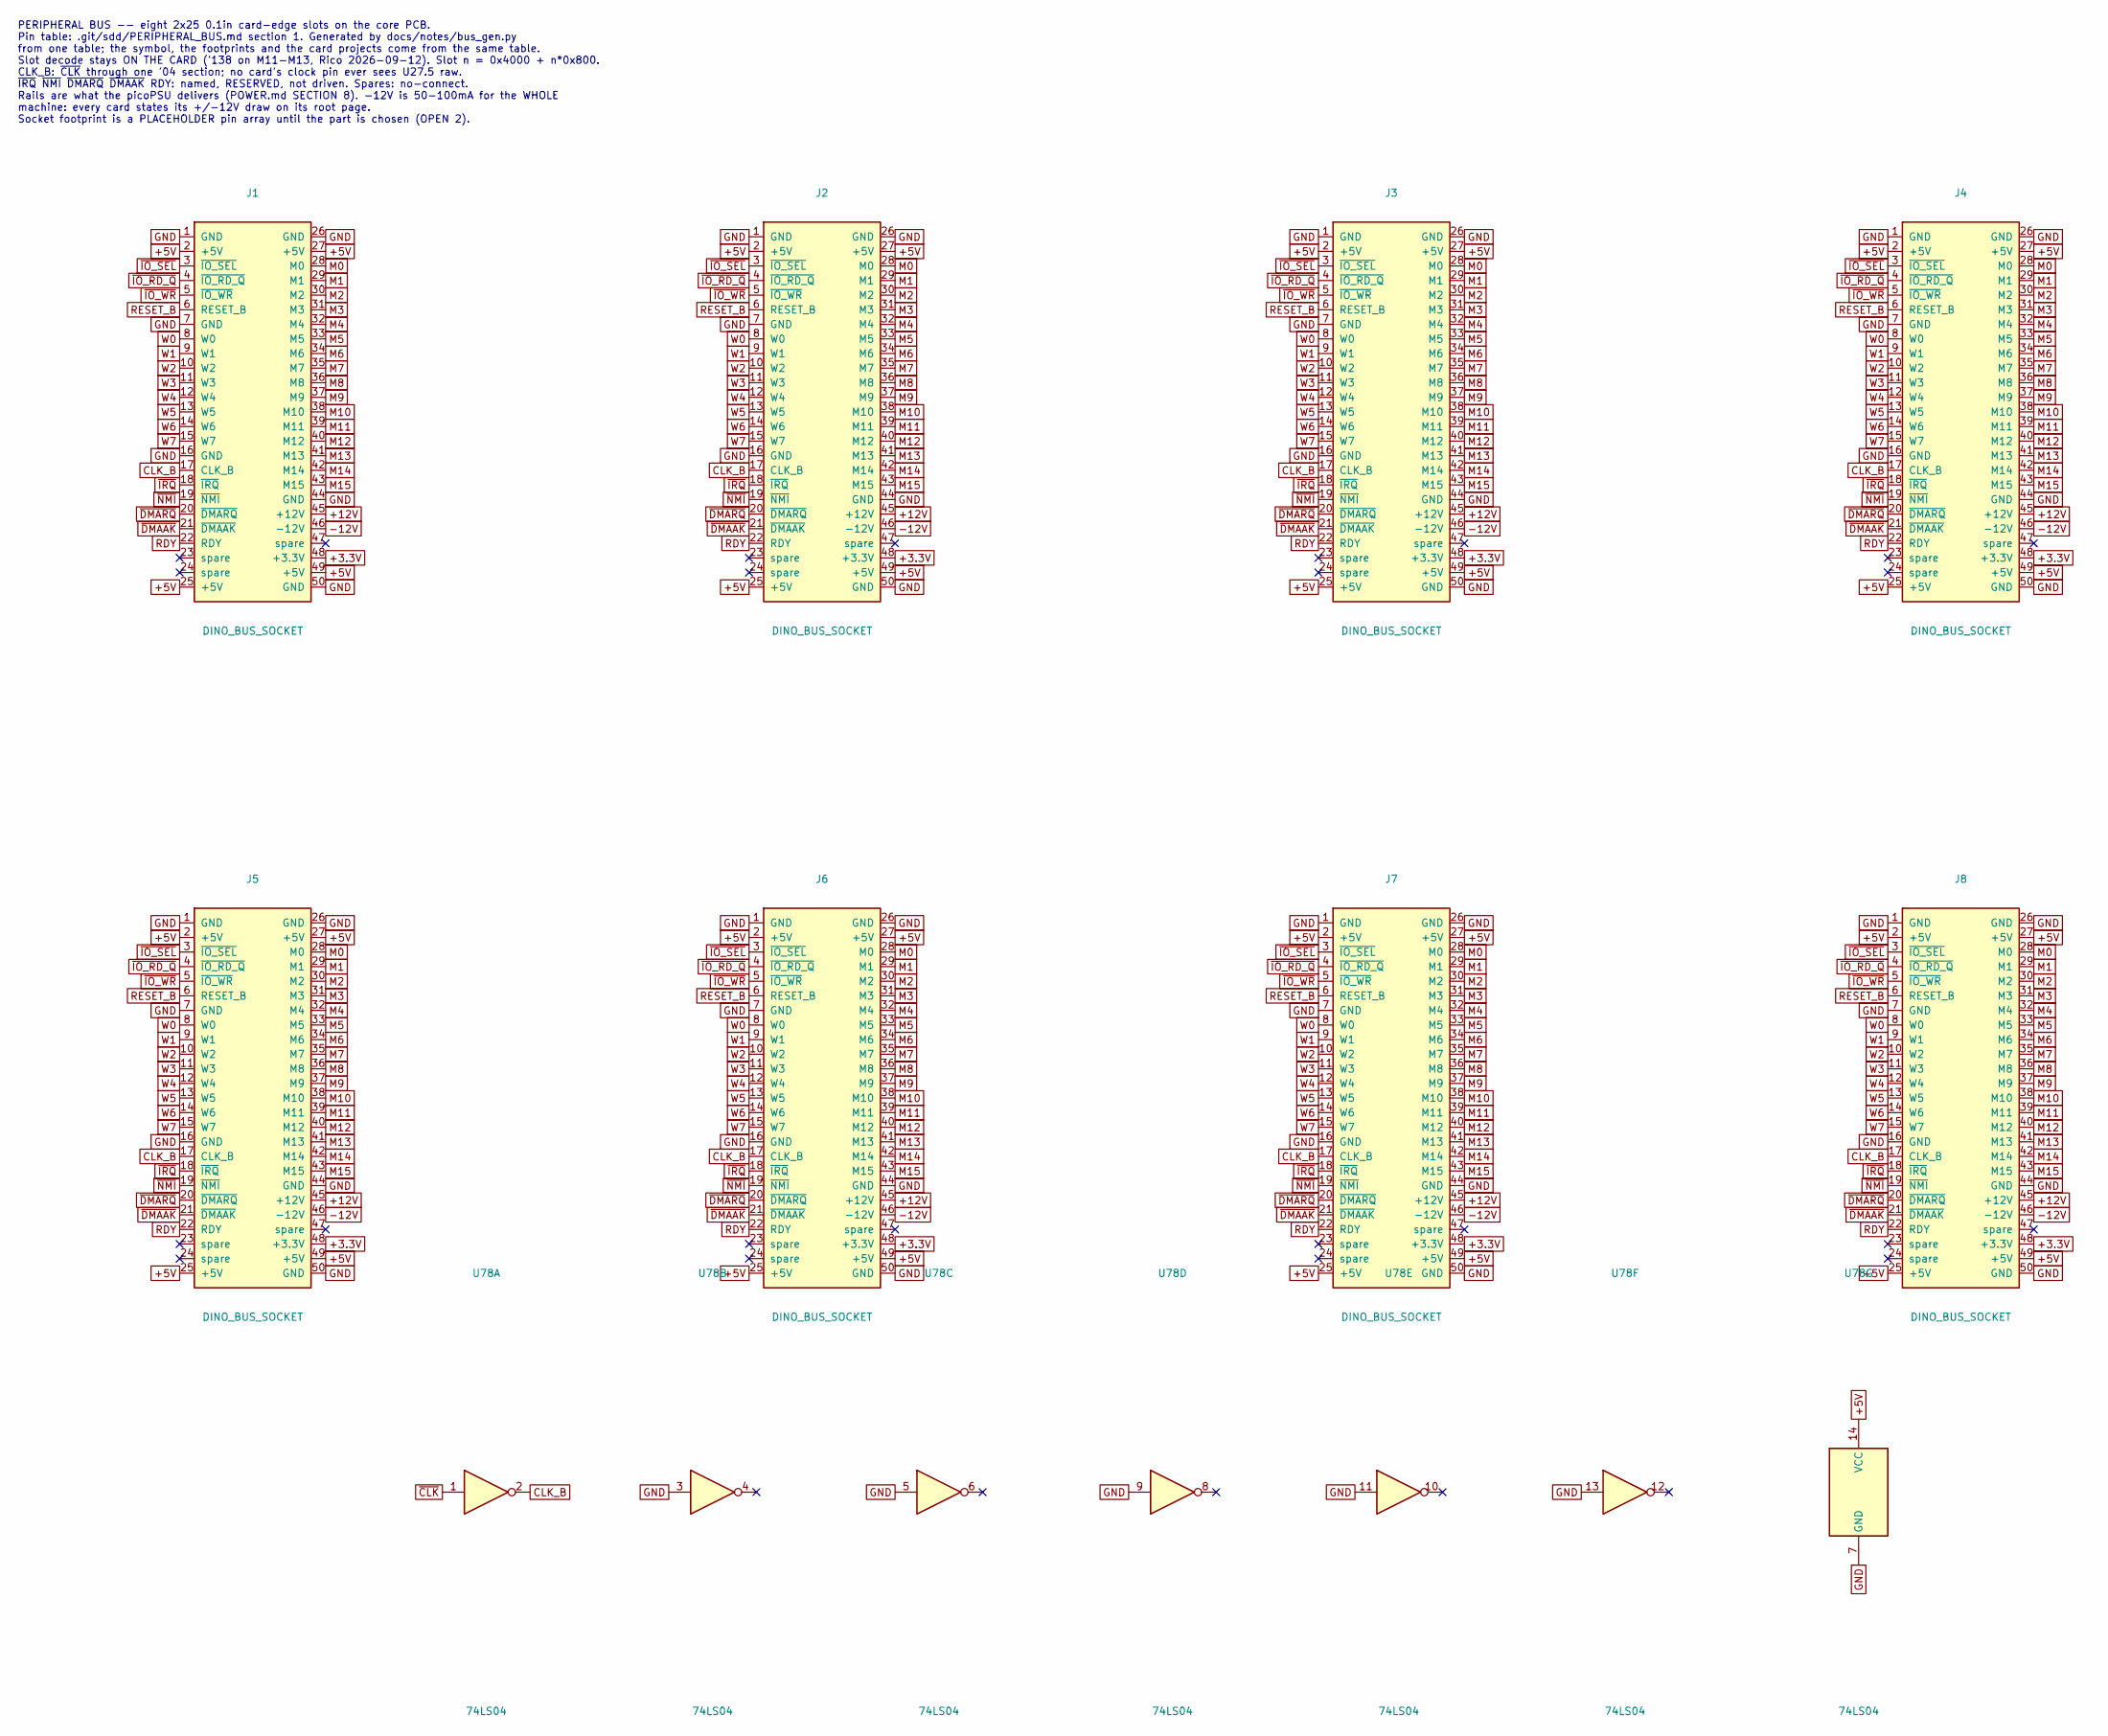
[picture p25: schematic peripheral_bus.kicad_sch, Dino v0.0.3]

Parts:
J1, J2, J3, J4, J5, J6, J7, J8: DINO_BUS_SOCKET; EdgeSocket_2x25_P2.54mm_THT
U78: 74LS04; DIP-14_W7.62mm

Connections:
+3.3V: J1.48 (+3.3V), J2.48 (+3.3V), J3.48 (+3.3V), J4.48 (+3.3V), J5.48 (+3.3V), J6.48 (+3.3V), J7.48 (+3.3V), J8.48 (+3.3V); also elsewhere on the board
+5V: J1.2 (+5V), J1.25 (+5V), J1.27 (+5V), J1.49 (+5V), J2.2 (+5V), J2.25 (+5V), J2.27 (+5V), J2.49 (+5V), J3.2 (+5V), J3.25 (+5V), J3.27 (+5V), J3.49 (+5V), J4.2 (+5V), J4.25 (+5V), J4.27 (+5V), J4.49 (+5V), J5.2 (+5V), J5.25 (+5V), J5.27 (+5V), J5.49 (+5V), J6.2 (+5V), J6.25 (+5V), J6.27 (+5V), J6.49 (+5V), J7.2 (+5V), J7.25 (+5V), J7.27 (+5V), J7.49 (+5V), J8.2 (+5V), J8.25 (+5V), J8.27 (+5V), J8.49 (+5V), U78.14 (VCC); also elsewhere on the board
+12V: J1.45 (+12V), J2.45 (+12V), J3.45 (+12V), J4.45 (+12V), J5.45 (+12V), J6.45 (+12V), J7.45 (+12V), J8.45 (+12V); also elsewhere on the board
-12V: J1.46 (-12V), J2.46 (-12V), J3.46 (-12V), J4.46 (-12V), J5.46 (-12V), J6.46 (-12V), J7.46 (-12V), J8.46 (-12V); also elsewhere on the board
CLK_B: J1.17 (CLK_B), J2.17 (CLK_B), J3.17 (CLK_B), J4.17 (CLK_B), J5.17 (CLK_B), J6.17 (CLK_B), J7.17 (CLK_B), J8.17 (CLK_B), U78.2
GND: J1.1 (GND), J1.7 (GND), J1.16 (GND), J1.26 (GND), J1.44 (GND), J1.50 (GND), J2.1 (GND), J2.7 (GND), J2.16 (GND), J2.26 (GND), J2.44 (GND), J2.50 (GND), J3.1 (GND), J3.7 (GND), J3.16 (GND), J3.26 (GND), J3.44 (GND), J3.50 (GND), J4.1 (GND), J4.7 (GND), J4.16 (GND), J4.26 (GND), J4.44 (GND), J4.50 (GND), J5.1 (GND), J5.7 (GND), J5.16 (GND), J5.26 (GND), J5.44 (GND), J5.50 (GND), J6.1 (GND), J6.7 (GND), J6.16 (GND), J6.26 (GND), J6.44 (GND), J6.50 (GND), J7.1 (GND), J7.7 (GND), J7.16 (GND), J7.26 (GND), J7.44 (GND), J7.50 (GND), J8.1 (GND), J8.7 (GND), J8.16 (GND), J8.26 (GND), J8.44 (GND), J8.50 (GND), U78.3, U78.5, U78.7 (GND), U78.9, U78.11, U78.13; also elsewhere on the board
M0: J1.28 (M0), J2.28 (M0), J3.28 (M0), J4.28 (M0), J5.28 (M0), J6.28 (M0), J7.28 (M0), J8.28 (M0); also elsewhere on the board
M1: J1.29 (M1), J2.29 (M1), J3.29 (M1), J4.29 (M1), J5.29 (M1), J6.29 (M1), J7.29 (M1), J8.29 (M1); also elsewhere on the board
M2: J1.30 (M2), J2.30 (M2), J3.30 (M2), J4.30 (M2), J5.30 (M2), J6.30 (M2), J7.30 (M2), J8.30 (M2); also elsewhere on the board
M3: J1.31 (M3), J2.31 (M3), J3.31 (M3), J4.31 (M3), J5.31 (M3), J6.31 (M3), J7.31 (M3), J8.31 (M3); also elsewhere on the board
M4: J1.32 (M4), J2.32 (M4), J3.32 (M4), J4.32 (M4), J5.32 (M4), J6.32 (M4), J7.32 (M4), J8.32 (M4); also elsewhere on the board
M5: J1.33 (M5), J2.33 (M5), J3.33 (M5), J4.33 (M5), J5.33 (M5), J6.33 (M5), J7.33 (M5), J8.33 (M5); also elsewhere on the board
M6: J1.34 (M6), J2.34 (M6), J3.34 (M6), J4.34 (M6), J5.34 (M6), J6.34 (M6), J7.34 (M6), J8.34 (M6); also elsewhere on the board
M7: J1.35 (M7), J2.35 (M7), J3.35 (M7), J4.35 (M7), J5.35 (M7), J6.35 (M7), J7.35 (M7), J8.35 (M7); also elsewhere on the board
M8: J1.36 (M8), J2.36 (M8), J3.36 (M8), J4.36 (M8), J5.36 (M8), J6.36 (M8), J7.36 (M8), J8.36 (M8); also elsewhere on the board
M9: J1.37 (M9), J2.37 (M9), J3.37 (M9), J4.37 (M9), J5.37 (M9), J6.37 (M9), J7.37 (M9), J8.37 (M9); also elsewhere on the board
M10: J1.38 (M10), J2.38 (M10), J3.38 (M10), J4.38 (M10), J5.38 (M10), J6.38 (M10), J7.38 (M10), J8.38 (M10); also elsewhere on the board
M11: J1.39 (M11), J2.39 (M11), J3.39 (M11), J4.39 (M11), J5.39 (M11), J6.39 (M11), J7.39 (M11), J8.39 (M11); also elsewhere on the board
M12: J1.40 (M12), J2.40 (M12), J3.40 (M12), J4.40 (M12), J5.40 (M12), J6.40 (M12), J7.40 (M12), J8.40 (M12); also elsewhere on the board
M13: J1.41 (M13), J2.41 (M13), J3.41 (M13), J4.41 (M13), J5.41 (M13), J6.41 (M13), J7.41 (M13), J8.41 (M13); also elsewhere on the board
M14: J1.42 (M14), J2.42 (M14), J3.42 (M14), J4.42 (M14), J5.42 (M14), J6.42 (M14), J7.42 (M14), J8.42 (M14); also elsewhere on the board
M15: J1.43 (M15), J2.43 (M15), J3.43 (M15), J4.43 (M15), J5.43 (M15), J6.43 (M15), J7.43 (M15), J8.43 (M15); also elsewhere on the board
RDY: J1.22 (RDY), J2.22 (RDY), J3.22 (RDY), J4.22 (RDY), J5.22 (RDY), J6.22 (RDY), J7.22 (RDY), J8.22 (RDY)
RESET_B: J1.6 (RESET_B), J2.6 (RESET_B), J3.6 (RESET_B), J4.6 (RESET_B), J5.6 (RESET_B), J6.6 (RESET_B), J7.6 (RESET_B), J8.6 (RESET_B); also elsewhere on the board
W0: J1.8 (W0), J2.8 (W0), J3.8 (W0), J4.8 (W0), J5.8 (W0), J6.8 (W0), J7.8 (W0), J8.8 (W0); also elsewhere on the board
W1: J1.9 (W1), J2.9 (W1), J3.9 (W1), J4.9 (W1), J5.9 (W1), J6.9 (W1), J7.9 (W1), J8.9 (W1); also elsewhere on the board
W2: J1.10 (W2), J2.10 (W2), J3.10 (W2), J4.10 (W2), J5.10 (W2), J6.10 (W2), J7.10 (W2), J8.10 (W2); also elsewhere on the board
W3: J1.11 (W3), J2.11 (W3), J3.11 (W3), J4.11 (W3), J5.11 (W3), J6.11 (W3), J7.11 (W3), J8.11 (W3); also elsewhere on the board
W4: J1.12 (W4), J2.12 (W4), J3.12 (W4), J4.12 (W4), J5.12 (W4), J6.12 (W4), J7.12 (W4), J8.12 (W4); also elsewhere on the board
W5: J1.13 (W5), J2.13 (W5), J3.13 (W5), J4.13 (W5), J5.13 (W5), J6.13 (W5), J7.13 (W5), J8.13 (W5); also elsewhere on the board
W6: J1.14 (W6), J2.14 (W6), J3.14 (W6), J4.14 (W6), J5.14 (W6), J6.14 (W6), J7.14 (W6), J8.14 (W6); also elsewhere on the board
W7: J1.15 (W7), J2.15 (W7), J3.15 (W7), J4.15 (W7), J5.15 (W7), J6.15 (W7), J7.15 (W7), J8.15 (W7); also elsewhere on the board
~CLK: U78.1; also elsewhere on the board
~DMAAK: J1.21 (~DMAAK), J2.21 (~DMAAK), J3.21 (~DMAAK), J4.21 (~DMAAK), J5.21 (~DMAAK), J6.21 (~DMAAK), J7.21 (~DMAAK), J8.21 (~DMAAK)
~DMARQ: J1.20 (~DMARQ), J2.20 (~DMARQ), J3.20 (~DMARQ), J4.20 (~DMARQ), J5.20 (~DMARQ), J6.20 (~DMARQ), J7.20 (~DMARQ), J8.20 (~DMARQ)
~IO_RD_Q: J1.4 (~IO_RD_Q), J2.4 (~IO_RD_Q), J3.4 (~IO_RD_Q), J4.4 (~IO_RD_Q), J5.4 (~IO_RD_Q), J6.4 (~IO_RD_Q), J7.4 (~IO_RD_Q), J8.4 (~IO_RD_Q); also elsewhere on the board
~IO_SEL: J1.3 (~IO_SEL), J2.3 (~IO_SEL), J3.3 (~IO_SEL), J4.3 (~IO_SEL), J5.3 (~IO_SEL), J6.3 (~IO_SEL), J7.3 (~IO_SEL), J8.3 (~IO_SEL); also elsewhere on the board
~IO_WR: J1.5 (~IO_WR), J2.5 (~IO_WR), J3.5 (~IO_WR), J4.5 (~IO_WR), J5.5 (~IO_WR), J6.5 (~IO_WR), J7.5 (~IO_WR), J8.5 (~IO_WR); also elsewhere on the board
~IRQ: J1.18 (~IRQ), J2.18 (~IRQ), J3.18 (~IRQ), J4.18 (~IRQ), J5.18 (~IRQ), J6.18 (~IRQ), J7.18 (~IRQ), J8.18 (~IRQ)
~NMI: J1.19 (~NMI), J2.19 (~NMI), J3.19 (~NMI), J4.19 (~NMI), J5.19 (~NMI), J6.19 (~NMI), J7.19 (~NMI), J8.19 (~NMI)

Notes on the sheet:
PERIPHERAL BUS -- eight 2x25 0.1in card-edge slots on the core PCB. Pin table: .git/sdd/PERIPHERAL_BUS.md section 1. Generated by docs/notes/bus_gen.py from one table; the symbol, the footprints and the card projects come from the same table. Slot decode stays ON THE CARD ('138 on M11-M13, Rico 202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

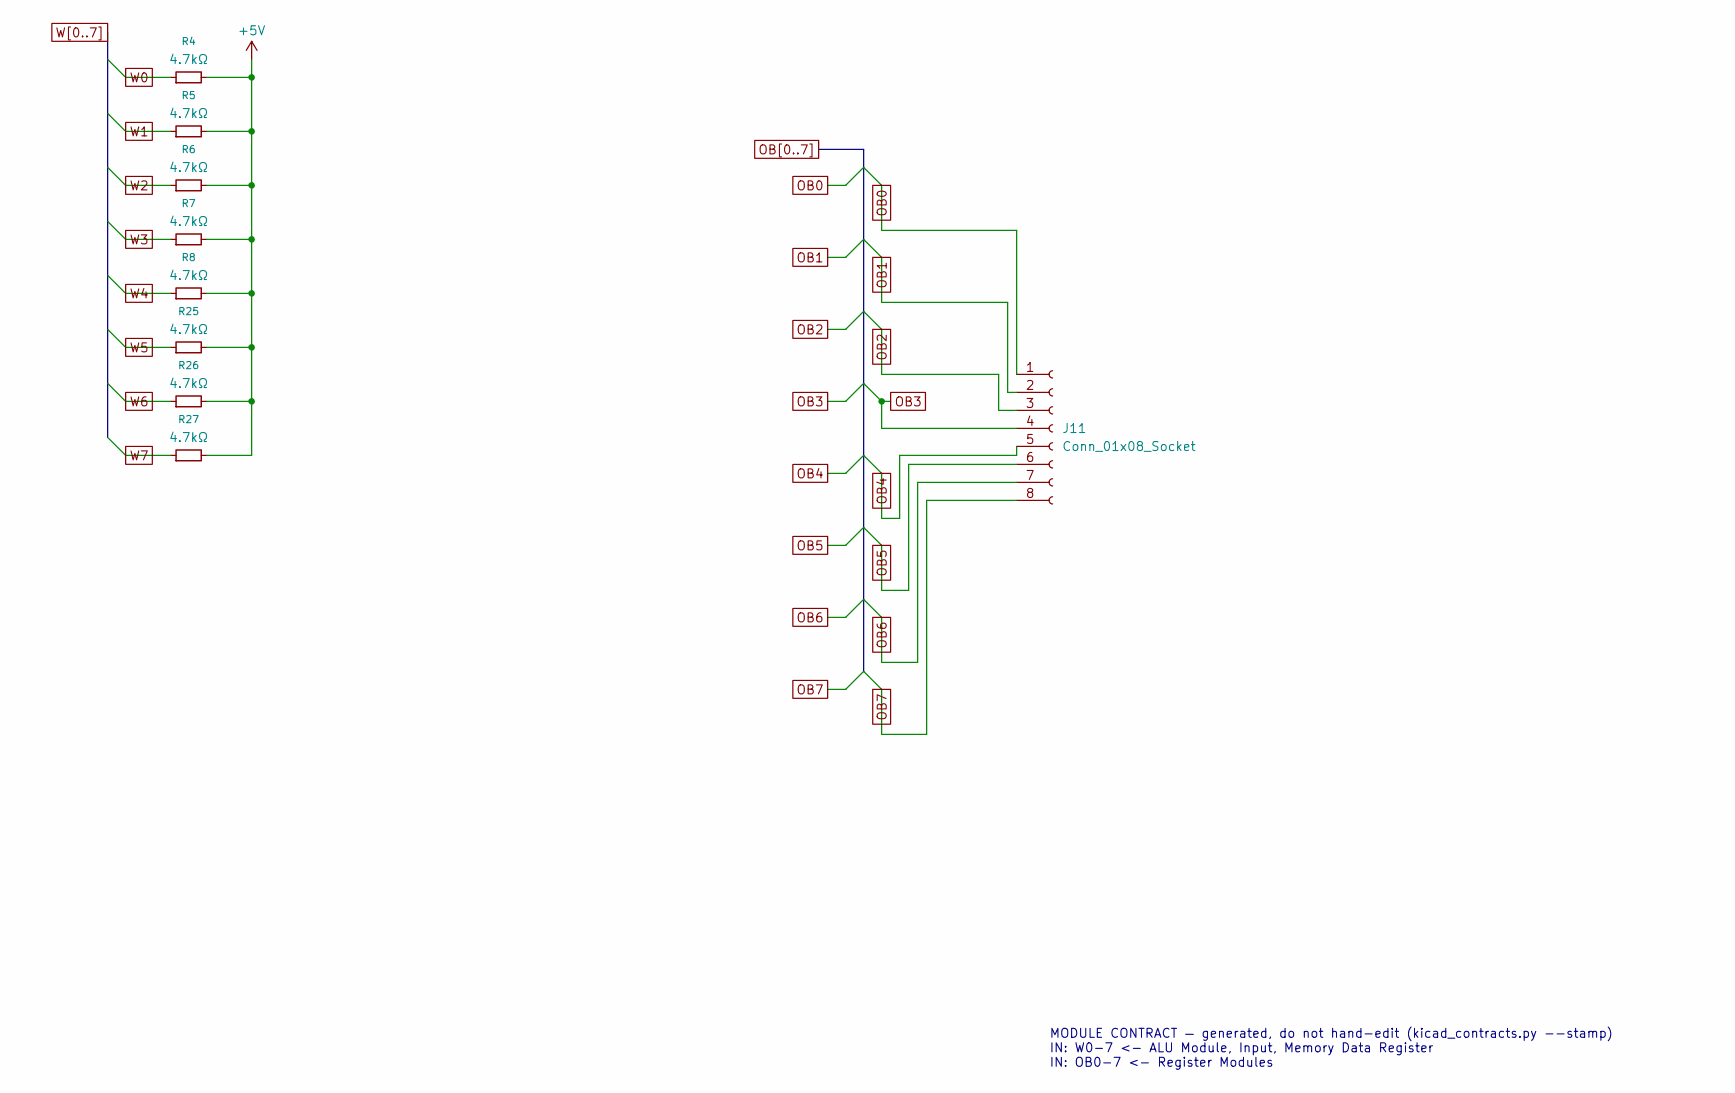
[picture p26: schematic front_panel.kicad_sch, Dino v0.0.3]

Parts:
J11: Conn_01x08_Socket; PinSocket_1x08_P2.54mm_Vertical
R4, R5, R6, R7, R8, R25, R26, R27: 4.7kΩ; R_Axial_DIN0207_L6.3mm_D2.5mm_P10.16mm_Horizontal

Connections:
+5V: R4.2, R5.2, R6.2, R7.2, R8.2, R25.2, R26.2, R27.2; also elsewhere on the board
OB0: J11.1; also elsewhere on the board
OB1: J11.2; also elsewhere on the board
OB2: J11.3; also elsewhere on the board
OB3: J11.4; also elsewhere on the board
OB4: J11.5; also elsewhere on the board
OB5: J11.6; also elsewhere on the board
OB6: J11.7; also elsewhere on the board
OB7: J11.8; also elsewhere on the board
W0: R4.1; also elsewhere on the board
W1: R5.1; also elsewhere on the board
W2: R6.1; also elsewhere on the board
W3: R7.1; also elsewhere on the board
W4: R8.1; also elsewhere on the board
W5: R25.1; also elsewhere on the board
W6: R26.1; also elsewhere on the board
W7: R27.1; also elsewhere on the board

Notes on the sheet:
MODULE CONTRACT — generated, do not hand-edit (kicad_contracts.py --stamp) IN: W0-7 <- ALU Module, Input, Memory Data Register IN: OB0-7 <- Register Modules

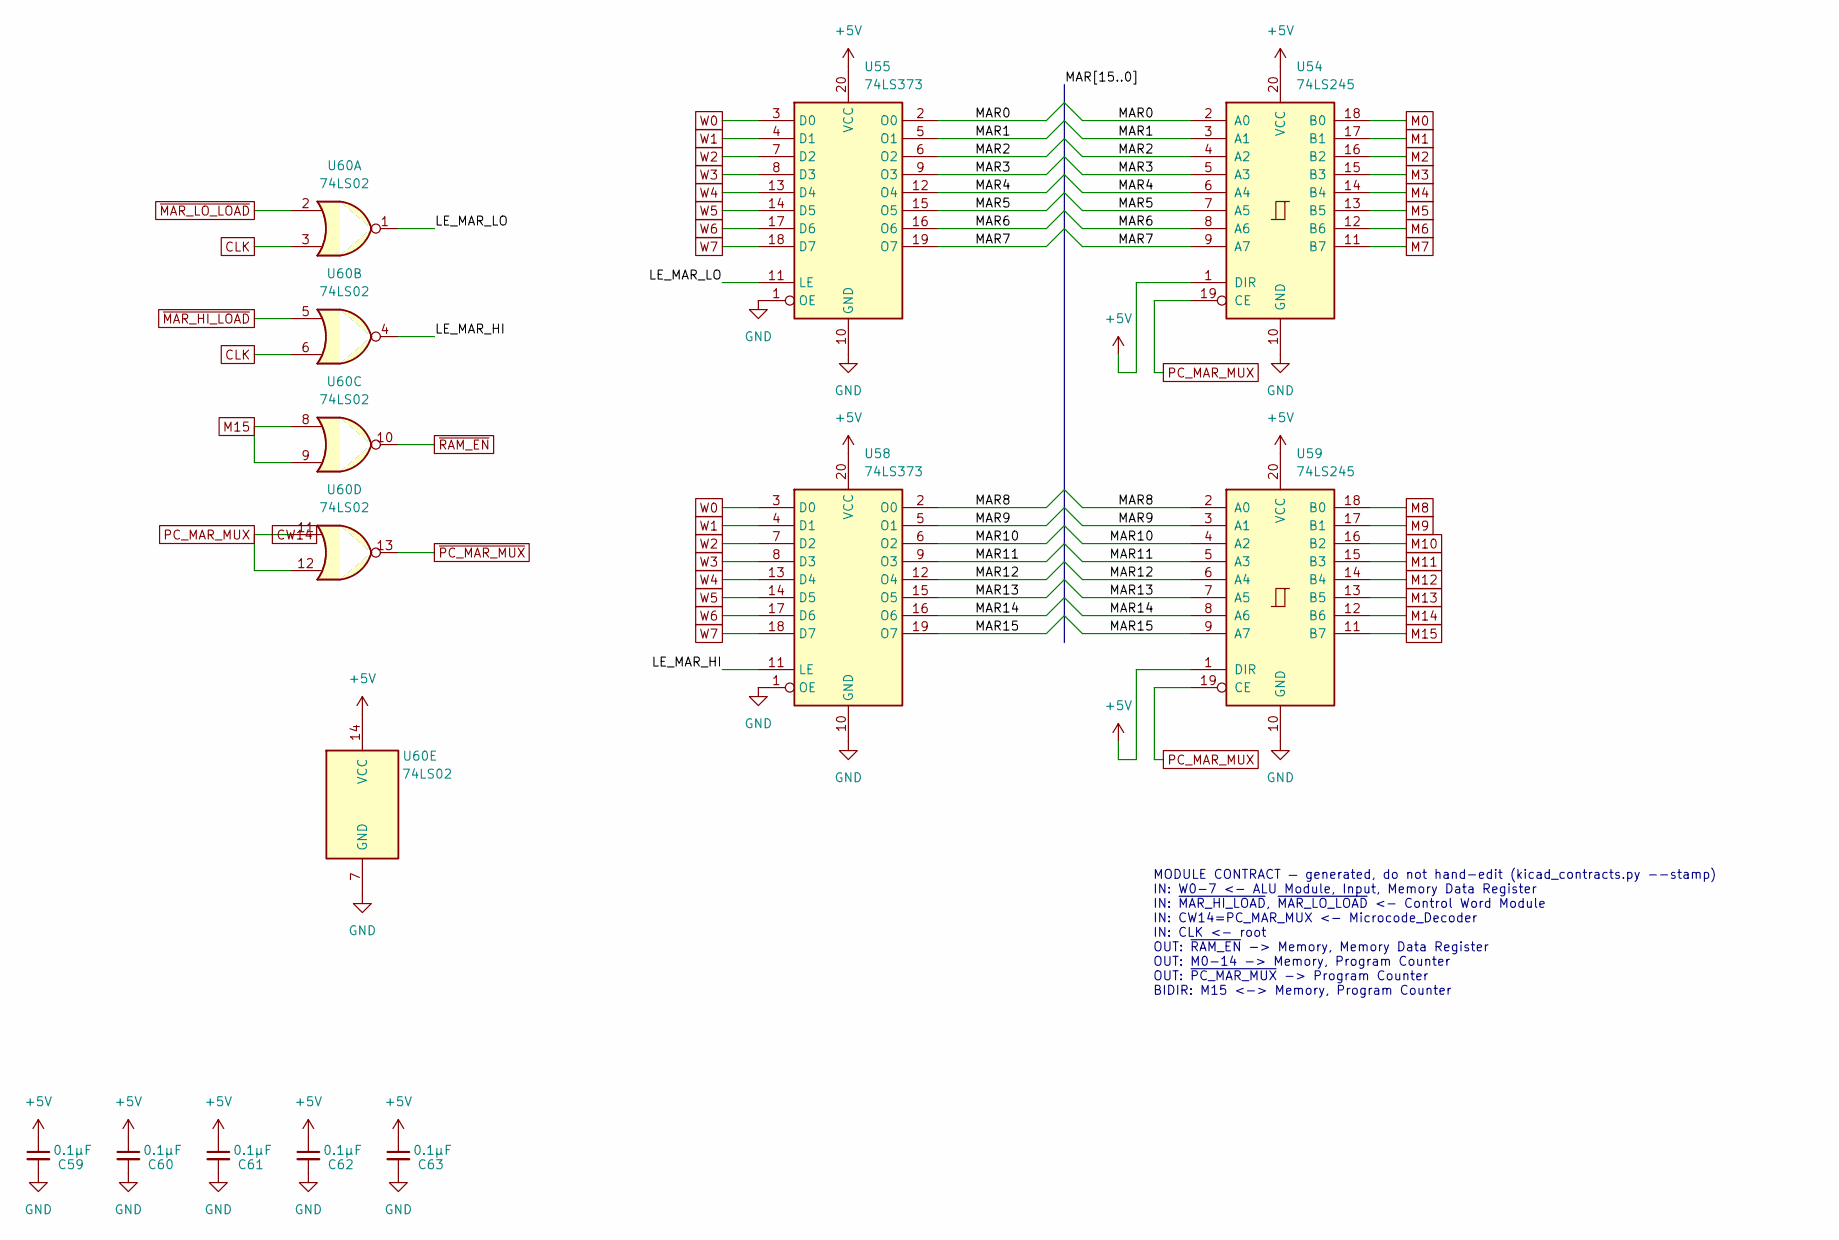
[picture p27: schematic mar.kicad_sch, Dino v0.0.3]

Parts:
C59, C60, C61, C62, C63: 0.1µF; C_Disc_D5.0mm_W2.5mm_P2.50mm
U54, U59: 74LS245; DIP-20_W7.62mm
U55, U58: 74LS373; DIP-20_W7.62mm
U60: 74LS02; DIP-14_W7.62mm

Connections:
+5V: C59.1, C60.1, C61.1, C62.1, C63.1, U54.1 (DIR), U54.20 (VCC), U55.20 (VCC), U58.20 (VCC), U59.1 (DIR), U59.20 (VCC), U60.14 (VCC); also elsewhere on the board
/Memory Address Regiser/LE_MAR_HI: U58.11 (LE), U60.4
/Memory Address Regiser/LE_MAR_LO: U55.11 (LE), U60.1
/Memory Address Regiser/MAR0: U54.2 (A0), U55.2 (O0)
/Memory Address Regiser/MAR1: U54.3 (A1), U55.5 (O1)
/Memory Address Regiser/MAR2: U54.4 (A2), U55.6 (O2)
/Memory Address Regiser/MAR3: U54.5 (A3), U55.9 (O3)
/Memory Address Regiser/MAR4: U54.6 (A4), U55.12 (O4)
/Memory Address Regiser/MAR5: U54.7 (A5), U55.15 (O5)
/Memory Address Regiser/MAR6: U54.8 (A6), U55.16 (O6)
/Memory Address Regiser/MAR7: U54.9 (A7), U55.19 (O7)
/Memory Address Regiser/MAR8: U58.2 (O0), U59.2 (A0)
/Memory Address Regiser/MAR9: U58.5 (O1), U59.3 (A1)
/Memory Address Regiser/MAR10: U58.6 (O2), U59.4 (A2)
/Memory Address Regiser/MAR11: U58.9 (O3), U59.5 (A3)
/Memory Address Regiser/MAR12: U58.12 (O4), U59.6 (A4)
/Memory Address Regiser/MAR13: U58.15 (O5), U59.7 (A5)
/Memory Address Regiser/MAR14: U58.16 (O6), U59.8 (A6)
/Memory Address Regiser/MAR15: U58.19 (O7), U59.9 (A7)
CLK: U60.3, U60.6; also elsewhere on the board
CW14: U54.19 (CE), U59.19 (CE), U60.11, U60.12; also elsewhere on the board
GND: C59.2, C60.2, C61.2, C62.2, C63.2, U54.10 (GND), U55.1 (OE), U55.10 (GND), U58.1 (OE), U58.10 (GND), U59.10 (GND), U60.7 (GND); also elsewhere on the board
M0: U54.18 (B0); also elsewhere on the board
M1: U54.17 (B1); also elsewhere on the board
M2: U54.16 (B2); also elsewhere on the board
M3: U54.15 (B3); also elsewhere on the board
M4: U54.14 (B4); also elsewhere on the board
M5: U54.13 (B5); also elsewhere on the board
M6: U54.12 (B6); also elsewhere on the board
M7: U54.11 (B7); also elsewhere on the board
M8: U59.18 (B0); also elsewhere on the board
M9: U59.17 (B1); also elsewhere on the board
M10: U59.16 (B2); also elsewhere on the board
M11: U59.15 (B3); also elsewhere on the board
M12: U59.14 (B4); also elsewhere on the board
M13: U59.13 (B5); also elsewhere on the board
M14: U59.12 (B6); also elsewhere on the board
M15: U59.11 (B7), U60.8, U60.9; also elsewhere on the board
W0: U55.3 (D0), U58.3 (D0); also elsewhere on the board
W1: U55.4 (D1), U58.4 (D1); also elsewhere on the board
W2: U55.7 (D2), U58.7 (D2); also elsewhere on the board
W3: U55.8 (D3), U58.8 (D3); also elsewhere on the board
W4: U55.13 (D4), U58.13 (D4); also elsewhere on the board
W5: U55.14 (D5), U58.14 (D5); also elsewhere on the board
W6: U55.17 (D6), U58.17 (D6); also elsewhere on the board
W7: U55.18 (D7), U58.18 (D7); also elsewhere on the board
~MAR_HI_LOAD: U60.5; also elsewhere on the board
~MAR_LO_LOAD: U60.2; also elsewhere on the board
~PC_MAR_MUX: U60.13; also elsewhere on the board
~RAM_EN: U60.10; also elsewhere on the board

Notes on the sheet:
MODULE CONTRACT — generated, do not hand-edit (kicad_contracts.py --stamp) IN: W0-7 <- ALU Module, Input, Memory Data Register IN: ~{MAR_HI_LOAD}, ~{MAR_LO_LOAD} <- Control Word Module IN: CW14=PC_MAR_MUX <- Microcode_Decoder IN: CLK <- root OUT: ~{RAM_EN} -> Memory, Memory Data Register OUT: M0-14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

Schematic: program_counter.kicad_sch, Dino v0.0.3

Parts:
C3, C4, C5, C6, C11, C12, C13, C14, C15, C16: 0.1µF; C_Disc_D5.0mm_W2.5mm_P2.50mm
U1, U2, U3, U4: 74LS193; DIP-16_W7.62mm
U10: 74LS02; DIP-14_W7.62mm
U11, U12, U13, U14: 74LS245; DIP-20_W7.62mm
U36: 7400; DIP-14_W7.62mm

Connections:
+5V: C3.1, C4.1, C5.2, C6.2, C11.2, C12.2, C13.1, C14.1, C15.1, C16.1, U1.4 (DOWN), U1.16 (VCC), U2.16 (VCC), U3.16 (VCC), U4.16 (VCC), U10.14 (VCC), U11.1 (DIR), U11.20 (VCC), U12.1 (DIR), U12.20 (VCC), U13.20 (VCC), U14.20 (VCC), U36.14 (VCC); also elsewhere on the board
/Program Counter/PCD0: U1.15 (A), U11.18 (B0)
/Program Counter/PCD1: U1.1 (B), U11.17 (B1)
/Program Counter/PCD2: U1.10 (C), U11.16 (B2)
/Program Counter/PCD3: U1.9 (D), U11.15 (B3)
/Program Counter/PCD4: U2.15 (A), U11.14 (B4)
/Program Counter/PCD5: U2.1 (B), U11.13 (B5)
/Program Counter/PCD6: U2.10 (C), U11.12 (B6)
/Program Counter/PCD7: U2.9 (D), U11.11 (B7)
/Program Counter/PCD8: U3.15 (A), U12.18 (B0)
/Program Counter/PCD9: U3.1 (B), U12.17 (B1)
/Program Counter/PCD10: U3.10 (C), U12.16 (B2)
/Program Counter/PCD11: U3.9 (D), U12.15 (B3)
/Program Counter/PCD12: U4.15 (A), U12.14 (B4)
/Program Counter/PCD13: U4.1 (B), U12.13 (B5)
/Program Counter/PCD14: U4.10 (C), U12.12 (B6)
/Program Counter/PCD15: U4.9 (D), U12.11 (B7)
/Program Counter/PC_CLEAR: U10.1, U10.5
/Program Counter/PC_CLEAR_OR_RESET: U1.14 (CLR), U2.14 (CLR), U3.14 (CLR), U4.14 (CLR), U10.10
/Program Counter/PC_UP_STABLE: U1.5 (UP), U36.3
/Program Counter/~BO1: U1.13 (~BO), U2.4 (DOWN)
/Program Counter/~BO2: U2.13 (~BO), U3.4 (DOWN)
/Program Counter/~BO3: U3.13 (~BO), U4.4 (DOWN)
/Program Counter/~CO1: U1.12 (~CO), U2.5 (UP)
/Program Counter/~CO2: U2.12 (~CO), U3.5 (UP)
/Program Counter/~CO3: U3.12 (~CO), U4.5 (UP)
/Program Counter/~PC_LOAD_STABLE: U1.11 (~LOAD), U2.11 (~LOAD), U3.11 (~LOAD), U4.11 (~LOAD), U36.8
CLK: U10.3; also elsewhere on the board
CW13: U36.1; also elsewhere on the board
GND: C3.2, C4.2, C5.1, C6.1, C11.1, C12.1, C13.2, C14.2, C15.2, C16.2, U1.8 (GND), U2.8 (GND), U3.8 (GND), U4.8 (GND), U10.7 (GND), U10.11, U10.12, U11.10 (GND), U12.10 (GND), U13.1 (DIR), U13.10 (GND), U14.1 (DIR), U14.10 (GND), U36.7 (GND), U36.12, U36.13; also elsewhere on the board
M0: U11.2 (A0), U13.2 (A0); also elsewhere on the board
M1: U11.3 (A1), U13.3 (A1); also elsewhere on the board
M2: U11.4 (A2), U13.4 (A2); also elsewhere on the board
M3: U11.5 (A3), U13.5 (A3); also elsewhere on the board
M4: U11.6 (A4), U13.6 (A4); also elsewhere on the board
M5: U11.7 (A5), U13.7 (A5); also elsewhere on the board
M6: U11.8 (A6), U13.8 (A6); also elsewhere on the board
M7: U11.9 (A7), U13.9 (A7); also elsewhere on the board
M8: U12.2 (A0), U14.2 (A0); also elsewhere on the board
M9: U12.3 (A1), U14.3 (A1); also elsewhere on the board
M10: U12.4 (A2), U14.4 (A2); also elsewhere on the board
M11: U12.5 (A3), U14.5 (A3); also elsewhere on the board
M12: U12.6 (A4), U14.6 (A4); also elsewhere on the board
M13: U12.7 (A5), U14.7 (A5); also elsewhere on the board
M14: U12.8 (A6), U14.8 (A6); also elsewhere on the board
M15: U12.9 (A7), U14.9 (A7); also elsewhere on the board
unnamed: U10.4, U10.8, U10.9
unnamed: U36.6, U36.9
PC0: U1.3 (QA), U13.18 (B0); also elsewhere on the board
PC1: U1.2 (QB), U13.17 (B1); also elsewhere on the board
PC2: U1.6 (QC), U13.16 (B2); also elsewhere on the board
PC3: U1.7 (QD), U13.15 (B3); also elsewhere on the board
PC4: U2.3 (QA), U13.14 (B4); also elsewhere on the board
PC5: U2.2 (QB), U13.13 (B5); also elsewhere on the board
PC6: U2.6 (QC), U13.12 (B6); also elsewhere on the board
PC7: U2.7 (QD), U13.11 (B7); also elsewhere on the board
PC8: U3.3 (QA), U14.18 (B0); also elsewhere on the board
PC9: U3.2 (QB), U14.17 (B1); also elsewhere on the board
PC10: U3.6 (QC), U14.16 (B2); also elsewhere on the board
PC11: U3.7 (QD), U14.15 (B3); also elsewhere on the board
PC12: U4.3 (QA), U14.14 (B4); also elsewhere on the board
PC13: U4.2 (QB), U14.13 (B5); also elsewhere on the board
PC14: U4.6 (QC), U14.12 (B6); also elsewhere on the board
PC15: U4.7 (QD), U14.11 (B7); also elsewhere on the board
RESET: U10.6; also elsewhere on the board
~CLK: U36.2, U36.10; also elsewhere on the board
~PC_CLEAR: U10.2; also elsewhere on the board
~PC_LOAD: U11.19 (CE), U12.19 (CE), U36.4, U36.5; also elsewhere on the board
~PC_MAR_MUX: U13.19 (CE), U14.19 (CE); also elsewhere on the board

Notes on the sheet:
MODULE CONTRACT — generated, do not hand-edit (kicad_contracts.py --stamp) IN: ~{PC_CLEAR}, ~{PC_LOAD} <- Control Word Module IN: ~{PC_MAR_MUX} <- Memory Address Regiser IN: CW13=PC_UP <- Microcode_Decoder IN: CLK, RESET, ~{CLK} <- root OUT: PC0-15 -> Memory Data Register OUT: M0-15 -> Memory, Memo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

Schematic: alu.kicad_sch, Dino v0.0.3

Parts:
C49, C50, C51, C52, C53, C54, C55, C56, C57, C58, C82: 0.1µF; C_Disc_D5.0mm_W2.5mm_P2.50mm
U38, U40: 74F382N; DIP-20_W7.62mm
U45, U46, U47: 74LS373; DIP-20_W7.62mm
U48, U77: 74LS157; DIP-16_W7.62mm
U49: 74LS273; DIP-20_W7.62mm
U50, U52: 74LS02; DIP-14_W7.62mm
U53: 74LS08; DIP-14_W7.62mm

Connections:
+5V: C49.1, C50.1, C51.1, C52.1, C53.1, C54.1, C55.1, C56.1, C57.1, C58.1, C82.1, U38.20 (VCC), U40.20 (VCC), U45.20 (VCC), U46.20 (VCC), U47.20 (VCC), U48.16 (VCC), U49.20 (VCC), U50.14 (VCC), U52.14 (VCC), U53.14 (VCC), U77.16 (VCC); also elsewhere on the board
/ALU Module/ALU_C: U40.14 (CN+4), U48.2 (I0a)
/ALU Module/ALU_CIN: U38.15 (CN), U50.13
/ALU Module/ALU_V: U40.13 (OVR), U48.11 (I0c)
/ALU Module/CRY: U38.14 (CN+4), U40.15 (CN)
/ALU Module/F0: U38.8 (F0), U47.3 (D0), U52.2
/ALU Module/F01: U52.1, U53.1
/ALU Module/F1: U38.9 (F1), U47.4 (D1), U52.3
/ALU Module/F2: U38.11 (F2), U47.7 (D2), U52.5
/ALU Module/F3: U38.12 (F3), U47.8 (D3), U52.6
/ALU Module/F4: U40.8 (F0), U47.13 (D4), U52.8
/ALU Module/F5: U40.9 (F1), U47.14 (D5), U52.9
/ALU Module/F6: U40.11 (F2), U47.17 (D6), U52.11
/ALU Module/F7: U40.12 (F3), U47.18 (D7), U48.14 (I0d), U52.12
/ALU Module/F23: U52.4, U53.2
/ALU Module/F45: U52.10, U53.4
/ALU Module/F67: U52.13, U53.5
/ALU Module/F0123: U53.3, U53.9
/ALU Module/F4567: U53.6, U53.10
/ALU Module/FLAG_C: U48.3 (I1a), U49.2 (Q0), U77.2 (I0a)
/ALU Module/FLAG_N: U48.13 (I1d), U49.9 (Q3)
/ALU Module/FLAG_V: U48.10 (I1c), U49.6 (Q2)
/ALU Module/FLAG_Z: U48.6 (I1b), U49.5 (Q1), U77.3 (I1a)
/ALU Module/LE_TMP_A: U45.11 (LE), U50.1
/ALU Module/LE_TMP_B: U46.11 (LE), U50.4
/ALU Module/TA0: U38.3 (A0), U45.2 (O0)
/ALU Module/TA1: U38.1 (A1), U45.5 (O1)
/ALU Module/TA2: U38.19 (A2), U45.6 (O2)
/ALU Module/TA3: U38.17 (A3), U45.9 (O3)
/ALU Module/TA4: U40.3 (A0), U45.12 (O4)
/ALU Module/TA5: U40.1 (A1), U45.15 (O5)
/ALU Module/TA6: U40.19 (A2), U45.16 (O6)
/ALU Module/TA7: U40.17 (A3), U45.19 (O7)
/ALU Module/TB0: U38.4 (B0), U46.2 (O0)
/ALU Module/TB1: U38.2 (B1), U46.5 (O1)
/ALU Module/TB2: U38.18 (B2), U46.6 (O2)
/ALU Module/TB3: U38.16 (B3), U46.9 (O3)
/ALU Module/TB4: U40.4 (B0), U46.12 (O4)
/ALU Module/TB5: U40.2 (B1), U46.15 (O5)
/ALU Module/TB6: U40.18 (B2), U46.16 (O6)
/ALU Module/TB7: U40.16 (B3), U46.19 (O7)
/ALU Module/Z: U48.5 (I0b), U53.8
CLK: U47.11 (LE), U50.3, U50.6; also elsewhere on the board
COND_FLAG: U77.4 (Za); also elsewhere on the board
CW9: U38.7 (S2), U40.7 (S2); also elsewhere on the board
CW10: U38.6 (S1), U40.6 (S1), U53.12; also elsewhere on the board
CW11: U38.5 (S0), U40.5 (S0), U53.13; also elsewhere on the board
CW21: U77.1 (S); also elsewhere on the board
GND: C49.2, C50.2, C51.2, C52.2, C53.2, C54.2, C55.2, C56.2, C57.2, C58.2, C82.2, U38.10 (GND), U40.10 (GND), U45.1 (OE), U45.10 (GND), U46.1 (OE), U46.10 (GND), U47.10 (GND), U48.8 (GND), U48.15 (E), U49.10 (GND), U49.13 (D4), U49.14 (D5), U49.17 (D6), U49.18 (D7), U50.7 (GND), U50.8, U50.9, U52.7 (GND), U53.7 (GND), U77.5 (I0b), U77.6 (I1b), U77.8 (GND), U77.10 (I1c), U77.11 (I0c), U77.13 (I1d), U77.14 (I0d), U77.15 (E); also elsewhere on the board
unnamed: U48.4 (Za), U49.3 (D0)
unnamed: U48.7 (Zb), U49.4 (D1)
unnamed: U48.9 (Zc), U49.7 (D2)
unnamed: U48.12 (Zd), U49.8 (D3)
unnamed: U50.11, U50.12, U53.11
W0: U45.3 (D0), U46.3 (D0), U47.2 (O0); also elsewhere on the board
W1: U45.4 (D1), U46.4 (D1), U47.5 (O1); also elsewhere on the board
W2: U45.7 (D2), U46.7 (D2), U47.6 (O2); also elsewhere on the board
W3: U45.8 (D3), U46.8 (D3), U47.9 (O3); also elsewhere on the board
W4: U45.13 (D4), U46.13 (D4), U47.12 (O4); also elsewhere on the board
W5: U45.14 (D5), U46.14 (D5), U47.15 (O5); also elsewhere on the board
W6: U45.17 (D6), U46.17 (D6), U47.16 (O6); also elsewhere on the board
W7: U45.18 (D7), U46.18 (D7), U47.19 (O7); also elsewhere on the board
~ALU_OUT: U47.1 (OE), U48.1 (S); also elsewhere on the board
~CLK: U49.11 (Cp); also elsewhere on the board
~REG_A_LOAD: U50.2; also elsewhere on the board
~REG_B_LOAD: U50.5; also elsewhere on the board
~RESET: U49.1 (~Mr); also elsewhere on the board

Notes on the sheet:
CLR
110
111
BSUB
011
000
AND
100
ALU_HI
010
XOR
SET
TMP_A
001
ALU_LO
Decoupling Caps for all ICs
MODULE CONTRACT — generated, do not hand-edit (kicad_contracts.py --stamp) IN: ~{ALU_OUT}, ~{REG_A_LOAD}, ~{REG_B_LOAD} <- Control Word Module IN: CW10=SA1, CW11=SA0, CW9=SA2 <- Microcode_Decoder IN: CLK, ~{CLK}, ~{RESET} <- root OUT: FLAG_Z -> Control Word Module BIDIR: W0-7 <-> Input, Memory Addr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
101
[11:9] ALU Bus
SUB
ADD
TMP_B

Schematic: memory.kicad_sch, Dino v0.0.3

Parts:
C33, C34, C35, C36, C37, C79, C80: 0.1µF; C_Disc_D5.0mm_W2.5mm_P2.50mm
R3: 100Ω; R_Axial_DIN0207_L6.3mm_D2.5mm_P10.16mm_Horizontal
U19, U21: 74LS245; DIP-20_W7.62mm
U24: AT28C256; DIP-28_W15.24mm
U26: MCM60256AP; DIP-28_W15.24mm
U51: 7400; DIP-14_W7.62mm
U74: 74LS00; DIP-14_W7.62mm
U75: 74LS32; DIP-14_W7.62mm

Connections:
+5V: C33.1, C34.1, C35.1, C36.1, C37.1, C79.1, C80.1, U19.1 (DIR), U19.20 (VCC), U21.20 (VCC), U24.27 (~WE), U24.28 (VCC), U26.28 (VCC), U51.14 (VCC), U74.14 (VCC), U75.14 (VCC); also elsewhere on the board
/Memory/CLK_M: R3.2, U75.13
/Memory/RAM_MDR_DIS: U51.8, U51.12, U51.13
/Memory/~M14: U74.3, U74.5
/Memory/~RAM_MDR_EN: U21.19 (CE), U51.11
/Memory/~RAM_OE_G: U26.22 (~OE), U51.9, U74.8
/Memory/~RAM_WRITE_EN: U26.27 (~WE), U51.6, U75.4
/Memory/~WRITE_DIR: U21.1 (DIR), U51.3, U51.10
CLK: R3.1; also elsewhere on the board
GND: C33.2, C34.2, C35.2, C36.2, C37.2, C79.2, C80.2, U19.10 (GND), U21.10 (GND), U24.14 (GND), U26.14 (GND), U51.7 (GND), U74.7 (GND), U75.7 (GND), U75.10; also elsewhere on the board
M0: U24.10 (A0), U26.10 (A0); also elsewhere on the board
M1: U24.9 (A1), U26.9 (A1); also elsewhere on the board
M2: U24.8 (A2), U26.8 (A2); also elsewhere on the board
M3: U24.7 (A3), U26.7 (A3); also elsewhere on the board
M4: U24.6 (A4), U26.6 (A4); also elsewhere on the board
M5: U24.5 (A5), U26.5 (A5); also elsewhere on the board
M6: U24.4 (A6), U26.4 (A6); also elsewhere on the board
M7: U24.3 (A7), U26.3 (A7); also elsewhere on the board
M8: U24.25 (A8), U26.25 (A8); also elsewhere on the board
M9: U24.24 (A9), U26.24 (A9); also elsewhere on the board
M10: U24.21 (A10), U26.21 (A10); also elsewhere on the board
M11: U24.23 (A11), U26.23 (A11); also elsewhere on the board
M12: U24.2 (A12), U26.2 (A12); also elsewhere on the board
M13: U24.26 (A13), U26.26 (A13); also elsewhere on the board
M14: U24.1 (A14), U26.1 (A14), U74.1, U74.2, U74.13; also elsewhere on the board
M15: U74.10; also elsewhere on the board
MDR0: U19.18 (B0), U21.18 (B0); also elsewhere on the board
MDR1: U19.17 (B1), U21.17 (B1); also elsewhere on the board
MDR2: U19.16 (B2), U21.16 (B2); also elsewhere on the board
MDR3: U19.15 (B3), U21.15 (B3); also elsewhere on the board
MDR4: U19.14 (B4), U21.14 (B4); also elsewhere on the board
MDR5: U19.13 (B5), U21.13 (B5); also elsewhere on the board
MDR6: U19.12 (B6), U21.12 (B6); also elsewhere on the board
MDR7: U19.11 (B7), U21.11 (B7); also elsewhere on the board
unnamed: U19.2 (A0), U24.11 (I/O0)
unnamed: U19.3 (A1), U24.12 (I/O1)
unnamed: U19.4 (A2), U24.13 (I/O2)
unnamed: U19.5 (A3), U24.15 (I/O3)
unnamed: U19.6 (A4), U24.16 (I/O4)
unnamed: U19.7 (A5), U24.17 (I/O5)
unnamed: U19.8 (A6), U24.18 (I/O6)
unnamed: U19.9 (A7), U24.19 (I/O7)
unnamed: U21.2 (A0), U26.11 (DQ0)
unnamed: U21.3 (A1), U26.12 (DQ1)
unnamed: U21.4 (A2), U26.13 (DQ2)
unnamed: U21.5 (A3), U26.15 (DQ3)
unnamed: U21.6 (A4), U26.16 (DQ4)
unnamed: U21.7 (A5), U26.17 (DQ5)
unnamed: U21.8 (A6), U26.18 (DQ6)
unnamed: U21.9 (A7), U26.19 (DQ7)
RAM_OE_ON: U74.9; also elsewhere on the board
READS_IDLE: U75.2; also elsewhere on the board
RESET: U75.9; also elsewhere on the board
RESET_B: U75.8; also elsewhere on the board
WRITE_DIR: U51.1, U51.2, U51.5; also elsewhere on the board
~CLK: U51.4; also elsewhere on the board
~IO_RD_Q: U75.11; also elsewhere on the board
~IO_RD: U75.3, U75.12; also elsewhere on the board
~IO_SEL: U74.11, U75.1, U75.5; also elsewhere on the board
~IO_WR: U75.6; also elsewhere on the board
~RAM_EN: U26.20 (~CE), U74.4, U74.12; also elsewhere on the board
~ROM_BUF_EN: U19.19 (CE), U24.22 (~OE); also elsewhere on the board
~ROM_SEL: U24.20 (~CE), U74.6; also elsewhere on the board

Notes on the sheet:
WRITE_DIR net is defined on MDR
RAM
MODULE CONTRACT — generated, do not hand-edit (kicad_contracts.py --stamp) IN: ~{ROM_OUT} <- Control Word Module IN: ~{RAM_EN} <- Memory Address Regiser IN: M0-15 <- Memory Address Regiser, Program Counter IN: RAM_OE_ON, READS_IDLE, WRITE_DIR, ~{ROM_BUF_EN} <- Memory Data Register IN: CLK, RESET, ~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
Derived from INV(A15) from MAR
ROM 0x0000-0x7FFF, RAM 0x8000-0xFFFF, selected by A15
ROM

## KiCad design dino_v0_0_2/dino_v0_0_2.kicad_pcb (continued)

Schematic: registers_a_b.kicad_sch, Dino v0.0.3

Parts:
C38, C39, C40, C41, C42, C43, C44, C45, C46, C47, C64: 0.1µF; C_Disc_D5.0mm_W2.5mm_P2.50mm
U5: 74LS08; DIP-14_W7.62mm
U31, U32, U33, U35: 74LS373; DIP-20_W7.62mm
U41, U42, U43, U44: 74LS245; DIP-20_W7.62mm
U57: 74LS02; DIP-14_W7.62mm

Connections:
+5V: C38.1, C39.1, C40.1, C41.1, C42.1, C43.1, C44.1, C45.1, C46.1, C47.2, C64.1, U5.14 (VCC), U31.20 (VCC), U32.20 (VCC), U33.20 (VCC), U35.20 (VCC), U41.20 (VCC), U42.20 (VCC), U43.20 (VCC), U44.1 (DIR), U44.20 (VCC), U57.14 (VCC); also elsewhere on the board
/Register Modules/AB0: U31.2 (O0), U31.3 (D0), U41.18 (B0)
/Register Modules/AB1: U31.4 (D1), U31.5 (O1), U41.17 (B1)
/Register Modules/AB2: U31.6 (O2), U31.7 (D2), U41.16 (B2)
/Register Modules/AB3: U31.8 (D3), U31.9 (O3), U41.15 (B3)
/Register Modules/AB4: U31.12 (O4), U31.13 (D4), U41.14 (B4)
/Register Modules/AB5: U31.14 (D5), U31.15 (O5), U41.13 (B5)
/Register Modules/AB6: U31.16 (O6), U31.17 (D6), U41.12 (B6)
/Register Modules/AB7: U31.18 (D7), U31.19 (O7), U41.11 (B7)
/Register Modules/BB0: U32.2 (O0), U32.3 (D0), U42.18 (B0)
/Register Modules/BB1: U32.4 (D1), U32.5 (O1), U42.17 (B1)
/Register Modules/BB2: U32.6 (O2), U32.7 (D2), U42.16 (B2)
/Register Modules/BB3: U32.8 (D3), U32.9 (O3), U42.15 (B3)
/Register Modules/BB4: U32.12 (O4), U32.13 (D4), U42.14 (B4)
/Register Modules/BB5: U32.14 (D5), U32.15 (O5), U42.13 (B5)
/Register Modules/BB6: U32.16 (O6), U32.17 (D6), U42.12 (B6)
/Register Modules/BB7: U32.18 (D7), U32.19 (O7), U42.11 (B7)
/Register Modules/CB0: U33.2 (O0), U33.3 (D0), U43.18 (B0)
/Register Modules/CB1: U33.4 (D1), U33.5 (O1), U43.17 (B1)
/Register Modules/CB2: U33.6 (O2), U33.7 (D2), U43.16 (B2)
/Register Modules/CB3: U33.8 (D3), U33.9 (O3), U43.15 (B3)
/Register Modules/CB4: U33.12 (O4), U33.13 (D4), U43.14 (B4)
/Register Modules/CB5: U33.14 (D5), U33.15 (O5), U43.13 (B5)
/Register Modules/CB6: U33.16 (O6), U33.17 (D6), U43.12 (B6)
/Register Modules/CB7: U33.18 (D7), U33.19 (O7), U43.11 (B7)
/Register Modules/~A_EN: U5.3, U41.19 (CE)
/Register Modules/~B_EN: U5.6, U42.19 (CE)
/Register Modules/~C_EN: U5.8, U43.19 (CE)
/Register Modules/~REG_A_LE: U31.11 (LE), U57.1
/Register Modules/~REG_B_LE: U32.11 (LE), U57.4
/Register Modules/~REG_C_LE: U33.11 (LE), U57.10
/Register Modules/~REG_OUT_LE: U35.11 (LE), U57.13
CLK: U57.3, U57.6, U57.9, U57.12; also elsewhere on the board
GND: C38.2, C39.2, C40.2, C41.2, C42.2, C43.2, C44.2, C45.2, C46.2, C47.1, C64.2, U5.7 (GND), U5.12, U5.13, U31.10 (GND), U32.10 (GND), U33.10 (GND), U35.1 (OE), U35.10 (GND), U41.10 (GND), U42.10 (GND), U43.10 (GND), U44.10 (GND), U57.7 (GND); also elsewhere on the board
MDR0: U41.2 (A0), U42.2 (A0), U43.2 (A0), U44.2 (A0); also elsewhere on the board
MDR1: U41.3 (A1), U42.3 (A1), U43.3 (A1), U44.3 (A1); also elsewhere on the board
MDR2: U41.4 (A2), U42.4 (A2), U43.4 (A2), U44.4 (A2); also elsewhere on the board
MDR3: U41.5 (A3), U42.5 (A3), U43.5 (A3), U44.5 (A3); also elsewhere on the board
MDR4: U41.6 (A4), U42.6 (A4), U43.6 (A4), U44.6 (A4); also elsewhere on the board
MDR5: U41.7 (A5), U42.7 (A5), U43.7 (A5), U44.7 (A5); also elsewhere on the board
MDR6: U41.8 (A6), U42.8 (A6), U43.8 (A6), U44.8 (A6); also elsewhere on the board
MDR7: U41.9 (A7), U42.9 (A7), U43.9 (A7), U44.9 (A7); also elsewhere on the board
unnamed: U35.3 (D0), U44.18 (B0)
unnamed: U35.4 (D1), U44.17 (B1)
unnamed: U35.7 (D2), U44.16 (B2)
unnamed: U35.8 (D3), U44.15 (B3)
unnamed: U35.13 (D4), U44.14 (B4)
unnamed: U35.14 (D5), U44.13 (B5)
unnamed: U35.17 (D6), U44.12 (B6)
unnamed: U35.18 (D7), U44.11 (B7)
OB0: U35.2 (O0); also elsewhere on the board
OB1: U35.5 (O1); also elsewhere on the board
OB2: U35.6 (O2); also elsewhere on the board
OB3: U35.9 (O3); also elsewhere on the board
OB4: U35.12 (O4); also elsewhere on the board
OB5: U35.15 (O5); also elsewhere on the board
OB6: U35.16 (O6); also elsewhere on the board
OB7: U35.19 (O7); also elsewhere on the board
~REG_A_LOAD: U5.1, U57.2; also elsewhere on the board
~REG_A_OUT: U5.2, U31.1 (OE), U41.1 (DIR); also elsewhere on the board
~REG_B_LOAD: U5.4, U57.5; also elsewhere on the board
~REG_B_OUT: U5.5, U32.1 (OE), U42.1 (DIR); also elsewhere on the board
~REG_C_LOAD: U5.9, U57.8; also elsewhere on the board
~REG_C_OUT: U5.10, U33.1 (OE), U43.1 (DIR); also elsewhere on the board
~REG_OUT_LOAD: U44.19 (CE), U57.11; also elsewhere on the board

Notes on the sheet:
Decoupling Caps for U31,U41,U42,U32,U33,U43,U44,U35
MODULE CONTRACT — generated, do not hand-edit (kicad_contracts.py --stamp) IN: ~{REG_A_LOAD}, ~{REG_A_OUT}, ~{REG_B_LOAD}, ~{REG_B_OUT}, ~{REG_C_LOAD}, ~{REG_C_OUT}, ~{REG_OUT_LOAD} <- Control Word Module IN: CLK <- root OUT: MDR0-7 -> Memory, Memory Data Register, Stack Pointer OUT: OB0-7 -> Output
D_OUT

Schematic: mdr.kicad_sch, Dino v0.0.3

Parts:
C27, C28, C29, C30, C31, C32, C77, C78: 0.1µF; C_Disc_D5.0mm_W2.5mm_P2.50mm
U18, U34: 74LS373; DIP-20_W7.62mm
U22: 74LS02; DIP-14_W7.62mm
U25, U72, U73: 74LS245; DIP-20_W7.62mm
U37: 74LS04; DIP-14_W7.62mm
U39: 74LS00; DIP-14_W7.62mm

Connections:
+5V: C27.1, C28.1, C29.2, C30.1, C31.1, C32.2, C77.2, C78.2, U18.20 (VCC), U22.14 (VCC), U25.20 (VCC), U34.20 (VCC), U37.14 (VCC), U39.4, U39.14 (VCC), U72.1 (DIR), U72.20 (VCC), U73.1 (DIR), U73.20 (VCC); also elsewhere on the board
/Memory Data Register/BUS_DIR: U25.1 (DIR), U39.8
/Memory Data Register/FETCH_RAM: U22.10, U37.9
/Memory Data Register/LE_IR: U22.1, U34.11 (LE)
/Memory Data Register/LE_MDR: U18.11 (LE), U39.6
/Memory Data Register/MDR_OUT: U22.6, U37.6
/Memory Data Register/READ: U37.1, U39.3
/Memory Data Register/ROM_BUF_ON: U22.13, U37.13
/Memory Data Register/~FETCH_RAM: U37.8, U39.13
/Memory Data Register/~MDR_EN: U22.4, U25.19 (CE)
CLK: U22.2; also elsewhere on the board
GND: C27.2, C28.2, C29.1, C30.2, C31.2, C32.1, C77.1, C78.1, U18.10 (GND), U22.7 (GND), U25.10 (GND), U34.1 (OE), U34.10 (GND), U37.7 (GND), U37.11, U39.7 (GND), U72.10 (GND), U73.10 (GND); also elsewhere on the board
IRB0: U34.2 (O0); also elsewhere on the board
IRB1: U34.5 (O1); also elsewhere on the board
IRB2: U34.6 (O2); also elsewhere on the board
IRB3: U34.9 (O3); also elsewhere on the board
IRB4: U34.12 (O4); also elsewhere on the board
IRB5: U34.15 (O5); also elsewhere on the board
IRB6: U34.16 (O6); also elsewhere on the board
IRB7: U34.19 (O7); also elsewhere on the board
MDR0: U18.2 (O0), U18.3 (D0), U25.18 (B0), U72.18 (B0), U73.18 (B0); also elsewhere on the board
MDR1: U18.4 (D1), U18.5 (O1), U25.17 (B1), U72.17 (B1), U73.17 (B1); also elsewhere on the board
MDR2: U18.6 (O2), U18.7 (D2), U25.16 (B2), U72.16 (B2), U73.16 (B2); also elsewhere on the board
MDR3: U18.8 (D3), U18.9 (O3), U25.15 (B3), U72.15 (B3), U73.15 (B3); also elsewhere on the board
MDR4: U18.12 (O4), U18.13 (D4), U25.14 (B4), U72.14 (B4), U73.14 (B4); also elsewhere on the board
MDR5: U18.14 (D5), U18.15 (O5), U25.13 (B5), U72.13 (B5), U73.13 (B5); also elsewhere on the board
MDR6: U18.16 (O6), U18.17 (D6), U25.12 (B6), U72.12 (B6), U73.12 (B6); also elsewhere on the board
MDR7: U18.18 (D7), U18.19 (O7), U25.11 (B7), U72.11 (B7), U73.11 (B7); also elsewhere on the board
PC0: U72.2 (A0); also elsewhere on the board
PC1: U72.3 (A1); also elsewhere on the board
PC2: U72.4 (A2); also elsewhere on the board
PC3: U72.5 (A3); also elsewhere on the board
PC4: U72.6 (A4); also elsewhere on the board
PC5: U72.7 (A5); also elsewhere on the board
PC6: U72.8 (A6); also elsewhere on the board
PC7: U72.9 (A7); also elsewhere on the board
PC8: U73.2 (A0); also elsewhere on the board
PC9: U73.3 (A1); also elsewhere on the board
PC10: U73.4 (A2); also elsewhere on the board
PC11: U73.5 (A3); also elsewhere on the board
PC12: U73.6 (A4); also elsewhere on the board
PC13: U73.7 (A5); also elsewhere on the board
PC14: U73.8 (A6); also elsewhere on the board
PC15: U73.9 (A7); also elsewhere on the board
RAM_OE_ON: U39.11; also elsewhere on the board
READS_IDLE: U22.11, U37.2, U39.5; also elsewhere on the board
SRC_ACTIVE: U22.5; also elsewhere on the board
W0: U25.2 (A0), U34.3 (D0); also elsewhere on the board
W1: U25.3 (A1), U34.4 (D1); also elsewhere on the board
W2: U25.4 (A2), U34.7 (D2); also elsewhere on the board
W3: U25.5 (A3), U34.8 (D3); also elsewhere on the board
W4: U25.6 (A4), U34.13 (D4); also elsewhere on the board
W5: U25.7 (A5), U34.14 (D5); also elsewhere on the board
W6: U25.8 (A6), U34.17 (D6); also elsewhere on the board
W7: U25.9 (A7), U34.18 (D7); also elsewhere on the board
WRITE_DIR: U37.4; also elsewhere on the board
~ALU_OUT: U39.9; also elsewhere on the board
~IO_RD: U39.10; also elsewhere on the board
~IR_LOAD: U22.3; also elsewhere on the board
~MDR_OUT: U18.1 (OE), U37.5; also elsewhere on the board
~PC_HI_OUT: U73.19 (CE); also elsewhere on the board
~PC_LO_OUT: U72.19 (CE); also elsewhere on the board
~RAM_EN: U22.9; also elsewhere on the board
~RAM_LOAD: U37.3; also elsewhere on the board
~RAM_OUT: U39.2, U39.12; also elsewhere on the board
~ROM_BUF_EN: U37.12; also elsewhere on the board
~ROM_OUT: U22.8, U39.1; also elsewhere on the board
~ROM_SEL: U22.12; also elsewhere on the board

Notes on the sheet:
Memory Data Register
MODULE CONTRACT — generated, do not hand-edit (kicad_contracts.py --stamp) IN: SRC_ACTIVE, ~{ALU_OUT}, ~{IR_LOAD}, ~{MDR_OUT}, ~{PC_HI_OUT}, ~{PC_LO_OUT}, ~{RAM_LOAD}, ~{RAM_OUT}, ~{ROM_OUT} <- Control Word Module IN: ~{IO_RD}, ~{ROM_SEL} <- Memory IN: ~{RAM_EN} <- Memory Address Regiser IN: CLK <-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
Board: 4 copper layers, 179 parts (0 on the bottom side), 350 nets, no tracks yet.

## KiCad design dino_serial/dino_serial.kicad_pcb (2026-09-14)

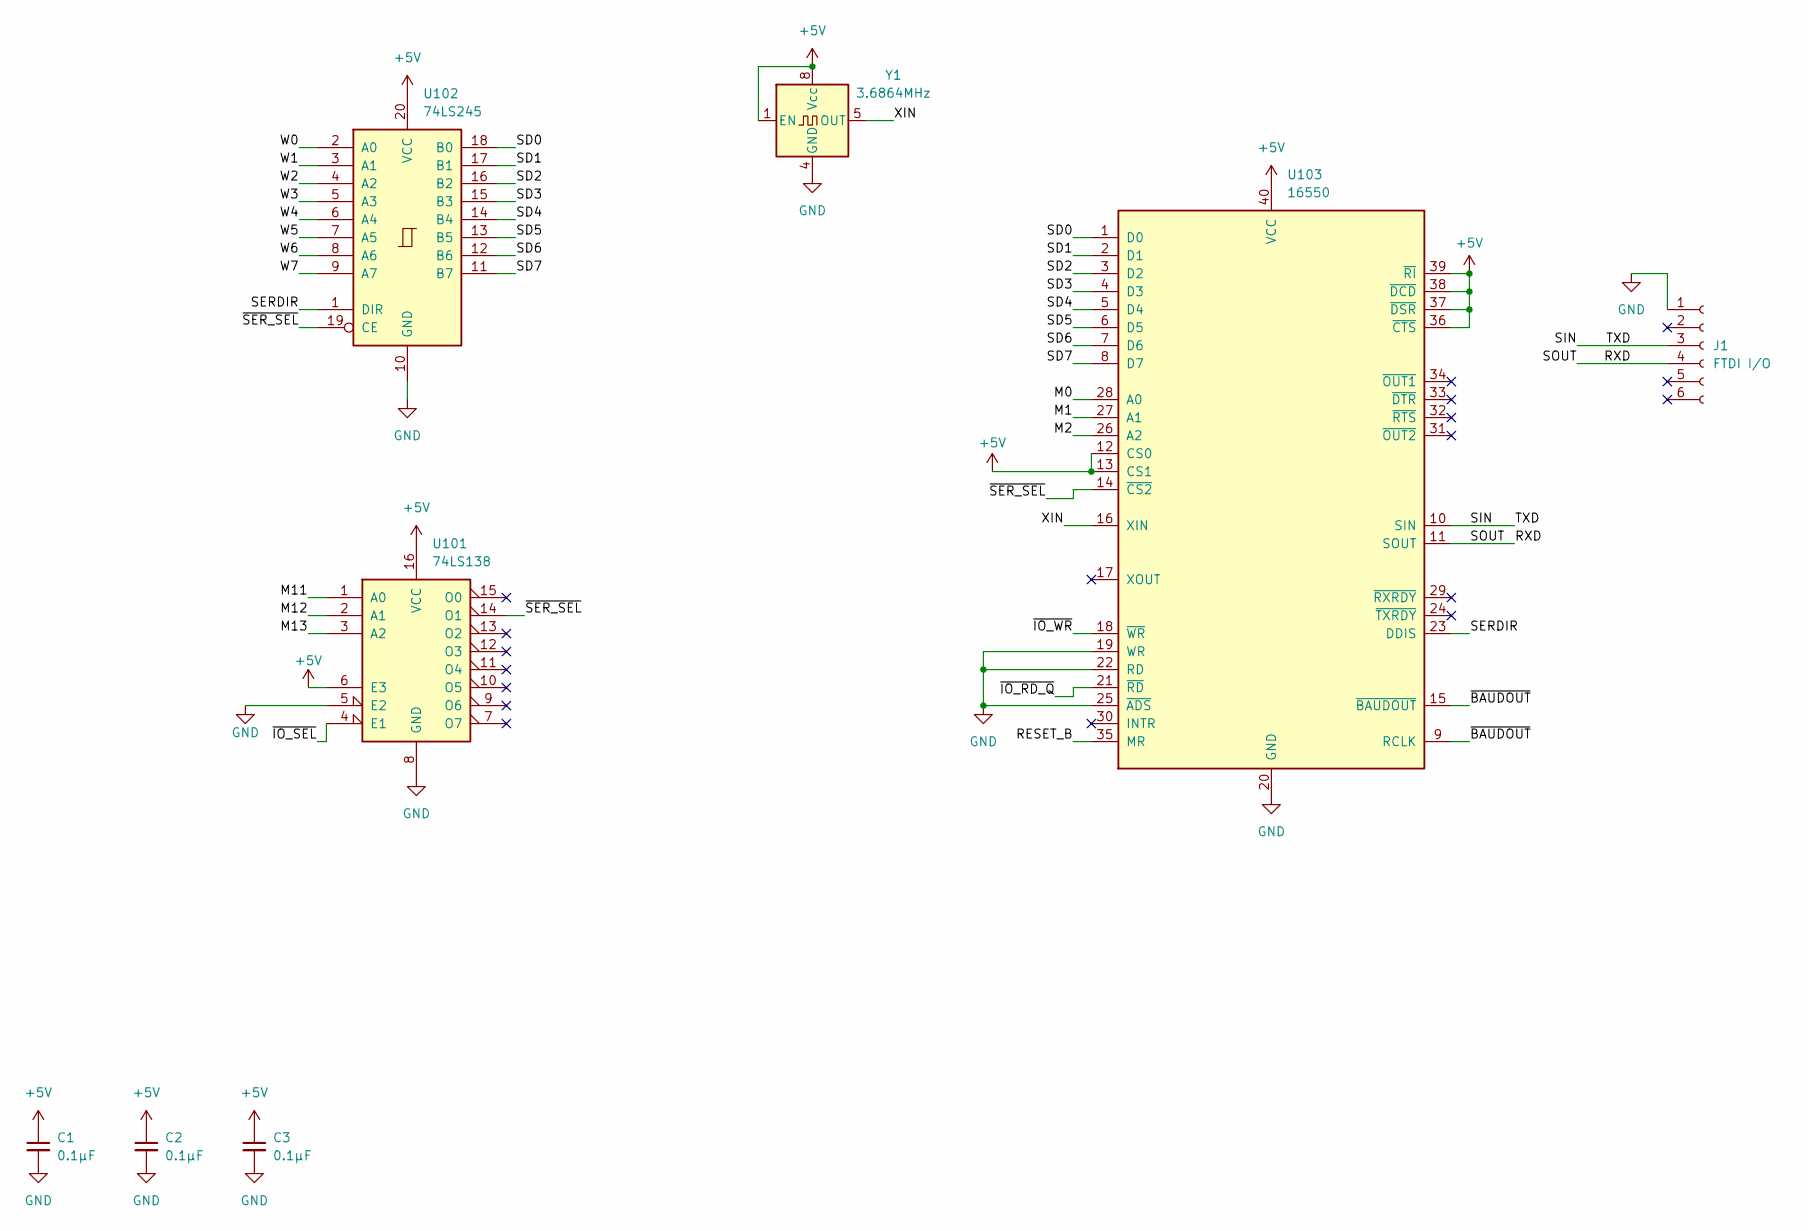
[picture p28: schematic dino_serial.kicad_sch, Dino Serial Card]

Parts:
C1, C2, C3: 0.1µF; C_Disc_D10.0mm_W2.5mm_P5.00mm
J1: FTDI I/O; PinSocket_1x06_P2.54mm_Vertical
U101: 74LS138; DIP-16_W7.62mm
U102: 74LS245; DIP-20_W7.62mm
U103: 16550; DIP-40_W15.24mm
Y1: 3.6864MHz; Oscillator_DIP-8

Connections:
+5V: C1.1, C2.1, C3.1, U101.6 (E3), U101.16 (VCC), U102.20 (VCC), U103.12 (CS0), U103.13 (CS1), U103.36 (~CTS), U103.37 (~DSR), U103.38 (~DCD), U103.39 (~RI), U103.40 (VCC), Y1.1 (EN), Y1.8 (Vcc)
/M0: U103.28 (A0)
/M1: U103.27 (A1)
/M2: U103.26 (A2)
/M11: U101.1 (A0)
/M12: U101.2 (A1)
/M13: U101.3 (A2)
/RESET_B: U103.35 (MR)
/RXD: J1.4, U103.11 (SOUT)
/SD0: U102.18 (B0), U103.1 (D0)
/SD1: U102.17 (B1), U103.2 (D1)
/SD2: U102.16 (B2), U103.3 (D2)
/SD3: U102.15 (B3), U103.4 (D3)
/SD4: U102.14 (B4), U103.5 (D4)
/SD5: U102.13 (B5), U103.6 (D5)
/SD6: U102.12 (B6), U103.7 (D6)
/SD7: U102.11 (B7), U103.8 (D7)
/SERDIR: U102.1 (DIR), U103.23 (DDIS)
/SIN: J1.3, U103.10 (SIN)
/W0: U102.2 (A0)
/W1: U102.3 (A1)
/W2: U102.4 (A2)
/W3: U102.5 (A3)
/W4: U102.6 (A4)
/W5: U102.7 (A5)
/W6: U102.8 (A6)
/W7: U102.9 (A7)
/XIN: U103.16 (XIN), Y1.5 (OUT)
/~BAUDOUT: U103.9 (RCLK), U103.15 (~BAUDOUT)
/~IO_RD_Q: U103.21 (~RD)
/~IO_SEL: U101.4 (E1)
/~IO_WR: U103.18 (~WR)
/~SER_SEL: U101.14 (O1), U102.19 (CE), U103.14 (~CS2)
GND: C1.2, C2.2, C3.2, J1.1, U101.5 (E2), U101.8 (GND), U102.10 (GND), U103.19 (WR), U103.20 (GND), U103.22 (RD), U103.25 (~ADS), Y1.4 (GND)

Board: 2 copper layers, 8 parts (0 on the bottom side), 16 nets, no tracks yet.

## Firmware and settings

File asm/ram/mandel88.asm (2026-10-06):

; mandel88.asm -- the Mandelbrot set in 8.8 fixed point, and it zooms.
; RAM-resident: loaded, not burned.
;
;   load:   make go-mandel88       (asm/ram/mandel88.asm -> RAM via L, then G)
;   check:  python3 docs/notes/test_mandel88.py
;   watch:  make monitor           then type  G 8100  at the prompt
;   stop:   one picture, 33 rows of 80, then RET to the `>` prompt.
;           Ctrl-C under imon; RESET if you cannot wait.
;
; NEEDS THE CARRY MICROCODE (U9 0x4102 U15 0x9BC4 U23 0x8A40, 2026-10-06).
; mandel.asm is the same picture in one-byte 1/32 units, written when there
; was no add-with-carry; it stays as the witness for the old microcode.
;
; ---- THE WINDOW IS IN RAM AND YOU CAN PATCH IT. Four 16-bit cells, low
; byte first, signed 8.8 (1.0 = 0x0100):
;
;     0x811C  CX0   left edge          default -2.0   00 FE
;     0x811E  CY0   top edge           default +1.0   00 01
;     0x8120  DX    step across        default 1/32   08 00
;     0x8122  DY    step down          default 1/16   10 00
;
; cx = CX0 + col*DX, cy = CY0 - row*DY. The default is mandel.asm's grid.
; 8x zoom on the cardioid's edge above elephant valley, from the prompt:
;
;     W 811C,48   W 811D,00   W 811E,90   W 811F,00
;     W 8120,01   W 8122,02                 then  G 8100
;
; The ramp is at 0x8103 as before (25 bytes; W 811B,23 draws inside as '#').
;
; ---- THE ARITHMETIC. Every value is a signed 16-bit 8.8 number; every
; 16-bit add is ADD then ADC, every subtract SUB then SBB. LDA/LDB/LDAI/STA
; hold the flags (U48 lets them change only when the ALU is the source), so
; a carry crosses a load to reach the high byte's ADC.
;
; SQUARES ONLY. 2xy = (x+y)^2 - x^2 - y^2, so no multiply. A square comes
; from one 256-byte table T[l] = floor(l*l/256), built at start: with a
; magnitude n = 256h + l (h <= 3),
;
;     n*n/256 = 256*h*h + 2*h*l + l*l/256
;
; and the first two terms are integers, so floor(n*n/256) is EXACTLY
; 256*h*h + 2*h*l + T[l]. sq adds l 2h times (16-bit, ACI) and h*h into the
; high byte. T is built with a 16-bit running sum, n*n = (n-1)^2 + n + n-1.
;
; One iteration:
;     escape if |x| >= 2 or |y| >= 2         (high byte of the magnitude)
;     X2 = sq|x|, Y2 = sq|y|
;     escape if X2 + Y2 >= 4.0               (high byte of the sum >= 4)
;     y' = sq|x+y| - X2 - Y2 + cy            |x+y| < 4, so h <= 3
;     x' = X2 - Y2 + cx
; Nothing overflows 16 bits: |x'| < 6, |y'| < 10.
;
; RAM. Table at 0x8600-0x86FF, variables at 0x8700-0x871F. Both monitors'
; pages (0x80A0-0x80FF) untouched. Under imon the RDA interrupt can land
; between ADD and ADC: imon's isr starts with PUSHF, so the carry survives.
;
; REGISTER DISCIPLINE, monitor.asm's rules: B is destroyed by every
; immediate-ALU op and by INR/DCR/SHL/NOT; C does not survive a RET.
;
; FIRST-OF-ITS-KIND, listed before the first run (CLAUDE.md rule): ADC,
; SBB and ACI from a RAM program (PROG_carry ran them from ROM, bigxfer runs
; ACI); a carry crossing LDA/LDB/LDAI/STA rows into ADC/SBB/ACI; SBB after
; a SUB whose operands came from RAM; a table page written whole (256
; STAX at 0x8600-0x86FF). Everything else is mandel.asm idiom.
;
; OB counts the rows, as mandel.asm's does.

PUTC:     .equ  0x0345          ; monitor.asm, `make listing-monitor`
CRLF:     .equ  0x036B

MAXIT:    .equ  24
TPAGE:    .equ  0x86            ; T[l] at 0x8600 + l

CX0L:     .equ  0x811C          ; the window, in the program: patch with W
CX0H:     .equ  0x811D
CY0L:     .equ  0x811E
CY0H:     .equ  0x811F
DXL:      .equ  0x8120
DXH:      .equ  0x8121
DYL:      .equ  0x8122
DYH:      .equ  0x8123

CXL:      .equ  0x8700          ; this column's cx
CXH:      .equ  0x8701
CYL:      .equ  0x8702          ; this row's cy
CYH:      .equ  0x8703
XL:       .equ  0x8704          ; z
XH:       .equ  0x8705
YL:       .equ  0x8706
YH:       .equ  0x8707
X2L:      .equ  0x8708          ; x^2
X2H:      .equ  0x8709
Y2L:      .equ  0x870A          ; y^2
Y2H:      .equ  0x870B
NL:       .equ  0x870C          ; sq's argument, a magnitude
NH:       .equ  0x870D
RL:       .equ  0x870E          ; sq's result
RH:       .equ  0x870F
K:        .equ  0x8710          ; sq's loop count
IT:       .equ  0x8711          ; iterations so far
COL:      .equ  0x8712
ROW:      .equ  0x8713
LINES:    .equ  0x8714          ; rows printed, on OB
TL:       .equ  0x8715          ; table builder: l
SQL:      .equ  0x8716          ;   l*l
SQH:      .equ  0x8717
TMP:      .equ  0x8718

          .org  0x8100

          JMP   start
ramp:     .db   "  ..,,::;;--==++**xx%%##@" ; ramp[it], ramp[24] = inside
win:      .db   0x00, 0xFE      ; CX0 -2.0
          .db   0x00, 0x01      ; CY0 +1.0
          .db   0x08, 0x00      ; DX  1/32
          .db   0x10, 0x00      ; DY  1/16
hsq:      .db   0, 1, 4, 9      ; h*h for sq, h = 0..3

; ==== the square table: T[l] = floor(l*l/256) ================================
start:    CLR
          STA   LINES
          STA   TL
          STA   SQL
          STA   SQH
          STA   0x8600          ; T[0]
gen:      LDA   TL
          INR
          STA   TL
          LDB   TL              ; l*l += l
          LDA   SQL
          ADD
          STA   SQL
          LDA   SQH
          ACI   0x00
          STA   SQH
          LDA   TL              ; l*l += l - 1
          DCR
          STA   TMP
          LDB   TMP
          LDA   SQL
          ADD
          STA   SQL
          LDA   SQH
          ACI   0x00
          STA   SQH
          LDA   TL              ; T[l] = the high byte
          MOVCA
          LDBI  TPAGE
          LDA   SQH
          STAX
          LDA   TL
          CPI   0xFF
          JNZ   gen

; ==== the picture ============================================================
          CLR
          STA   ROW
          LDA   CY0L
          STA   CYL
          LDA   CY0H
          STA   CYH
row_loop: CLR
          STA   COL
          LDA   CX0L
          STA   CXL
          LDA   CX0H
          STA   CXH
pix:      CLR                   ; z = 0
          STA   XL
          STA   XH
          STA   YL
          STA   YH
          STA   IT

; ---- X2 = |x|^2, escaping on |x| >= 2
iter:     LDA   XL
          STA   NL
          LDA   XH
          STA   NH
          CPI   0x80
          JNC   x_abs           ; XH < 0x80: x >= 0
          LDAI  0x00            ; N = 0 - x
          LDB   XL
          SUB
          STA   NL
          LDAI  0x00
          LDB   XH
          SBB
          STA   NH
x_abs:    LDA   NH
          CPI   2
          JNC   x_ok
          JMP   esc             ; |x| >= 2
x_ok:     CALL  sq
          LDA   RL
          STA   X2L
          LDA   RH
          STA   X2H
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

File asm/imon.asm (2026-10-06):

; imon.asm -- the INTERRUPT-DRIVEN serial monitor. The polling monitor
; (asm/monitor.asm, PROG_monitor) with its receive path moved onto the
; 16550's received-data interrupt, and a break key. NEVER HALTS.
;
;   build:  make assemble-imon            (asm/imon.asm -> roms/PROG_imon.bin)
;   check:  python3 docs/notes/test_imon.py      <- THE ANSWER KEY
;   talk:   make monitor                  (minicom, 9600 8N1)
;
; Same language, same replies, same host tools as the monitor -- read
; monitor.asm's header for D W O L G. Only the banner differs ("DINO IMON"),
; so the seated ROM names itself. putc, puthex, puts and crlf sit at the
; monitor's ROM addresses (0x0345, 0x02C4, 0x0376, 0x036B), so RAM programs
; built against the monitor (life.asm's PUTC) run unchanged.
;
; WHAT IS NEW
;   * The vector. INT always lands at 0x9090 (in RAM). Every prompt plants
;     JMP isr there, sets IER = RDA (bit 0) and EIs. A G program may plant
;     its own handler; the next prompt takes the vector back.
;   * The receive ring. isr reads RBR (that read is what clears the
;     request) and puts the byte in a 16-byte ring at 0x80A0. getc spins on
;     the ring, not the UART: the CPU still spins, it just never misses a
;     byte while it is busy echoing.
;   * Ctrl-C (0x03) in isr abandons whatever was running: SP back to the
;     monitor's stack, "^C", the prompt. Works at the prompt too.
;
; WHAT A G PROGRAM MUST KNOW
;   * HALT is "wait for a key" here, not a stop (interrupts are on, and a
;     received byte wakes HALT, as PROG_inthalt proved). Ctrl-C from a
;     HALT comes back to the prompt; any other key resumes the program
;     after its HALT and stays in the ring as typed-ahead input. Under the
;     polling monitor a HALT needed RESET.
;   * Take input through getc. Reading RBR yourself races isr.
;   * DI, or your own handler at 0x9090, switches Ctrl-C off until you
;     return. That is allowed; it is your machine for the moment.
;   * 0x80A0-0x80FF is the monitor's: ring, state and stack. RAM programs
;     still start at 0x8100.
;
; isr saves F, A, B and C, so an interrupt is invisible to the program it
; lands in (intflags proved PUSHF/POPF, 2026-10-06). Ring discipline: isr
; only moves RTAIL, getc only moves RHEAD, so neither can corrupt the
; other's index. A full ring drops the new byte.

SER_THR:  .equ  0x4800
SER_RBR:  .equ  0x4800
SER_DLL:  .equ  0x4800
SER_IER:  .equ  0x4801
SER_DLM:  .equ  0x4801
SER_FCR:  .equ  0x4802
SER_LCR:  .equ  0x4803
SER_MCR:  .equ  0x4804
SER_LSR:  .equ  0x4805
VEC:      .equ  0x9090          ; INT lands here; JMP isr is planted

; ---- RAM. THE PROVEN PAGE. Every bench-green image (isa, mem, stack, hello,
; the suite) keeps its cells and its stack inside 0x8000-0x80FF. The first
; burn of this monitor put them at 0xFFE0-0xFFFF -- the first time anything
; drove RAM's A9-A14 -- and the machine streamed garbage to the UART
; (2026-09-04). Whether RAM above 0x80FF works is OPEN and needs its own
; witness image; until it has one, nothing lives up there.
STACK:    .equ  0x80DF          ; PUSH writes at [SP] then decrements;
                                ; down to 0x80B0, above the ring
RING:     .equ  0x80A0          ; 16-byte receive ring, 0x80A0-0x80AF
CMD:      .equ  0x80E0          ; command letter, 0 = none yet this line
ERR:      .equ  0x80E1          ; nonzero = the line is bad, answer `?`
FIELD:    .equ  0x80E2          ; 0 = filling the address, 1 = the value
NDIG:     .equ  0x80E3          ; hex digits seen in the current field
N0:       .equ  0x80E4          ; nibble shift register: N0 newest ...
N1:       .equ  0x80E5
N2:       .equ  0x80E6
N3:       .equ  0x80E7          ; ... N3 oldest
ADRH:     .equ  0x80E8          ; packed address
ADRL:     .equ  0x80E9
VAL:      .equ  0x80EA          ; packed value
CH:       .equ  0x80EB          ; the character being parsed
T_CH:     .equ  0x80EC          ; putc's scratch
T_BYTE:   .equ  0x80ED          ; puthex's scratch
T_CNT:    .equ  0x80EE
PTRH:     .equ  0x80EF          ; puts' string pointer
PTRL:     .equ  0x80F0
CNTH:     .equ  0x80F1          ; L's byte count, 16 bits
CNTL:     .equ  0x80F2
SUM:      .equ  0x80F3          ; L's running 8-bit sum
RHEAD:    .equ  0x80F4          ; next byte getc takes (getc's)
RTAIL:    .equ  0x80F5          ; next free slot (isr's)
T_RX:     .equ  0x80F6          ; isr's scratch: the byte
T_NX:     .equ  0x80F7          ; isr's scratch: the next tail
T_GC:     .equ  0x80F8          ; getc's scratch

          .org  0x0000

          LDAI  0xFF            ; poison OB
          OUT
          LXISP STACK

; ---- UART init, PROG_serrx verbatim: 9600 8N1, FIFO on, MCR = 0
          LDAI  0x83
          STA   SER_LCR
          LDAI  0x18
          STA   SER_DLL
          LDAI  0x00
          STA   SER_DLM
          LDAI  0x03
          STA   SER_LCR
          LDAI  0x07
          STA   SER_FCR
          CALL  boot_ext        ; IER = 0, MCR = 0, the ring empty

          MVI   PTRL, <s_banner
          MVI   PTRH, >s_banner
          CALL  puts

; ==== a new line: clear the parse state, prompt ============================
new_line: CALL  ints_on         ; vector, IER = RDA, EI
          CLR
          STA   CMD
          STA   ERR
          STA   FIELD
          STA   NDIG
          STA   N0
          STA   N1
          STA   N2
          STA   N3
          MVI   PTRL, <s_prompt
          MVI   PTRH, >s_prompt
          CALL  puts

; ==== one character ========================================================
next_ch:  CALL  getc
          CPI   0x0A            ; LF: swallowed, not echoed
          JNZ   not_lf
          JMP   next_ch
not_lf:   CPI   0x0D            ; CR: the line is complete
          JNZ   not_cr
          JMP   do_line
not_cr:   CALL  putc            ; echo. putc returns with A intact
          STA   CH

          LDA   CMD
          CPI   0
          JNZ   have_cmd
; ---- no command letter yet: skip blanks, take the first other character
          LDA   CH
          CPI   ' '
          JNZ   set_cmd
          JMP   next_ch
set_cmd:  CPI   'a'             ; fold lower case: 'a'.. -> 'A'..
          JNC   store_cmd       ; A < 'a', leave it
          SUI   0x20
store_cmd: STA  CMD
          JMP   next_ch
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

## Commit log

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2025-06-23 Removes redundant GND label and updates UUIDs
    Eliminates duplicate GND label entry to avoid confusion.
    Updates UUIDs across multiple pins for consistency and accuracy.
    Renames and reorganizes documentation files to improve clarity.
    Removes outdated temporary document files.
    Improves document organization and maintains schematic integrity.
    [dino_v0_0_1.kicad_sch]
2025-06-23 Updates schematic connections and increments revision
    Adjusts various schematic wire and bus connections for improved accuracy and clarity, removes obsolete bus entries, and adds new GND label and connection points. Increments schematic revision to v1.0.1. Replaces outdated PDF with updated version and resets project plot directory setting.
    Enhances maintainability and correctness of the design.
    [dino_v0_0_1.kicad_sch, input_output.kicad_sch]
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2025-06-24 Adds wiring and debug notes for initial DINO bring-up
    Documents power, timer, LED, reset, and program counter wiring
    and debug practices for DINO v0.0.1. Provides tested
    troubleshooting steps and recommendations for validation and
    next steps in prototype verification.
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2025-06-24 Improves wiring summary and debugging details
    Clarifies wiring setup for Program Counter stages and resolves
    previous output freezing issue by ensuring RCK is tied to CCK.
    Adds LED output testing details and measured frequency
    observations for better subsystem monitoring.
    Enhances chaining validation process for accurate counting.
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2025-06-30 Updates schematic with corrections
    - Corrects ~CE on 74LS645
    - Fixes MCM60256AP DQ6 Pin Number
    - Removes "Net Label" for +5V and adds correct text label
    - Attaches both GND and VCC to bus proper
    [dino_v0_0_1.kicad_sch, input_output.kicad_sch]
2025-07-01 Unifies SPI data to 8-bit, MSB-first across modules
    Refactors both firmware and ESP host to use SPI 8-bit data size and MSB-first format, ensuring compatibility between microcontroller and receiver. Updates SPI DMA alignment and payload byte packing/unpacking throughout the codebase. Simplifies SPI send interface and adapts receiver dataflow to avoid unnecessary endianness conversions.
    Ensures consistent SPI transactions and prevents data misinterpretation due to size and endianness mismatches.
2025-07-02 Updates schematic for DIP switch change
    Replaces 7x DIP switch with 8x DIP switch in schematic.
    Modifies connection points and properties accordingly.
    Adjusts bus and wire entries for compatibility.
    [input_output.kicad_sch]
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2025-08-19 Memory Register Module Update
    With some previous learnings on the 74LS121, the MDR Module has been re-sketched to better trigger the '121 and create an intra phase latch. This should allow the data bus to stabilize before the the register's latch the data.
    [mdr.kicad_sch, memory.kicad_sch]
2025-08-22 Updates microcontroller schematic from 74LS73 to 74LS74
    Replaces 74LS73 JK flip-flop components with 74LS74 D flip-flops
    for improved synchronization in the circuit. Adjusts pin
    mappings accordingly and updates datasheets and descriptions.
    Removes auto-saved schematic file.
    Adds capacitor and resistor components to the schematic for
    circuit completion. Includes new images and documentation for
    reference.
    [mdr.kicad_sch]
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2025-08-24 Refactors Arduino and Pico projects for flexible testing
    - Replaces hardcoded Arduino blink example with a more modular test framework supporting multiple hardware tests via compile-time flags
    - Adds comprehensive guide and updated CMake configuration for AVR development and flexible test selection
    - Implements 74LS373 latch self-test for Arduino with robust data bus validation
    - Updates Pico CMake and blink example for USB stdio and onboard LED, improving debug and portability
    - Adjusts environment and build scripts for updated hardware ports
    Enables more scalable hardware validation workflows and improved maintainability.
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2025-08-24 Removes unused hex file and updates bus initialization
    Deletes an obsolete test hex file to clean up test resources.
    Replaces a function call with explicit pin configuration in the bus
    initialization function for improved clarity and control.
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2025-08-24 Schematic Updates
    - Flipped 74LS245 Bus Transceivers on Register modules
    [mdr.kicad_sch, registers_a_b.kicad_sch, registers_c_out.kicad_sch]
2025-08-24 Refactors IR test for logic analyzer-based verification
    - Updates test logic to support external observation via logic analyzer
    - Removes readback checks and dependence on Arduino bus for verification
    - Clarifies that 373 Q outputs go to the decoder, not back to the bus
    - Modifies wiring tables, comments, and documentation accordingly
    - Demonstrates reset override explicitly in analyzer waveform
    Facilitates more accurate hardware validation of instruction register behavior.
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2025-08-30 KiCAD Update
    - Fixed Pins to match hardware
    - Fixed DIR on '245 Pair for Reg A+B
    [registers_a_b.kicad_sch]
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2026-07-14 DINO v0.0.3: complete ALU/control-word, add MAR+reset sheets, wire reset circuit
    ALU sheet: flags register moved from '173 (not in stock) to '273 + a '157
    mux to emulate the missing load-enable pins; Z-detect built from a NOR+AND
    De Morgan tree instead of a '260; ALU_CIN built from NAND(SA1,SA0) reusing
    two already-placed spare gates instead of a dedicated XOR/'86. Sheet is
    now fully wired and netlist-clean.
    Control word sheet: all 16 CW bits assigned and wired (3x '138 decoders
    for the load/source/misc fields, direct bus taps for HALT/PC_MAR_MUX/
    PC_UP/END and the ALU SA[2:0] select). Found and fixed several cross-
    sheet signal-name mismatches this uncovered (OUT_REG_LOAD/REG_OUT_LOAD,
    PC_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
    [PDIP20_26P42X6P6_ONS.stl, alu.kicad_sch, control_word.kicad_sch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]
2026-07-14 Close out session: reset circuit confirmed complete, MAR is next
    Final full netlist sweep confirms reset.kicad_sch's replacement (built
    directly on the root sheet: RC+button+74HC14 -> U27B sync -> flags/
    T-state-counter/PC-clear fan-out) is wired correctly with zero floating
    pins. Deprecated the now-orphaned standalone reset.kicad_sch (superseded
    by the root-sheet version, matches the existing archival pattern for
    unreferenced sheets).
    Rewrote dino_session_state.md as a clean handoff: reset circuit and
    control word moved from TODO to DONE, MAR sheet (stub parts placed,
    unwired) is now explicitly next, and flagged that
    dino_cpu_testing_strategy.md needs a rewrite before it's usable (it
    descr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
    [reset.kicad_sch]
2026-07-14 feat(dino): complete v0.0.3 schematic — all 11 sheets netlist-clean
    - wire MAR sheet: '373 LO/HI latches, 2x '245 M-bus drive, A15 decode
    (ROM_EN/~RAM_EN), LE stamps off /MAR_LO_LOAD//MAR_HI_LOAD
    - fix PC_MAR_MUX polarity: PC '245s enabled on bit14=0, inverted vs
    bit-map convention (PC=1); add ~PC_MAR_MUX inverter, relabel U13/U14
    - wire all 7 control-word bus taps [15:9] (SA0-2, END, PC_UP,
    PC_MAR_MUX, HALT) — label pairs had no wire between them
    - untie NONE/NC '138 outputs: totem-pole bus fight on every microword;
    each unused output now individually no_connect
    - build END (U61 NOR: ~MR = RESET|END, sync T-state clear) and HALT
    (T-state freeze via CET, clock keeps running)
    -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
    [alu.kicad_sch, control_word.kicad_sch, dino_v0_0_2.kicad_sch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]
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2026-07-14 fix(dino): three review-found schematic bugs on microcode/memory
    - microcode U9/U15: ~WE tied +5V, A12 tied GND (were floating with NC
    flags — in-circuit corruption + image-aliasing hazard on AT28C64B)
    - memory: label the U24.~OE/U19.CE net ~{ROM_OUT} — the ROM read path
    had no driver as drawn (caught by new kicad_netlist.py --lint)
    - memory: U21 (RAM-side '245) CE now AND(~RAM_OUT, ~WRITE_DIR) via U51
    spare gates — was enabled by ~RAM_EN alone, buffering floating RAM DQ
    onto MDR against register drivers whenever MAR parked on a RAM
    address with no RAM op in flight
    Contracts restamped; all verified in kicad_netlist.py + kicad-cli
    export; lint clean project-wide.
    [alu.kicad_sch, control_word.kicad_sch, input_output.kicad_sch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]
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2026-07-15 refactor(dino): schematic cleanup pass — real rail wires, tidied layout
    GUI pass over all 11 sheets: script-placed stacked power symbols
    replaced with proper wires to the rails (~33 symbols out, ~46 wires
    in), input_output LED/resistor bank repositioned, memory-sheet
    RAM_MDR_EN gating labels re-placed on the redrawn wiring (same nets,
    same names). KiCad save-format normalization included. Full-hierarchy
    PDF export added.
    [alu.kicad_sch, control_word.kicad_sch, dino_v0_0_2.kicad_sch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]
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2026-08-11 fix(schematic): declare matching label sets so aliased nets stay one net
    Three board-to-board wires were absent from the generated continuity
    checklist, which is the only coverage the netlist->copper step has. A wire
    missing from that list is driven by no test and sampled by no test -- the
    MAR-lo post-mortem in one sentence.
    Cause: cross-sheet connectivity in this design is a naming convention (all
    labels are sheet-local; KiCad joins nothing between sheets). kicad_netlist
    keys a net on its full label set, joined. When one sheet carries an alias and
    another doesn't, the same physical wire gets two keys, both look single-sheet,
    and continuity_checklist's cross-sheet filter drops the whole net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
    [memory.kicad_sch, microcode.kicad_sch, program_counter.kicad_sch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]
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2026-08-23 schematic: join five aliased nets, and ledger the root-sheet gap
    FIVE LIVE WIRES WERE IN THE CHECKLIST'S NO-CONNECT BUCKET, under the
    heading "nothing to land and nothing to beep against."
    CW9/SA2 U15.12 <-> U38.7, U40.7
    CW10/SA1 U15.13 <-> U38.6, U40.6, U53.12
    CW11/SA0 U15.15 <-> U38.5, U40.5, U53.13
    CW13/PC_UP U15.17 <-> U36.1
    CW14/PC_MAR_MUX U15.18 <-> U54.19, U59.19, U60.11, U60.12
    The microcode sheet labelled each net CWnn; the consumer sheet labelled it
    SA2 / PC_UP / PC_MAR_MUX. Two label sets, two net keys, both look
    sheet-local, and the cross-sheet filter drops the wire -- the M15/ROM_EN
    failure, five more times.
    alias_split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
    [alu.kicad_sch, mar.kicad_sch, microcode.kicad_sch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]
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2026-08-24 feat: phase C on silicon — CALL and RET execute
    The whole ISA now runs on hardware except LDCI and NOP, and those are
    microcode-soft rather than missing silicon: C is write-only (RET's scratch)
    and nothing can read it back. MOV A,C or PUSHC/POPC retires them for one
    three-ROM burn.
    calladdr 0x5C callraw 0x2A call 0x4B stack 0x27
    PHASE C COST NO ROM BURN. CALL 0x33 and RET 0x34 were already in the
    sockets -- decoded out of roms/U9.bin+U15.bin+U23.bin, 12 and 14 rows, zero
    differing from the generator. It was two '245s and wire.
    THE FAULT WAS A WRONG TAP, NOT A WRONG WIRE. U72/U73 first went onto
    U11/U12 -- the PC LOAD path, whose B side is PCD0-15 feeding the counters'
    DATA inp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
    [alu.kicad_sch, dino_serial.kicad_pcb, dino_serial.kicad_sch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]
2026-08-25 feat: phase D on silicon — the machine executes from RAM
    PROG_ramexec returns 0x6E. The PC has been above 0x7FFF and FETCH_RAM has
    been high, both for the first time in this machine's life.
    The missing condition was never "is this a fetch." ~ROM_OUT is asserted for
    every src=ROM — opcode fetch, LDAI's immediate, LDA/STA/JMP/CALL operand
    bytes — so an instruction living in RAM must read its operands from RAM
    too. The condition is "a ROM-side read was requested, but the address is
    above 0x7FFF":
    FETCH_RAM = NOR(~ROM_OUT, ~RAM_EN)
    Six gate sections, no new IC. All six were free on U22/U37/U39, already in
    sockets on the MDR board, where ~ROM_OUT and ~RAM_OUT already sit feeding
    READ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
    [alu.kicad_sch, control_word.kicad_sch, dino_v0_0_2.kicad_sch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]
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2026-08-25 feat: phase E step A -- the 16K I/O window, in schematic
    Carves 0x4000-0x7FFF out of ROM space and publishes a bus. The ROM now
    answers 0x0000-0x3FFF only; the window decodes to no core chip, so W
    reads its park -- 0xFF, which is HALT.
    TWO NEW PACKAGES, both on the memory board:
    U74 '00 ~{M14} = NAND(M14, M14)
    ~{ROM_SEL} = NAND(~{RAM_EN}, ~{M14})
    ~{RAM_OE_G} = NAND(RAM_OE_ON, M15)
    ~{IO_SEL} = NAND(~{RAM_EN}, M14)
    U75 '32 ~{IO_RD} = OR(~{IO_SEL}, READS_IDLE)
    ~{IO_WR} = OR(~{IO_SEL}, ~{RAM_WRITE_EN})
    RESET_B = OR(RESET, GND)
    ~{IO_RD_Q} = OR(~{IO_RD}, CLK)
    Eight copper changes: U24.20 and U22.12 to ~{R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
    [alu.kicad_sch, control_word.kicad_sch, dino_v0_0_2.kicad_sch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]
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2026-09-02 feat: Phase F/F+ ISA: 174 instructions, timing fixes, and robust tooling
    This commit integrates Phase F and F+ of the ISA, expanding the instruction set to 174 instructions. This includes:
    - New conditional branch `JNC`, register-to-register moves, SP/PC readbacks and manipulation (HLSP/SPHL, INXSP/DCXSP).
    - Indexed memory access (LDAX/STAX), SP-relative memory access (LDAS/STAS), and memory-indirect addressing (LDAM/STAM/JMPM, etc.) as a new addressing mode.
    - Immediate ALU operations (ADI, SUI, ANI, etc.) and ALU results directly to B/C or memory.
    - Compare-only instructions (CMP, TST).
    - The `IN` opcode has been fully retired from the ISA as of 2026-08-27, and `0x00` confirmed as `NOP`.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
    [alu.kicad_sch, control_word.kicad_sch, dino_v0_0_2.kicad_sch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]
2026-09-05 feat: phase G on silicon -- serial card, 9600 8N1, echo proven
    The PC16550D card (U101 '138, U102 '245, U103, dino_serial/) runs on the
    bench. Every step-4..8 witness passed 2026-09-04: serid 0x55, serid_aa
    0xAA, serlsr 0x60, seriir 0xC1, serbaud 153.6 kHz on U103.15, serloop
    0x53, sertx "DINO" on the host terminal, serrx echoing a typed character
    on OB and back to the host. The data bus is PROVEN, not narrowed: a
    receiver DINO does not control decoded it.
    Two bench faults found and fixed on the way, both copper, neither
    visible to --continuity:
    - the card's ~WR was on U75.5 (an input) instead of U75.6; ~{IO_WR}
    now feeds a real consumer for the first time.
    - C1 was 1uF in the socke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
    [dino_serial.kicad_sch, dino_v0_0_2.kicad_sch]
2026-09-06 feat: phase G_0 on silicon -- ROM readable as data, monitor runs its session
    Three re-sourced pins make ROM readable as data (PROG_test3 0x4D, romsoak
    0x00 over 65536 reads). The monitor then runs the session from the ask:
    D 0000 -> 0x11, W FF00,99 -> 0x99, D FF00 -> 0x99, O FF00 on OB.
    Four faults sat between the copper and that session, all fixed, all in
    .git/sdd/PHASE_G_0.md RESULTS:
    1. U15 (microcode EEPROM, CW8-15) pulsed END on its own for ~25ns with a
    static address, clean rails and ~OE/~CE low, locked to no clock in the
    machine. U61 turned it into ~MR low, U6 cleared T under HALT, and the
    byte behind the HALT ran. Every "HALT escape" ever recorded was this.
    Chip replace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
    [mdr.kicad_sch, memory.kicad_sch]
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2026-09-07 feat: txlive witness and .fill directive; the post-HALT flood was the RESET wire's route
    asm/txlive.asm puts (IIR&0xC0)|LCR on OB every byte through the monitor's
    TX path and read 0x00 at the garble: the 16550 was being MR'd. A scope on
    U103.35 found a ~1.5V/10ns runt on RESET picked up along the bundle; pulling
    the wire out cured it with no caps. T0 22pF is OUT, U9/U15 were fine.
    asm.py gains .fill (Rico's A/B of the fill byte), sertx00 is the silence
    witness, and roms_readme_gen uses the image's own fill for its CRC.
    Claude-Session: https://claude.ai/code/session_01VtMoQkXfGj8fopqBKhmXJq
    [txlive.asm]
2026-09-07 feat: monitor L (hex load, sum-checked) and G (CALL/RET) plus dinoload.py
    L addr,len takes 2*len hex digits, echoed, whitespace skipped, and answers
    the 8-bit sum of what STAX landed. G addr CALLs through `go: LDB ADRH;
    LDC ADRL; JMPX`, so a RET returns to the prompt and a HALT stays halted.
    docs/notes/dinoload.py assembles an .asm, sends the L line and the hex in
    16-digit chunks with each echo checked, then leaves you to type G at
    minicom (`make load-hello`; `--go` sends it). RAM programs live in
    asm/ram/, .org 0x8100, outside the assemble-% wildcard. test_dinoload.py
    drives the loader against the real monitor image through simulate().
    PROG_monitor.bin crc 0xD0E1, 936 bytes.
    Co-Authored-By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
    [monitor.asm]
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2026-09-13 feat(pcb): place and route the mainboard, 299x223 2-layer
    Draft was 374x524 with nothing routed. Placement by simulated annealing
    over a DIP cell grid (HPWL, clock weighted), then hand-trimmed: LEDs and
    their 330R leave the board for an OB header J11, W park resistors sit at
    the slot-column end, slots J1-J8 respaced to 20.32 mm. Freerouting 2.4.1
    on KiCad's own DSN export with the netclasses (Default 0.25, PWR 1.0,
    CLK 0.3); GND pours both layers plus router-placed GND bridges. kicad-cli
    DRC: 0 unconnected, 0 clearance, 0 shorts; 38 starved-thermal (per-layer
    check) and silk warnings remain.
    docs/notes/test_pcb_envelope.py enforces the card-edge mechanics against
    the saved board: 8 slots in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
    [dino_v0_0_2.dsn, dino_v0_0_2.kicad_pcb, dino_v0_0_2.kicad_sch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]
2026-09-14 feat(pcb): started PCB — mainboard DRC clean, placer tools, serial card footprints
    Mainboard (dino_v0_0_2): GND zones on both layers re-parameterised to
    0.25 mm clearance / 0.2 mm min width so the pour threads the channels
    the router spaced for 0.25 mm tracks; 43 GND jump vias and one F.Cu
    rule area (J6 pad 50) clear the starved-thermal reports. kicad-cli DRC:
    0 unconnected, 0 clearance, 0 shorts; silk warnings only. Project zone
    defaults and via size follow.
    docs/notes/pcb_tools: the placement scripts from the 2026-09-12 layout
    session (anneal.py simulated-annealing cell placer, hpwl.py, report.py,
    place_sheetrows.py), promoted verbatim from a session scratchpad so the
    DMA/INT re-shuffle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
    [dino_serial.kicad_pcb, dino_serial.kicad_sch, dino_v0_0_2.kicad_pcb]
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2026-09-25 feat(int): interrupt microcode, oracle, tests and bench images
    Maskable interrupt per .git/sdd/PHASE_INT.md (supersedes PROPOSAL_INT's
    mechanism). Host-green; nothing burned, nothing built.
    - Opcodes 0x90-0x95: INT (injected only), IRET, EI, DI, PUSHF, POPF.
    K = 0x90, vector K:K = 0x9090 in RAM (soft: plant JMP handler there).
    - New decoder codes on the NC outputs: SRC KONST/FLAGS (U70 O4/O5),
    DST FLAGS/IE_SET/IE_CLR (U71 O2-O4).
    - IRET parks the return LO byte in the PC, not C (RET's C park would
    clobber the interrupted program). INT clears IE in microcode. POPF
    reads twice before loading U49 mid-state.
    - Every existing row unchanged: CRC 0x8007 over the 250 old opcode
    blocks. Ne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
    [inthalt.asm]
2026-09-29 feat(int,load): UART THRE as the only interrupt source; loader names the byte
    Interrupt images reworked for a machine with no button and no 555: the
    16550's THRE interrupt is the only source and each image arms it itself.
    intbtn becomes intresume; inthalt gains a SEEN check (0x3C = woke with no
    handler). Images regenerated, keys in test_intimages.py.
    dinoload payload errors now name the absolute address of the byte that
    failed (e.g. "char 51 (byte 0x8139, digit 1)"), so a failure in row 10
    can be told from one in row 1.
    Claude-Session: https://claude.ai/code/session_01AUmoZpzaetAKis7XQX3WiS
    [inthalt.asm]
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2026-09-29 fix(copper): gate the RAM write strobe off in T-state 0; RAM-fetch halt closed
    A RET fetched from RAM latched 0xFF. Scope work on 2026-09-29 found the
    cause: the FETCH row's transparent IR moves the microcode EEPROM address
    during CLK-low, the DST decoder (U30.7, code 111 = ~RAM_LOAD) runts for
    14-16 ns on some opcode transitions, and NAND(WRITE_DIR, ~CLK) is open
    then. The RAM got a 14 ns ~WE at PC's address; the cell survived, the
    chip's read output did not, and IR latched 0xFF. From ROM the same runt
    is harmless (M15 = 0). The same runt reached ~IO_WR and wrote 0x00 into
    [MAR] at every RESET.
    Fix: ~RAM_WRITE_EN = NAND(WRITE_DIR, WR_GATE), WR_GATE = NOR(CLK, ~TO0)
    on U62 g4, with U56 3->4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
    [control_word.kicad_sch, dino_v0_0_2.kicad_sch, memory.kicad_sch]
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2026-09-30 feat(int): draw the interrupt block; sheet cleanup pass
    New sheet dino_v0_0_2/interrupt.kicad_sch (page 15): U80-U87, R28 4.7k
    pull-up on ~{IRQ}, R29 100R on the block's CLK branch, C83-C90. Every
    pin per PHASE_INT SECTION 3, checked against the plan with kicad_netlist
    and kicad-cli (146 pins, 0 mismatches).
    Old sheets (SECTION 3.2): U28.4 lifted off GND to INJECT; U61.3 to
    END_OR_ACCEPT; U36.1 to PC_UP_GATED; U49 D0-3 cut from U48 Za-Zd and
    routed through U87 as FLAG_NEXT0-3 / FLAG_D0-3; FLAG_C/Z/V/N and the
    five decoder outputs made global. dino_serial: U104 74LS05, INTR ->
    ~{IRQ}, C4.
    Placement pass on every sheet: bus entries and global labels no longer
    share wires; M, CW, T, IRB and S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
    [alu.kicad_sch, control_word.kicad_sch, dino_serial.kicad_sch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]
2026-10-01 fix(serial): U104 open-collector inverter is a 7406N, not a 74LS05
    No '05 on hand; the '06 is pin-identical (KiCad's 74LS06 extends
    74LS05). Netlist identical, ERC unchanged. The 7406N is standard
    TTL: INTR sees one full TTL load, ICC up to ~50 mA vs ~6 mA.
    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
    [dino_serial.kicad_sch]
2026-10-06 feat(int): ALU latch race fixed, interrupt ladder passes, PROG_imon
    The I0 failure after the interrupt build was a same-edge race: U47 (ALU
    output '373) took raw CLK at the end of the ALU jumper and closed late
    while TMP_A opened on the same CLK fall, so ALU->A rows latched part of
    the next result. U47's LE now comes from ~CLK through U37 inverter 5
    (net CLK_ALU, mdr + alu sheets, ERC no new violations).
    With U104 and the ~IRQ jumper wired, every rung of PHASE_INT section 4
    passes at 1.024 MHz. New images: intcount (I3 read off the terminal),
    intaddrsw (I4 with SW1 sliding the THRE window), and PROG_imon, the
    monitor with input on the RDA interrupt, a 16-byte ring and Ctrl-C
    break; putc/put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
    [DSLogic PLus-la-261006-084216.csv, DSLogic PLus-la-261006-085403.csv, DSLogic PLus-la-261006-090636.csv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]
2026-10-06 feat(alu): ADC/SBB/ACI/SBI through U76, carry microcode burned
    U76 ('157, ALU board) picks the '382's CN: S <- CW16 (U23.11),
    I0a <- FLAG_C (U49.2), I1a <- ALU_CIN (U50.13), Za -> ALU_CN (U38.15).
    CW16 is low only on the ALU rows of 0x96 ADC, 0x97 SBB, 0x98 ACI,
    0x99 SBI; check_word refuses it off src=ALU or on a logic code, and the
    oracle refuses a carry left by a logic op.
    Microcode U9 0x4102 U15 0x9BC4 U23 0x8A40; every row outside 0x96-0x99
    is byte-identical to the 0x0C0A interrupt image (test_carry pins it).
    PROG_carry (0xCA1F) runs 12 subtests x 256 passes, OB 0xAD.
    Bench 2026-10-06, 1.024 MHz on U20.14: with the old microcode isa 0xB4,
    isasoak 0x00 x10 (after U76.15 was found loose: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
    [alu.kicad_sch]
2026-10-06 feat(ram): mandel88 in 8.8 fixed point, bigxfer sums with ACI
    mandel88.asm: 16-bit signed 8.8 throughout, ADD/ADC and SUB/SBB pairs.
    Squares only (2xy = (x+y)^2 - x^2 - y^2), each exact from a 256-byte
    table T[l] = floor(l*l/256). The window is four patchable RAM cells at
    0x811C. Bench: default and 8x zoom both 22 s at 1.024 MHz, pictures
    match the oracle on the rows checked.
    bigxfer.asm: the 16-bit checksum is ADD then ACI 0, no branch.
    [mandel88.asm]
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
